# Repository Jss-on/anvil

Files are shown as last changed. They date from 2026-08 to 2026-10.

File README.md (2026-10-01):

# Anvil

**Hardware product development with explicit release gates and revision-bound evidence.**
Version **0.6.0** · Claude Code and Codex plugins · Proprietary license

Anvil carries a product from requirements and architecture through PCB fabrication, firmware,
mechanics, integration, EVT/DVT/PVT, market release, support and retirement. Its commands perform
authorized engineering work and keep missing external tests or approvals visible as blockers.

```mermaid
flowchart LR
  G0["G0 Opportunity"] --> G1["G1 Requirements"] --> G2["G2 Architecture"]
  G2 --> G3["G3 Prototype release"] --> G4["G4 EVT"] --> G5["G5 DVT"]
  G5 --> G6["G6 PVT"] --> G7["G7 Market release"] --> S["Support and retirement"]
  S -->|Controlled changes| G2
```

Electronics, firmware/services, mechanics, supply/manufacturing, quality/compliance and commercial
work proceed concurrently. The [lifecycle protocol](.claude/skills/anvil/references/lifecycle-protocol.md)
defines gates, owners, artifacts and checklists. The [research report](research/hardware-product-lifecycle.md)
and [original assessment](ASSESSMENT.md) explain the upgrade's basis.

## Use with Claude Code

Install the repository's marketplace in Claude Code, then its `anvil` plugin:

```text
/plugin marketplace add Jss-on/anvil
/plugin install anvil@anvil
```

For local development, load the actual packaged directory with `claude --plugin-dir ./claude-plugin`.
The repository's canonical command and skill files also support project-local development.
Do not assume editing this checkout changes an already cached installation; reload the local
plugin or update the installed package after publishing an authorized release.

| Command | Purpose |
|---|---|
| `/anvil` | Bounded custom metric loop or task routing |
| `/anvil:requirements` | Requirements, methods, owners, verification gates and applicability |
| `/anvil:build` | Concurrent product development, default target G3 |
| `/anvil:lifecycle` | Bring-up, EVT/DVT/PVT, market release and sustaining |
| `/anvil:improve` | Cost/area/mass/margin optimization with non-regression checks |
| `/anvil:evals` | Run analysis and evidence/gate review |

Examples:

```text
/anvil:build Goal: battery-powered environmental monitor Release: product Target: G3
/anvil:lifecycle Scope: ./sensor Target: G5 Action: execute
/anvil:improve Metric: bom_cost Scope: ./sensor Iterations: 10
```

## Use with Codex

Install and sign in using the [official Codex CLI setup](https://learn.chatgpt.com/docs/codex/cli).
Install Anvil's engineering tools under [Run the checks directly](#run-the-checks-directly).
From this checkout, register its local marketplace and install the native Codex plugin:

```sh
codex plugin marketplace add .
codex plugin add anvil@anvil
codex -C . --sandbox workspace-write
```

The [Codex marketplace](.agents/plugins/marketplace.json) selects the self-contained package
in [`plugins/anvil/`](plugins/anvil/.codex-plugin/plugin.json). Codex loads its `$anvil` skill;
Claude Code uses the separate marketplace and package above. This follows Codex's
[native plugin and marketplace format](https://learn.chatgpt.com/docs/enterprise/plugin-management).

Start a **new thread** after installation. In Codex CLI or the IDE extension, type `$` to select
Anvil, or paste a prompt such as:

```text
$anvil build Goal: battery-powered environmental monitor Scope: ./build-output/sensor Release: product Target: G3
$anvil lifecycle Scope: ./build-output/sensor Target: G5 Action: review
$anvil improve Metric: bom_cost Scope: ./build-output/sensor Iterations: 10
```

Send one prompt at a time. The skill also routes `requirements`, `evals`, and custom metric
loops. All six workflows use the same engineering protocols, Python checks, receipts and gates
as the Claude Code plugin. In the Codex app, select Anvil and describe the task in a new thread.

To work in an existing hardware repository, launch `codex -C <project-directory>` and use
`Scope: .`; installed Anvil tools resolve from the plugin cache. When working in this checkout,
`build-output/sensor` is ignored by Git; maintain the product's own source history and release
archive. Keep project outputs outside the plugin cache.

For a noninteractive review of an existing project, use single quotes so PowerShell and Bash
preserve the `$anvil` skill mention. See the [Codex CLI reference](https://learn.chatgpt.com/docs/developer-commands?surface=cli).

```sh
codex exec -C . --sandbox workspace-write 'Use $anvil lifecycle Scope: ./build-output/sensor Target: G3 Action: review. Report the actual gate result and blockers.'
```

For development without installation, open this checkout and ask Codex to read
`.claude/skills/anvil/SKILL.md` and the desired `.claude/commands/anvil/<workflow>.md` directly.
Use the checkout's `scripts/` and `templates/`. Installed plugins are cached copies; editing
this repository does not update an existing session.

Scope tailoring supports embedded/connected, robotics/industrial, medical and automotive
products; US, EU, Great Britain, Northern Ireland and Taiwan markets; Taiwan manufacture/export;
firmware, mechanics, radio, battery and cloud features. Classification and dates are reviewed
per product. Selecting a profile does not certify a design.

## Run the checks directly

Python 3.10+ standard library is the core dependency. Git tracks controlled source; KiCad CLI
is needed for ERC/DRC/exports and standalone ngspice for simulation. Use only the CAD, firmware,
HIL and authoring tools the project actually needs. On Windows, `scripts\doctor.cmd` locates
Git Bash; direct `uv run --no-project --offline python scripts/anvil.py ...` also works.

```sh
python scripts/anvil.py doctor --require-build
python scripts/anvil.py init ../sensor --scope product --sectors embedded,connected --markets US,EU --features electronics,firmware,mechanics,radio,battery
# Populate real requirements, artifacts and checks in the generated project.
python scripts/anvil.py plan ../sensor
python scripts/anvil.py manifest ../sensor
python scripts/anvil.py record ../sensor AUTO-ERC
python scripts/anvil.py record ../sensor AUTO-DRC
python scripts/anvil.py gate ../sensor G3
python scripts/anvil.py handoff ../sensor --write build --gate G3
```

Initialization creates incomplete templates and cannot produce a ready verdict by itself. For an
existing hardware project, copy/add the required files individually and preserve its existing work.
See the [CLI contract](.claude/skills/anvil/references/metrics.md) and
[evidence schema](.claude/skills/anvil/references/evidence-protocol.md) for command arrays,
receipts, strict table formats and exit statuses.

## Accuracy and outputs (0.6)

- **Rulebook.** About 12,000 cited rules (0.7; 6,900 in 0.6) extracted from the reference library, in the skill's
  `references/rulebook/`. Sources include IPC-2221C/6012F/A-610J, Brooks & Adam, Bogatin, Coombs & Holden,
  Hall/McCall, Hall & Heck, Archambeault, Williams, Paul, Pressman, Erickson, Pozar, Balanis, Bowick,
  Johnson & Graham (1993, 2003), Horowitz & Hill, Scherz & Monk, Ritchey, Mitzner, Wilson, Stringham, White
  and Cohen, each mined in full. Every rule carries its page, section, table or figure, and
  `bibliography.json` maps rule ids to IEEE references; each file's section 8 lists OCR losses and printed
  errata found while re-checking worked examples.
- **Cited calculations.** `design/rules.tsv` rows run textbook formulas as a gate check (`rules`). They cover
  trace temperature and current, IPC-2221 spacing, fusing, impedance, PDN target and decoupling, converter
  ripple and RHP zero, loop and common-mode radiation, slot shielding, I²C pull-ups, return loss, Friis
  link, patch antenna, thermal and mass.
- **Wired schematics.** `schematic sch/circuit.json pcb/board.kicad_sch` places KiCad symbols, draws real
  orthogonal wires and power symbols, then proves the drawing. KiCad must reload it, the fresh netlist
  must equal the spec, and ERC must be clean. `schematic-spec` converts an existing label-only drawing.
- **Evidence outputs.** `plots` renders ngspice corner waveforms and margin charts. `renders` produces
  schematic and PCB SVG/PDF/3D files. `fabpack` produces Gerber X2, drill, placement, IPC-2581,
  IPC-D-356 and STEP files, with every command logged and hashed.
- **Audit and paper.** `log` keeps iteration, decision and research ledgers for the modify→verify→keep
  loop. `report` writes `audit/AUDIT.md`, `audit.json` and an IEEEtran `paper.tex` with `refs.bib`. Both
  are built from the ledgers, receipts, BOMs and plots.

## Board truth (0.7)

Every board claim is now measured on the copper KiCad itself reports, read through KiCad's own Python with
zones refilled in memory. Nothing is taken from typed numbers.

- **Board, placement, routing.** `board` puts footprints and nets from the schematic onto a template board
  that carries the fabricator's stackup, outline and rules. `place` applies `design/placement.tsv`, and
  `route` runs Freerouting on a copy and checks the result with DRC.
- **Layout.** `layout` checks the routed copper against `design/nets.tsv` and `rf.tsv`:
  - IPC-2152 trace heating (Brooks & Adam fits) and via groups;
  - IPC-2221 spacing to every neighbour net;
  - field-solved Z0 and Zdiff with the real mask and coplanar gaps;
  - return-plane continuity and length matching;
  - RF via-fence pitch, pour stitching, matching-part distance and antenna keep-outs.
- **Signal integrity.** `si` turns each routed net into field-solved transmission lines, including via stubs,
  and simulates it in ngspice. It reports overshoot, ringback, delay and settling at every receiver.
- **Power integrity.** `pdn` computes impedance at the load. Each capacitor's mounted inductance is built from
  the copper: its fanout path, via pair and cavity spreading. Plane capacitance and the VRM are included, and
  the result is checked against Z_target.
- **Thermal.** `thermal` is a layered conduction model of the real copper and via barrels. It gives Tj for
  each part and a heat map.
- **EM.** `em` writes an openEMS FDTD model of the RF path: its nets and ground copper, ports where the
  connector pin or device lead enters each pad (driving the coplanar gaps over a launch cut-out), and the
  matching parts (capacitors as series ESR-ESL-C, inductors with the ESR of their Q). It
  saves Touchstone and plots; a `settled` row fails if the end of the run still moves a checked S-parameter.
  `sparams` applies the same limits to VNA measurements of the built board.
- **EMC estimate.** `emc` multiplies each net's loop area by the clock's trapezoid harmonics and compares the
  result with the FCC and CISPR limit lines.

**Validation.** Every solver is tested against an analytic anchor:

| Solver | Reference | Agreement |
|---|---|---|
| Z0, 2-D field solver | Cohn stripline, Hammerstad–Jensen microstrip | < 1 % |
| Thermal | K0 point source on a plate | < 0.1 % |
| SI | Lattice-diagram overshoot | exact |
| EMC harmonics | Paul's worked example | 0.05 dB |
| EM | 2-D solver on a 50 Ω microstrip | Zin within 1.1 %; ε_eff within 1.6 % (two-length, mean 1.1 %); line loss within 1.5 % of the analytic dielectric loss; \|S12 − S21\| < 3e-5 |
| EM, coplanar launch port | 2-D solver on a CPW over a 1.53 mm ground (an SMA pad over a cut-out) | Z0 from the S-matrix within 0.22 % over 1–3 GHz; S11 < −27 dB to 4 GHz; \|S12 − S21\| < 2e-3 |
| EM, antenna mode | Balanis patch design; cos² feed law | resonance within 3.2 % (mesh-converged to 0.15 %); feed law within 1 % |

**Still physical.** VNA measurement of RF paths, antenna pattern and efficiency, chamber EMC, and thermal
validation at EVT.

## Readiness means evidence

- All **75 research checklist items** are bundled, with **19 early applicability checkpoints**.
  Planning adds applicable automatic checks and every project requirement; deleting a required
  ledger row cannot improve readiness.
- `pass-rate` and `coverage` are diagnostics. `gate` requires exact due checks, matching methods,
  scoped artifacts, current file hashes and substantive review/external records.
- G3 distinguishes `PCB_FAB_READY`, `ASSEMBLY_READY` and `PRODUCT_BUILD_READY`. G5 is
  `DESIGN_QUALIFIED`, G6 `PRODUCTION_READY`, and G7 `MARKET_READY`. Earlier gates remain required.
- KiCad reports must come from successful fresh runs with valid schemas and active adjacent
  rule/project files. Simulation runs every declared corner and never falls back to old logs.
- BOM/cost/mass/budget and wiring inputs have strict numeric and source-join checks. Firmware
  and factory records identify builds, unit revisions, fixtures/calibration, attempts and rework.
- Changed design inputs invalidate G3+ evidence. Handoffs recompute the actual verdict and
  include blockers; stale or unsupported readiness is rejected before chaining.

Physical measurements, factory qualification and legal/customer approvals must come from actual
execution and responsible reviewers. Anvil verifies record structure and file integrity; it does
not authenticate approval identities, certify products, or replace a regulated quality system.
The filesystem receipt model assumes trusted editors; externally signed records/access controls
are needed where adversarial tampering or authenticated approvals are in scope.

No remote publication, supplier contact, purchase, hardware energization, firmware deployment,
filing or shipment happens without the session's authorization for that action. Local work and
reviewable packages proceed without repeated permission requests.

Optional failure triage is available with `Jev: shadow` in build/evals. The
[Jev triage guide](.claude/skills/anvil/references/jev-triage.md) describes the finding packet,
`TYPESAFE_API_KEY` or hidden `--prompt-key` input, and the standalone
`python -B scripts/jev_triage.py finding.json` command. It emits advisory JSON and never writes
designs or release evidence. The network client is separate from the hashed gate engine.
For a small live diagnostic replay, use
`python -B evals/jev/pilot.py cases.json new-run-directory --prompt-key`.

## Migrate from 0.4

1. Archive the old ledger as history. Add `anvil-project.json`, structured
   `hrs/requirements.tsv`, complete artifact roles and explicit check command arrays.
2. Run `plan`; migrate a prior observation only after its actual input/configuration, execution
   and review provenance is established. Old `evidence:path` strings are not receipts.
3. Put `<board>.kicad_dru` beside its matching PCB/project/schematic. A nested `pcb/rules/`
   deck is inactive. Only the reviewed JLCPCB two-layer starter is bundled.
4. Add `circuit` to simulation rows. Declare each swept parameter on its own `.param` line.
   `SKIP_NGSPICE` and implicit cached logs are rejected.
5. Replace subsystem-only ICD endpoints with physical pins, qualified ratings, voltage/protocol
   and mate pin lists. Product BOM `source` becomes `relative.csv#item_id`; budget sources use
   `relative.json#key` with explicit value and units. Record firmware/build and factory evidence.
6. Generate the release manifest, record/review checks, and run `gate`. Legacy `verdict <tsv>`
   stays `FAB_BLOCKED`. Renew affected receipts after configuration changes.

## Develop and verify

Canonical sources: `.claude/commands/`, `.claude/skills/anvil/`, `scripts/` and `templates/`.
`claude-plugin/` and `plugins/anvil/` are their byte-for-byte installable mirrors for Claude Code
and Codex. Edit canonical files, then sync. Each package has its own native manifest.

```sh
python -B tests/test_anvil.py
bash scripts/sync-plugin.sh
bash scripts/sync-plugin.sh --check
bash scripts/score-e2e-capability.sh
```

For local Codex updates, use `$plugin-creator` to refresh Anvil from this checkout's `anvil`
marketplace. Its update flow adds a version cachebuster and reinstalls the plugin; start a new
thread afterward. The base version stays aligned with `VERSION`.

Tests cover valid observations and the assessment's negative cases, cumulative lifecycle gates,
stale receipts/handoffs, sector/market tailoring, firmware/cost/factory records and both isolated
installed payloads, including workflow links. CI runs the Python contracts on Linux and Windows
and verifies both packages.
Optional native checks run with `ANVIL_NATIVE_TESTS=1` when KiCad/ngspice are installed.
`score-e2e-capability.sh` runs executable software checks; it no longer reports grep matches
as end-to-end physical product capability.

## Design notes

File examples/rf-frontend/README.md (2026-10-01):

# rffe — Anvil showcase: 2.4 GHz gain block + 25 MHz reference clock

A complete Anvil project, taken from requirements to recorded G3 evidence. Every number below was produced by
Anvil's own commands on the KiCad files in this folder. Each one is quoted from a hashed receipt in `evidence/`;
none are typed in.

**Board:** 4 layers, 50 × 36 mm.
- **RF chain:** J1 → C1 → U2 (Mini-Circuits GALI-84+) → C2 → J2, on 50 Ω grounded-coplanar lines over the In1
  ground plane. The edge-launch SMA pads reference B.Cu through cut-outs in In1 and In2.
- **Bias tee:** 22 nH choke, 3 × 220 Ω 2512 from 12 V, 10 pF + 100 nF bypass.
- **Clock:** a 25 MHz oscillator drives a 33 Ω series-terminated SMA output.
- **Supply:** an AMS1117 makes +3V3 on an In2 plane.

> Showcase design. The GALI-84 and AMS1117 bias, θjb and output-impedance values are datasheet typicals
> marked "to confirm". This is not a product release.

## Reproduce

```sh
python tools/pipeline.py                         # schematic -> template -> board -> place + RF pre-routes -> Freerouting + DRC
python ../../scripts/anvil.py rules design       # cited sizing calculations
python ../../scripts/anvil.py layout  pcb/rffe.kicad_pcb design
python ../../scripts/anvil.py pdn     pcb/rffe.kicad_pcb design
python ../../scripts/anvil.py si      pcb/rffe.kicad_pcb design
python ../../scripts/anvil.py thermal pcb/rffe.kicad_pcb design
python ../../scripts/anvil.py emc     pcb/rffe.kicad_pcb design
python ../../scripts/anvil.py em      pcb/rffe.kicad_pcb design   # openEMS, ~50 min (4 port runs)
python ../../scripts/anvil.py fabpack pcb/rffe.kicad_pcb fab && python ../../scripts/anvil.py renders .
python tools/write_ledgers.py && python tools/declare_release.py
python ../../scripts/anvil.py plan . && python ../../scripts/anvil.py manifest . && python ../../scripts/anvil.py record . AUTO-...
python ../../scripts/anvil.py gate . G3 && python ../../scripts/anvil.py report .
```

`tools/` holds the project-specific steps an engineer or agent would script:
- `size_rf_line.py`: field-solver width/gap table.
- `make_template.py`: stackup, outline, planes and the SMA launch cut-outs.
- `make_routes.py`: RF lines, clock line, fence, launch/thermal/stitching vias and plane fanouts, all computed from
  the placed pads.
- `place_schematic.py`: functional sheet layout.
- `declare_release.py`, `write_ledgers.py`.

## What the loop found and fixed (`audit/iterations.tsv`)

| # | Found by | Problem | Fix |
|---|---|---|---|
| 1 | `schematic` | Netlist mismatch on the first run only | Generator nondeterminism (set order); fixed in Anvil, regression test added |
| 2 | `drc` | 137 → 20 violations: edge-launch pads, zone islands, silkscreen | SMA pull-back, scoped edge rule, island removal, placement |
| 3 | `drc` | Floating +3V3 plane, fragmented ground pour | Plane fanouts and stitching pre-routed |
| 4 | `layout` | RF fence gaps and pour tips beyond λ/10 and λ/20 at 5 GHz | Greedy fence, launch vias, gap-fill stitching: 58/58 |
| 5 | `rules` | Bias resistors at 51.6 % of rating at 13.2 V (2× derating, WILSON-394) | 2 × 150 Ω → 3 × 220 Ω: 35 % |
| 6 | `thermal` | GALI-84 at 130.3 °C against a 130 °C limit after the extra resistor | R1 moved, 2 × 3 thermal vias: 129.0 °C |
| 7 | `si` | ngspice stalled on sub-ps line fragments | Fixed in Anvil: fragments below the time step are merged |
| 8 | `em` | openEMS field energy never decayed (a −11 dB plateau), so no S-parameters | Fixed in Anvil (below) |
| 9 | `em` | SMA centre pad (1.5 mm) over In1 at 0.2 mm is an 18 Ω section: `rf_in` S11 −6.8 dB, S21 −1.26 dB | In1/In2 cut-out under the J1/J2 centre pads (JOHNSON03-1307): the pad references B.Cu, 47.8 Ω; S11 −15.9 dB |
| 10 | `rules` + `em` | 100 pF DC blocks are 8.8 Ω *inductive* at 2.5 GHz: far above their self-resonance | 10 pF C0G, series-resonant near the band: 3.1 Ω (BOGATIN-2128, ARCH-067) |
| 11 | `em` | S11 then read −14.95 dB with Zin 42 + j14 Ω: the inductive 100 pF had been masking the launch *port's* own inductance, a 1.5 mm tall sheet down to B.Cu | Fixed in Anvil: over a cut-out the port drives the coplanar gaps (validated against the 2-D solver); S11 −17.1 dB |

Iteration 8 was diagnosed with 16 point field probes and truncated-record comparisons, not the energy log. The
port signals had decayed 50 dB while the "energy" stayed flat. Removing the ideal 100 pF lumped capacitor let the
model converge: spread over the mesh, an ideal C rings losslessly. The EM engine now:
- models capacitors as series ESR-ESL-C;
- models only the analysed and ground nets;
- places each port where the pin or lead enters its pad;
- runs to −50 dB;
- reports a `settled` row, so an unconverged result cannot pass.

The first converged run then exposed iteration 9, a real layout flaw that every earlier check had passed.
Iteration 11 is the loop checking its own instrument: a model artifact, found because the numbers moved the
wrong way after a change that should have helped, then fixed and validated before the result was trusted.

## Results

Receipts bind release `da83c6a3…` (`release-manifest.json`, 33 controlled files) and the checker code.

| Check | Result | Tightest margin |
|---|---|---|
| AUTO-ERC / AUTO-DRC | 0 / 0 violations | KiCad 10.0.5 on the release files |
| AUTO-CONNECTIVITY | 5/5 | netlist equals `sch/circuit.json` |
| AUTO-SIM | 2/2 | bias-node ripple −15.1 dB at 100 kHz (worst corner) against −3 dB |
| AUTO-RULES | 11/11 | DC block 3.06 Ω against 5 Ω; bias current 103.6 mA in 100 ± 10 mA |
| AUTO-LAYOUT | 58/58 | RF Z0 50.0 Ω; fence ≤ λ/10 and stitching ≤ λ/20 at 5 GHz |
| AUTO-PDN | 1/1 | +3V3 Zmax 0.80 Ω against 1.65 Ω |
| AUTO-SI | 4/4 | CLK_OUT ringback 9.8 % against 20 %; settled in 0.55 ns against 5 ns |
| AUTO-THERMAL | 5/5 | U2 junction 129.0 °C against 130 °C (thin: confirm at EVT) |
| AUTO-EMC | 2/2 | CLK_OUT 32 dB under CISPR 32 Class B, 26 dB after the 6 dB design margin |
| AUTO-EM | not yet recorded | `rf_in` probe passes: S11 −17.1 dB (limit −15), S21 −0.21 dB (limit −0.6). `rf_out` diverges in openEMS 0.37 (below) |

**Open issue: `rf_out`.** With the bias tee in the model, every run diverges after the pulse: the energy decays to
about −20 dB, then grows without bound from roughly 30k timesteps. Bisection so far:
- Any single series-type lumped part triggers it, the choke alone or the capacitors alone, even though each is
  stable in a small test model.
- Collapsing the parts to single-edge lines does not help, and neither does cutting the bias feed at the region
  edge.

The all-resistor control run had not finished when this snapshot was taken. Anvil rejects a diverged run
(NaN energy or non-finite port signals) instead of reporting it, so AUTO-EM stays open until `rf_out` converges.

Figures: `analysis/em/*.png` (S-parameters against the limits), `analysis/layout/copper-*.png`,
`analysis/thermal/thermal.png`, `analysis/pdn/pdn-_3V3.png`, `analysis/si/si-CLK_OUT.png`,
`analysis/emc/emc-cispr32_b.png`, `audit/plots/P-1.png` (bias ripple at the tolerance corners).

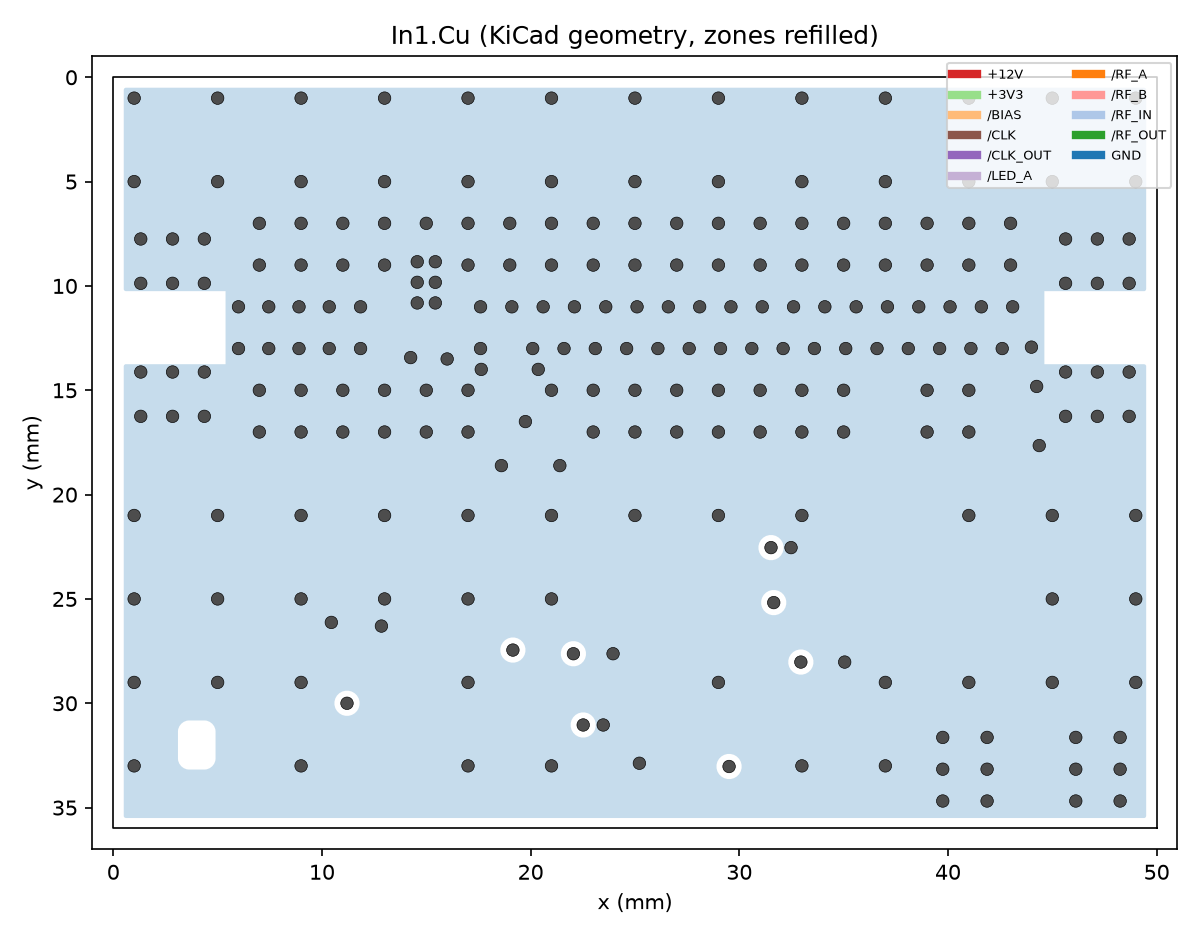
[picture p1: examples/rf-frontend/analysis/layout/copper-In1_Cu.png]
In1 with the SMA launch cut-outs


## Gate

`anvil.py gate . G3` returns `G3_BLOCKED`: AUTO-EM (above) and the 41 human sign-offs:
- 2 G0 opportunity reviews;
- 15 G1 requirement and compliance-plan reviews;
- 6 G2 architecture reviews;
- 8 G3 release reviews;
- 10 requirement closures (REQ-HR-001 … 010).

Anvil will not record an approval it would have to invent. A reviewer closes each one in three steps:
1. `anvil.py prepare . <check> <evidence files>`
2. Fill in reviewer, role, decision and record.
3. `anvil.py record . <check> --evidence evidence/<check>.draft.json`

## Audit documentation

- `audit/AUDIT.md` and `audit/audit.json`: requirements, 11 research sources, 9 decisions, 12 iterations, every
  receipt with its transcript and margins, the BOM, figures, the release manifest and IEEE references.
- `audit/paper/paper.tex` + `refs.bib`: IEEE conference skeleton with the requirement, decision, execution, margin
  and iteration tables and every verification figure. The prose sections are for the author.
- `fab/`: gerbers, drill, placement, IPC-2581, IPC-D-356 test netlist, STEP; `audit/renders/`: schematic PDF/SVG,
  board SVG/PNG.

## What stays physical

- VNA S-parameters of the built board (HR-011 at G4). The EM model has no SMA body, solder mask or conductor loss,
  and its lumped launch port stands 1.5 mm tall.
- The gain block's own S-parameters, from the vendor file, not from copper.
- Chamber EMC: the emission figure is an estimate (±10 dB).
- A thermocouple or IR check of U2: the thermal margin is under 1 °C in the model.

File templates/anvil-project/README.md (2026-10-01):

# Anvil project

These templates start unverified. Fill the actual product profile, `hardware_revision`,
requirements, artifact paths and check arrays before running `plan`. Never treat empty rows
or placeholder values as completed evidence. Resolve the Anvil executable from the installed
plugin; this project does not contain its scripts.

| Path | Purpose |
|---|---|
| `anvil-project.json` | Scope, sectors, destinations, features, requirements, controlled artifacts and check commands |
| `hrs/requirements.tsv` | Stable requirements, objective criteria, conditions, methods, due gates and owners |
| `lifecycle-checks.csv` | Reference copy of the 75 research items plus early planning checkpoints; the installed catalog controls gates |
| `pcb/rules/` | Starter deck; copy to `<board>.kicad_dru` beside the actual PCB/project/schematic to activate |
| `sim/assertions.tsv` | Exact harness, measure, comparison, units, corners and requirement traces |
| `sim/plots.tsv` | Corner waveform plots for the audit package (`plots`) |
| `sch/circuit.json`, `sch/connectivity.tsv` | Golden netlist for the wired `schematic` generator; wiring assertions incl. `golden` |
| `design/rules.tsv` | Cited sizing calculations (`rules`): every value traces to a rulebook id |
| `audit/` | Iteration, decision and research ledgers (`log`) and the generated report/paper (`report`) |
| `system/`, `harness/` | Physical interface endpoints, sourced budgets, wires and explicit mating pin definitions |
| `bom/`, `catalog/` | Exact source joins for product cost/mass, including mechanical and COTS parts |
| `mech/` | CAD-derived measurements and fit/mass/process assertions |
| `firmware/` | Controlled source/build/dependencies/binary and compatibility/security records |
| `manufacturing/` | Control plan, pilot acceptance and per-unit test/provisioning/rework records |
| `compliance/` | SKU/destination applicability, dates, route, evidence and responsible owners |
| `commercial/` | Complete cost model and sourced assumptions for commercial review |
| `sustaining/` | Configuration changes, field/production incidents, support and retirement evidence |
| `evidence/` | Actual tool receipts and imported reviewed/external records |

Add the actual schematics/PCBs, libraries/models, firmware/CAD sources, controlled drawings,
fabrication/assembly exports, reports and procedures under these or other explicit paths.
Every release dependency enters `artifacts`; manifest files use portable relative paths.
Prepare G0 opportunity, G1 requirements and G2 architecture reviews before G3 prototype release.
Continue through G4 EVT, G5 DVT, G6 PVT, G7 market release and sustaining as the target requires.

```sh
python /installed/anvil/scripts/anvil.py plan .
python /installed/anvil/scripts/anvil.py manifest .
python /installed/anvil/scripts/anvil.py record . AUTO-ERC
python /installed/anvil/scripts/anvil.py gate . G3
python /installed/anvil/scripts/anvil.py handoff . --write build --gate G3
```

Use the installed lifecycle/evidence protocols to populate review receipts. Physical tests and
approvals must be real; templates contain no fabricated measurements or approvals. Changing a
release file invalidates G3+ evidence. A blocked gate identifies unfinished work, not permission
to drop its requirements.

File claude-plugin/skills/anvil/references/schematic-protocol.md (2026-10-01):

# Schematic and electrical verification

Keep the source diffable and reproducible: native `.kicad_sch`, SKiDL, or another selected
authoring flow with pinned tools/libraries. Native KiCad does not require SKiDL or kiutils.
Use hierarchy by function, unambiguous net names, deliberate power and ground topology, visible
decoupling/protection, and source-linked part choices. Follow the actual component datasheet
for unused pins, power flags, grounding, bias, reset/boot states and recommended circuitry.

Before creating connectivity, derive golden assertions from requirements and the ICD: exact
net/pin membership, power/return paths, enable/reset straps, interface direction/voltage, required
protection, sensing and test points. Parse exported netlists where possible; retain substantive
review evidence for properties requiring inspection. A grep hit for a net name is insufficient.

Check footprints against manufacturer drawings, tolerances, pad/pin numbering, exposed-pad
paste/thermal strategy and assembly process. Pin project-local symbol/footprint/model libraries.
For each part stress, record worst-case applied value, actual rating under conditions, ratio,
selected derating criterion and source. Include DC-bias capacitance, temperature/power, ripple,
transients and duty cycle where relevant. No universal 80-percent derating satisfies all parts.

## Wired drawings from a golden netlist

`sch/circuit.json` is the design intent: `{"schema_version": 1, "project", "title", "rev", "parts": [{"ref",
"symbol": "Lib:Name", "value", "footprint", "fields", "unit", "at": [x_mm, y_mm] (optional), "rot", "dnp"}],
"nets": {"NAME": ["R1.1", "U1.4"]}, "power_nets": [...], "pwr_flag": [...], "libraries": {"Nick": "path.kicad_sym"},
"notes": [{"text", "at"}]}`. Omitted coordinates are auto-placed next to the pin each part connects to.
`anvil.py schematic sch/circuit.json pcb/<board>.kicad_sch` vendors the symbols into a project library,
routes every signal net with orthogonal wires (never through pins, nodes or collinear with another net;
crossings only straight through), draws rails with power symbols, names each net with one label, marks
unused pins NC, reloads through KiCad, and fails unless the fresh netlist equals the spec and ERC has no
errors. A link the router cannot draw falls back to a same-name label and is listed in `<board>.wiring.json`
(`wired_fraction`, `unrouted`, `crossings`): improve placement and regenerate until it is 1.0. Render and
view the sheet; readability is part of review. Add a `golden` row to `sch/connectivity.tsv` so hand edits
are re-proven at every gate.

Execute `erc <schematic>` and capture a receipt through `record AUTO-ERC`. KiCad's real JSON
schema, successful execution and all reported findings are checked. Review project rule severity
and exclusions; resolve issues without globally suppressing the class. SKiDL ERC is useful
when SKiDL is used but does not replace checking the actual released KiCad schematic.

Review power budgets/sequencing, pull-ups and bus capacitance, oscillators, decoupling/return
paths, protection, safe defaults, programming/debug, calibration and production-test access.
Export and view every schematic page; retain the render and actual review. ERC does not prove
component values, circuit function, assembly orientation or safety compliance.

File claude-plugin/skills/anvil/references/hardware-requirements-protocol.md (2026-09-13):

# Hardware and product requirements

Requirements are the common contract for hardware, firmware, mechanics, manufacturing,
compliance and support. Start with intended use, users, operating environment, market variants,
production location, expected volume/life and commercial stop criteria. Record goals, constraints,
hazards, assumptions, ownership, rationale and exclusions in `hrs/requirements.md`.

## Authoritative table

`hrs/requirements.tsv` columns: `id`, `statement`, `units`, `conditions`, `method`, `gate`, `owner`.

```text
id	statement	units	conditions	method	gate	owner
HR-1	3V3 output stays within 3.3 V +/- 3 percent	V	Vin 4.5..5.5 V; load 0..1 A; Ta -10..60 C	simulation	G3	Power lead
HR-2	Recovers to safe outputs after brownout within 100 ms	ms	Production-intent board; min/max input ramp; worst load	test	G5	Firmware/test lead
HR-3	Every supported SKU has approved destination labeling	boolean	All release markets and languages	inspection	G7	Regulatory owner
```

Each quantitative statement names limit direction, value/tolerance, units and conditions.
Qualitative requirements use observable pass/fail criteria, with `boolean` or another meaningful
unit instead of invented numbers. `owner` is accountable for closure; `gate` is the verification
due date in the lifecycle. Methods are test, simulation, analysis and inspection. Select the
method that answers the claim, not a universal hierarchy or the easiest available tool.
Split mixed claims into separate requirements when they need different methods or gates.

Stable `HR-n` IDs never change meaning or get silently reused. Retired requirements and their
reasons remain in the controlled history; removing an active row requires an impact review.
`plan` creates `REQ-HR-n` checks. `coverage` checks exact trace links and rejects orphan IDs;
it does not validate prose measurability or prove that planned tests were executed.

## Elicitation checklist

1. Function/performance and intended-user tasks, including startup, degraded behavior and misuse.
2. Supply range, transients, sequencing, inrush, reverse input, brownout, quiescent and load power.
3. Interfaces at both endpoints: physical pin, direction, voltage/current, timing/protocol,
   protection, connector/mate, shielding, mechanical datums and firmware ownership.
4. Mechanics: envelope, tolerances, mounting, material/process, thermal path, sealing, service
   access, strain relief, wear parts, assembly and packaging. Specify actual ingress/test profiles.
5. Environment/reliability: temperature, humidity, vibration/shock/drop and lifetime/duty cycle
   with a justified test method and acceptance limits. Avoid generic claims such as "rugged".
6. Firmware/services: boot, partitions, timing/memory/power, watchdog/fault states, identities,
   credentials, updates/recovery, offline/cloud behavior, diagnostics, privacy and support duration.
7. Safety/security: hazard analysis, risk controls, access/maintenance states, threat model,
   required residual-risk acceptance, verification and reporting responsibilities.
8. Manufacturing/supply: fabricator/process capability, quality/acceptance class and edition,
   yield, test coverage, calibration, traceability, repair/rework, alternates and lifecycle risks.
9. Compliance/market: intended-use classification, SKU destinations, dates, conformity route,
   evidence, labels/languages/operators, transport, environmental/producer and post-market duties.
10. Commercial/service: cost at volume, NRE, price/margin, capacity, working capital, logistics,
    warranty/returns, spares, support funding, customer communication and retirement.

A part number mandated by the customer is a constraint with provenance; other parts are design
choices. A quality class, derating factor, clearance or test sample count must be selected for
the actual product/process/risk. Neither "medical" nor "above 30 V" determines these by itself.

G1 review covers the requirements baseline, classification and verification plan. Later physical
requirements stay not_run until their due gate; this is expected, and is different from pretending
their tests passed. Unknowns get an owner, consequence and next experiment. Work continues on
independent tasks while a consequential product decision is pending.

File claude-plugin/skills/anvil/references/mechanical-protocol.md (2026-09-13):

# Mechanical design and verification

Use the project's selected CAD tool and pinned source/parameters. build123d, CadQuery,
OpenSCAD or native controlled CAD can be used; do not require an unrelated kernel for a
native/imported workflow. Keep source, datums, coordinate transforms, materials and process
specification, tolerance drawings and export settings alongside STEP/STL/manufacturing outputs.

Design enclosure/frame and assembly interfaces with electronics and harnesses: connector
access/retention, mounting, component heights, board tolerances, thermal paths, strain relief,
sealing, EMC/shield bonds, sensor alignment, moving-part clearance, tools and service access.
Risk and actual application determine shock/vibration/ingress and wear requirements. Neither
isolation mounts nor a particular wall thickness is universally appropriate.

Generate `mech/measures.json` with finite numeric measurements, optionally nested objects
referenced by dotted keys. `mech/assertions.tsv` columns are `id,class,measure,op,limit,units,
traces` separated by tabs; class is fit, mass or dfm. Every selected class must have assertions.
Examples: maximum interference volume, minimum clearance under tolerance stack, mass ceiling,
minimum process feature and tooling access. A null measurement is an error, not zero clearance.

`fit`, `mass` and `mech-dfm` compare those measurements. Include CAD source, generator/tool
version, command/transcript, material/density, units and actual model/measure outputs in the
review and manifest. A JSON number is not proof that a CAD kernel ran or that the physical part
fits. HW-013/HW-015/HW-017 reviews bind the measures to the model and selected process.

`mesh` checks STL structure, finite vertices, degenerate triangles, edge manifoldness and
orientation. Its passing result does not establish absence of self-intersections, minimum wall
thickness, collision-free assembly, tolerance feasibility or process suitability. Use the CAD
kernel/process tooling for those checks and retain actual results. Slicer/CAM runs must be
executed explicitly with pinned profiles; Anvil does not silently run a slicer on imported STL.

G4/G5 validate physical fit, fastener torque/retention, material behavior, thermal path,
ingress/dynamics and service operation on identified samples. G6 validates tooling, fixtures,
critical dimensions, inspection/measurement capability and assembly process. Preserve rework,
nonconformances and sample/configuration differences from production intent.

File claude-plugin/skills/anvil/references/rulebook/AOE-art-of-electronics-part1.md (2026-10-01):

# The Art of Electronics (3rd ed.), part 1 of 4 — Anvil rulebook

## 0. Citation

P. Horowitz and W. Hill, *The Art of Electronics*, 3rd ed. Cambridge, U.K. / New York, NY, USA: Cambridge University Press, 2015 (first ed. 1980, second ed. 1989). ISBN 978-0-521-80926-9 (hardback). www.cambridge.org/9780521809269.

BOOKTAG: AOE. This file is **part 1 of 4** (source text lines 1–19000 of `refs-text/Paul_Horowitz_Winfield_Hill_The_Art_of_Electronics_2015_Camb.txt`, 75,879 lines; finished through the end of §5.10.1 at line 19365 because Table 5.5 straddles the boundary). Rule ids AOE-1001 … AOE-1345 (345 rules). Parts 2–4 use AOE-2001…, AOE-3001…, AOE-4001….

**Chapters covered by this extraction (read in order):**
- Front matter: contents, list of tables, prefaces to the 1st/2nd/3rd editions, legal notices (lines 1–3167; orientation only, no rules).
- Ch.1 Foundations (pp.1–70): voltage/current/resistance, dividers, Thevenin, zeners, signals and decibels, capacitors and RC circuits, inductors and transformers, diodes/rectifiers/clamps/inductive kick, impedance and reactance, RC and LC filters, an AM radio, switches, relays, connectors, indicators, variable components, markings and SMT.
- Ch.2 Bipolar Transistors (pp.71–130): switches, followers, current sources, CE amplifiers, Ebers–Moll rules of thumb, mirrors, differential amplifiers, push-pull, Darlington/Sziklai, bootstrapping, paralleling/ballasting, Miller effect, negative feedback, example circuits, review.
- Ch.3 Field-Effect Transistors (pp.131–222): FET characteristics and spreads, JFET sources/amplifiers/followers/variable resistors, gate current, analog switches and their limitations, CMOS logic, power MOSFETs (gate charge, ratings, body diode, ESD, paralleling, thermal runaway), IGBTs/thyristors, depletion-mode circuits, Tables 3.1–3.8, review.
- Ch.4 Operational Amplifiers (pp.223–291): golden rules, basic circuits, cautions, smorgasbord (boosters, regulator, comparators, Schmitt, rectifiers, oscillator), op-amp limitations and their effects, peak detector/S-H/clamp/integrator/differentiator, single-supply operation, capacitive loads, rail splitters, typical circuits, frequency compensation, Tables 4.1–4.2b, review.
- Ch.5 Precision Circuits, §5.1–§5.10.1 (pp.292–322): error budgets, the precision millivoltmeter, unspecified parameters, autonulling amplifier error budget, component errors (resistors, hold capacitor leakage and dielectric absorption, nulling switch), amplifier input errors (Z_in, I_B, V_os, CMRR, PSRR), output errors (slew, settling, crossover, output impedance, gain error, gain nonlinearity, phase error and active compensation), RRIO pitfalls, choosing a precision op-amp (Tables 5.1–5.5).

**Not read in this part (with reason):** Ch.5 from §5.10.2 onward, Chapters 6–15, Appendices A–P and the index — outside the assigned line range (lines 19000–75879 are assigned to parts 2–4). Within the range nothing was skipped except the end-of-chapter "Additional Exercises" (problem sets; skimmed for embedded data only) and the pure-math complex-number derivation in §1.7.3–1.7.4 (results kept).

**Notation / OCR conventions.** The OCR renders micro as "m", "j", "/i", "|j" and ohm as "Q", "£2", "O", "fi"; values were converted to SI from context (uA, uV, uF = micro-units; ohm, kohm, Mohm). "C" after a number = degrees Celsius. "rtHz" = square root of hertz. Cells marked "(as read)" or "OCR-reconstructed" came from scrambled table columns and should be verified against the printed book before being used as hard limits. Page numbers are the printed page numbers (p.NNN).

## 1. Design rules

| id | domain | rule statement | formula / limit (units) | inputs | applicability & conditions | verify by | source | conf |
|---|---|---|---|---|---|---|---|---|
| AOE-1001 | components | Chip-component size codes: the 4-digit inch code gives each dimension in units of 0.010 in (0.25 mm); the metric code uses units of 0.1 mm, sometimes without saying so. 0805 (inch) = 2.0 x 1.25 mm = 80 x 50 mil = "2012" metric; 0402 inch = 1005 metric; 0201 inch = 0603 metric; 01005 inch = 0402 metric = 0.4 x 0.2 mm (0.016 x 0.008 in). Height is specified separately. State inch vs metric explicitly on every footprint/BOM line | inch code AABB: L = 0.254*AA mm, W = 0.254*BB mm; metric code: L = 0.1*AA mm, W = 0.1*BB mm | package code, code system | SMT passives; footprint/BOM consistency | inspect | p.4 fn7; p.65 Fig 1.132 | high |
| AOE-1002 | derating | The generic RN55D 1% metal-film axial resistor is rated 1/8 W in its MIL-spec RN55 grade but 1/4 W in its CMF-55 industrial grade; derate against the conservative (MIL) rating when the grade is unknown | P_rated(RN55) = 0.125 W; P_rated(CMF-55) = 0.25 W | resistor grade | axial metal-film resistors | review | p.4 fn8 | high |
| AOE-1003 | components | Resistor catalog ranges: 0.0002 ohm to 1e12 ohm; standard power ratings 1/8 W to 250 W; tolerances 0.005 % to 20 %. Common film types come 1 ohm to 10 Mohm in 5 %, 2 %, 1 %; the 1 % series has 96 values/decade, the 2 % and 5 % series 24 values/decade | E96 = 96 values/decade (1 %); E24 = 24 values/decade (2 %, 5 %) | tolerance class, value | resistor value selection | inspect | p.4-5 box "Resistors"; App. C | high |
| AOE-1004 | components | Trim a resistor by combination: to trim DOWN, choose the next standard value above target and parallel a much larger resistor (100x in parallel lowers the value by 1 % with only 0.01 % error); to trim UP, choose a value below target and add a much smaller series resistor | R_eff = R*Rp/(R+Rp) ~ R*(1 - R/Rp); R_eff = R + Rs | target, available values | fixed-value trimming | calc | p.6 Shortcut #1, fn10 | high |
| AOE-1005 | components | Do not design to many significant figures: resistors are typically +/-5 % or +/-1 %, capacitors +/-10 % or +/-5 %, transistor parameters often known only to a factor of 2. A good design is insensitive to the precise values of its components (run tolerance corners) | tol_R = 1-5 %; tol_C = 5-10 %; transistor params within x2 | component tolerances | all analog design | sim | p.6 | high |
| AOE-1006 | derating | Resistor dissipation P = I*V = I^2*R = V^2/R must not exceed the (derated) rating. Example: no resistor > 1k can exceed 1/4 W across a 15 V supply (225 mW max) | P = V^2/R <= P_rated_derated | V across R, I, R | every resistor | calc | p.6 §1.2.2C, Ex.1.5 | high |
| AOE-1007 | components | Millman's theorem for passive summing networks: Vout = sum(Vi*Gi)/sum(Gi), Gi = 1/Ri | Vout = (sum Vi/Ri)/(sum 1/Ri) | Vi, Ri | resistive summing/averaging nodes | calc | p.6 fn11 | high |
| AOE-1008 | components | Unloaded divider Vout = Vin*R2/(R1+R2). Thevenin equivalent: VTh = Vin*R2/(R1+R2), RTh = R1*R2/(R1+R2). A divider is a poor ("soft") voltage source; loaded output = VTh*RL/(RL+RTh). Example: 10k-10k from 30 V = 15 V behind 5k | eq 1.6, 1.8, 1.9 | R1, R2, RL, Vin | resistive dividers used as bias/reference | calc | p.7-11 §1.2.3, 1.2.5 | high |
| AOE-1009 | power | Battery source models: 9 V alkaline ~ ideal 9 V in series with 3 ohm, ~3 A short-circuit (kills the battery in minutes). D cell: 1.5 V, ~0.25 ohm series resistance, ~10,000 W*s energy; at end of life ~1.0 V with several ohms | Rs(9 V alkaline) = 3 ohm; Rs(D) = 0.25 ohm fresh, several ohm at EOL; E(D) ~ 1e4 J | battery type, load current | battery-powered designs (droop at peak load, EOL) | calc | p.8-9 §1.2.4 | high |
| AOE-1010 | test | Meter loading: DMMs present 10 Mohm to 1000 Mohm on voltage ranges (some 1e9 ohm on 0.2 V and 2 V ranges but only 1e7 ohm on higher ranges - read the spec); a VOM is 20,000 ohm/V (50 uA movement). Compute the reading error with the divider equation. Current ranges impose a 0.1-0.25 V burden at full scale | Vread = VTh*Rin/(Rin + RTh); burden = 0.1-0.25 V at full scale | meter Rin per range, node RTh | bench measurements, test procedures | calc | p.10 box "Multimeters" | high |
| AOE-1011 | test | Never put an ammeter (or ohmmeter) directly across a voltage source such as a wall plug to "measure its current" - leading cause of blown meters | n/a | test procedure | bring-up/test instructions | review | p.10 box | high |
| AOE-1012 | components | Avoid circuit loading: make the load resistance large compared with the source (Thevenin) resistance of what drives it. Exceptions: a current source (high internal R) should drive a relatively low-R load; transmission lines/RF must be matched (R_load = R_internal = Z0) to prevent reflection and loss | V_out/V_oc = RL/(RL + Rs); target RL >> Rs | RL, Rs | every interstage connection | calc | p.11 §1.2.5A, fn15; p.69 Review G | high |
| AOE-1013 | matching | Maximum power transfer to a load occurs at R_load = R_source; ordinary signal circuits are instead designed with R_load >> R_source | P_load max at RL = Rs | RL, Rs | power/RF matching | calc | p.11-12 §1.2.5B | high |
| AOE-1014 | power | Zener shunt regulator small-signal behavior is a divider with the zener's dynamic resistance: dVout = dVin*Rdyn/(R + Rdyn) = Rdyn*dIz. Worked example: 1N4733 (5.1 V, 1 W), Vin 15-20 V, R = 300 ohm -> Iz(max) = (20-5.1)/300 = 50 mA; Rdyn(max) = 7.0 ohm at 50 mA; Iz falls to 33 mA at 15 V; dIz = 17 mA gives dVout = 0.12 V | dVout = Rdyn*dIz; Iz = (Vin - Vz)/R - I_load | Vin range, R, Vz, Rdyn, I_load | zener regulators/references | calc | p.12-13 §1.2.6A, Fig 1.16 | high |
| AOE-1015 | components | Zener dynamic resistance varies roughly inversely with current. Example: Rdyn = 10 ohm at 10 mA for a 5 V zener, so a 10 % current change gives 10 mV (0.2 %) | Rdyn ~ k/Iz | Iz | zener bias-point choice | calc | p.12-13 §1.2.6A | high |
| AOE-1016 | components | Avoid low-voltage zeners (e.g., 3.3 V; low end of 1N5221-67): poor voltage constancy vs current. Zeners near 6 V (5.6 V 1N5232B, 6.2 V 1N5234B) have admirably steep curves. For low voltages use a two-terminal IC reference (e.g., LM385-1.2/-2.5): Rdyn < 1 ohm even at 0.1 mA, tempco better than 0.01 %/C | if Vz < ~5 V prefer IC reference; ref Rdyn < 1 ohm at 0.1 mA; TC < 0.01 %/C | Vz | voltage references | review | p.13, Fig 1.17 | high |
| AOE-1017 | components | A zener regulates better when fed from a current source (incremental R = infinity) than from a resistor | dVout -> 0 as R_feed -> infinity | bias method | zener references | review | p.13 | high |
| AOE-1018 | components | LED series resistor sizing: R = (Vsupply - V_LED)/I_LED. Example: red LED behaves like a 1.6 V zener; from a 5 V comparator pull-down path, 5 mA -> R = 3.4 V/5 mA = 680 ohm | R = (Vs - Vf - V_driver)/I_LED | Vs, Vf, I_LED | LED indicators | calc | p.13 §1.2.7 | high |
| AOE-1019 | components | LED forward drops: 1.5-2 V for red, orange and some green; 3.6 V for blue and high-brightness green (white = blue + phosphor). 2-10 mA gives adequate indicator brightness | Vf(red/orange) = 1.5-2 V; Vf(blue) = 3.6 V; I = 2-10 mA | LED color, supply | indicator headroom at minimum supply | calc | p.62 §1.9.4B | high |
| AOE-1020 | components | NTC thermistor sensitivity about -4 %/C (example 10 kohm at 25 C) | dR/R ~ -0.04 per C | thermistor | temperature sensing/limit circuits | calc | p.13 Fig 1.18 | high |
| AOE-1021 | components | Compare ratios (sensor divider vs reference divider from the same supply) so a threshold is insensitive to supply voltage; add hysteresis so the comparator is decisive | threshold set by ratio only | topology | comparator/threshold circuits | review | p.13 §1.2.7 | high |
| AOE-1022 | requirements | Sinewave amplitude conventions: Vrms = A/sqrt(2) = 0.707*A; Vpp = 2*A; unstated sinewave amplitude usually means rms. US mains 115 V rms, 60 Hz = 163 V amplitude = 325 Vpp. P = Vrms^2/R for any waveform. Average-responding meters are calibrated for sinewaves (Vrms = 1.11*Vavg); use a true-rms meter for other waveforms | Vrms = 0.707 A; Vpk(115 Vrms) = 163 V | waveform | amplitude specs; mains peak voltage | calc | p.14 §1.3.2, fn18; p.68 Review B | high |
| AOE-1023 | requirements | Decibels: dB = 10*log10(P2/P1) = 20*log10(A2/A1); 2x amplitude = +6 dB, 10x = +20 dB, 3 dB = 2x power. References: 0 dBV = 1 V rms; 0 dBm = 1 mW into the assumed Z (50 ohm RF -> 0.22 V rms; 600 ohm audio -> 0.78 V rms); 0 dB SPL = 20 uPa rms; -30 dBm = 1 uW; +3 dBV = 1.4 V rms. Always state the 0 dB reference | eq 1.11, 1.12 | levels, reference Z | specifications | calc | p.15 §1.3.2A; p.68 | high |
| AOE-1024 | timing | Rise time is defined as the 10 %-90 % transition time; typical circuit edges range from a few ns to a few us | tr = t(90 %) - t(10 %) | waveform | timing specs, scope measurements | measure | p.16 §1.3.3D, Fig 1.24 | high |
| AOE-1025 | hw-fw | 74LVC logic at +3.3 V: output levels typically 0 V and 3.3 V, input decision threshold 1.5 V; actual outputs can be as much as 0.4 V from ground or +3.3 V without malfunction | VOL <= 0.4 V; VOH >= 2.9 V; Vth = 1.5 V | logic family, supply | digital interfacing margins | inspect | p.17 §1.3.4 | high |
| AOE-1026 | rf | Sinewave frequencies up to ~2 GHz and above require special transmission-line techniques; beyond that (microwaves) lumped wired circuits are impractical and waveguides/striplines are used | f >~ 2 GHz -> transmission-line design | frequency | RF layout method | review | p.14 §1.3.1 | high |
| AOE-1027 | components | Parallel-plate capacitance C = 8.85e-14*er*A/d farads with A in cm^2 and d in cm (d << plate size); 1 cm^2 plates 1 mm apart give < 1 pF. Dielectric constants: air 1, polypropylene 2.1, polyester 3.1, C0G ceramic 45, X7R ceramic 3000 | C[F] = 8.85e-14*er*A[cm^2]/d[cm] | er, A, d | parasitic/plate capacitance estimates | calc | p.18 eq 1.14, fn21 | high |
| AOE-1028 | components | Capacitor current I = C*dV/dt (1 A into 1 F = 1 V/s; 1 mA into 1 uF = 1000 V/s; a 10 ms, 1 mA pulse raises 1 uF by 10 V). Stored energy U = 0.5*C*V^2 joules | I = C dV/dt; U = 0.5 C V^2 | C, V, I, t | inrush, ramp, hold-up energy | calc | p.19 eq 1.15, 1.16 | high |
| AOE-1029 | decoupling | Bypass capacitors are usually omitted from schematics (including this book's) but must never be omitted from the actual circuit: bypass every dc supply rail to ground with one or more capacitors; 0.1 uF to 10 uF are common, non-critical values | C_bypass = 0.1-10 uF on every rail/IC supply pin | IC supply pins | every IC/rail | inspect | p.19 fn22; p.25 item (c) | high |
| AOE-1030 | components | Capacitor dielectric selection: ceramic and polyester for most non-critical uses; polycarbonate, polystyrene, polypropylene, Teflon or glass for demanding applications; tantalum where greater capacitance is needed; aluminum electrolytics for power-supply filtering | mapping application -> dielectric | application class | capacitor selection | review | p.20-21 §1.4.1 | high |
| AOE-1031 | components | Capacitors in parallel add (C = C1 + C2 + ...); in series 1/C = 1/C1 + 1/C2 + ...; for two: C = C1*C2/(C1 + C2) | eq 1.17, 1.18 | Ci | capacitor networks | calc | p.21 §1.4.1A | high |
| AOE-1032 | timing | RC step response: discharge V = V0*exp(-t/RC); charge Vout = Vf*(1 - exp(-t/RC)); time to reach V: t = RC*ln(Vf/(Vf - V)); 50 % at 0.7 RC; 10-90 % rise time = 2.2 RC; within 1 % (>99 %) after 5 RC ("5RC rule"). A 1 uF across 1.0k has tau = 1 ms | eq 1.20-1.22 | R, C | timers, delays, settling | calc | p.21-23 §1.4.2 | high |
| AOE-1033 | timing | RC delay into logic: drive the RC from a buffer (low source resistance) so the input is not loaded, and account for the receiving gate threshold deviating from Vdd/2 - it changes the delay and output pulse width. Avoid relying on such RC tricks where possible | t_d = RC*ln(Vdd/(Vdd - Vth)); = 0.7 RC at Vth = Vdd/2 | R, C, Vth min/max | RC delay/edge circuits | calc | p.23 §1.4.2D, Fig 1.37 | medium |
| AOE-1034 | timing | RC timer with comparator reference at 1/e (37 %) of the supply: the comparator switches after exactly one time constant (1 minute timer with ~6 Mohm nearest standard value) | t = RC when Vref = Vs/e | R, C, Vref | RC timers | calc | p.23-24 Fig 1.38 | high |
| AOE-1035 | protection | Connecting a discharged capacitor directly across a supply draws a large transient (I = C dV/dt with dt -> 0); add a series resistor: in the timer example it limits peak to a modest 50 mA while still charging > 99 % in 5 RC (0.05 s) | I_pk = Vs/R_series; t_charge ~ 5*R_series*C | Vs, R, C | capacitor charge paths, pushbuttons, hot-plug | calc | p.24-25 note (a) | high |
| AOE-1036 | components | The comparator used in Ch.1 examples drives loads up to ~20 mA; its output bounces as a slow exponential crosses the reference unless hysteresis (positive feedback) is added | I_out <= ~20 mA; hysteresis required for slow inputs | comparator, input slew | comparator outputs | review | p.23-25 note (b) | high |
| AOE-1037 | timing | Passive RC differentiator Vout ~ RC*dVin/dt holds only if omega*RC << 1 for the highest frequency present (RC < 1/omega), and R must not load the source (at an edge the source sees R). Passive RC integrator holds only if the lowest signal frequency is well above f3dB (RC large, Vout << Vin) | omega_max*RC << 1 (diff); omega_min*RC >> 1 (int) | R, C, signal band | passive differentiators/integrators | calc | p.25-27; p.51 §1.7.10 | high |
| AOE-1038 | emc | Differentiated spikes on a signal line indicate capacitive coupling from a nearby square wave: first suspect a missing resistor termination; otherwise reduce the victim's source resistance or reduce the coupling capacitance. A square wave that looks differentiated on a scope usually means a broken connection (often at the probe) forming a tiny C with the scope input R | n/a | observed waveform | debug/bring-up | review | p.26 §1.4.3A, Fig 1.45 | high |
| AOE-1039 | components | Constant-current ramp: V(t) = (I/C)*t until the current source reaches its compliance limit (then it stops ramping). 1 mA into 1 uF reaches 10 V in 10 ms | V = I*t/C; V_max = compliance | I, C, compliance | ramp/sawtooth generators, timers | calc | p.27 §1.4.4A, Ex.1.18 | high |
| AOE-1040 | components | Real capacitors have series resistance (frequency dependent), series inductance, frequency-dependent parallel resistance, and dielectric absorption (after charging to V0, holding, then shorting, the voltage drifts back toward V0) | n/a | application | S/H, integrators, timers, precision | review | p.28 §1.4.5 | high |
| AOE-1041 | magnetics | Inductor: V = L*dI/dt (1 V across 1 H ramps 1 A/s); stored energy U = 0.5*L*I^2; inductance of a coil of fixed geometry is proportional to turns^2 | eq 1.23, 1.24 | L, I, V | switchers, chokes | calc | p.28 | high |
| AOE-1042 | magnetics | Wheeler's formula for a single-layer air-core coil: L ~ K*d^2*n^2/(18*d + 40*l) microhenry, d = diameter, l = length, n = turns, K = 1.0 for inches or 2.54 for cm; accurate to 1 % for l > 0.4*d | L[uH] = K d^2 n^2/(18d + 40l) | d, l, n | air-core coil design | calc | p.28-29 | high |
| AOE-1043 | magnetics | Volt-second balance: in steady state the average voltage across an inductor is zero (else its current rises without limit). Hence a synchronous buck switched at 50 % duty gives Vout = Vin/2 and the reversed (boost) connection gives Vout = 2*Vin | <V_L> = 0; Vout = D*Vin (buck) | duty, Vin | switching converters | calc | p.29-30 §1.5.1A, Fig 1.52 | high |
| AOE-1044 | magnetics | Transformers: voltage scales with turns ratio n, current with 1/n, impedance with n^2; little primary current if secondary unloaded (magnetizing inductance - so no dc transformer); leakage inductance gives load-dependent drop and degrades fast edges. Instrument power transformers: secondaries 10-50 V at 0.1-5 A; power-conversion transformers run 50 kHz-1 MHz; LF and HF transformers are not interchangeable | Z_sec/Z_pri = n^2 | n, frequency | transformer selection | review | p.30-31 §1.5.2 | high |
| AOE-1045 | components | Silicon signal diode (1N4148): ~0.6 V forward at 10 mA; forward drop 0.5-0.8 V in general; reverse leakage in the nA range; reverse breakdown (PIV) 75 V. Never drive a non-zener diode into reverse breakdown | V_F ~ 0.6 V @ 10 mA; V_R(max) < PIV | diode type, currents | all diode applications | calc | p.31 §1.6.1, Fig 1.55 | high |
| AOE-1046 | components | Schottky diodes have lower forward voltage and zero reverse-recovery time but more capacitance than junction diodes (and higher leakage - Table 1.1) | see Table 1.1 | diode type | rectifier/clamp/detector selection | review | p.32 Table 1.1 note b | high |
| AOE-1047 | power | Capacitor-input rectifier ripple (constant-current load approximation, conservative): dVpp = I_load/(f*C) half-wave; dVpp = I_load/(2*f*C) full-wave, f = line frequency (full-wave ripple at 2f, 120 Hz on 60 Hz mains). Choose R_load*C >> 1/f | dV = I/(f C) (HW); I/(2 f C) (FW) | I_load, C, f_line | unregulated dc supplies | calc | p.32-33 §1.6.3A eq 1.25 | high |
| AOE-1048 | power | Design the reservoir capacitor for worst case: supply capacitors have typical tolerances of 20 % or more; the most common load (a voltage regulator) is a constant-current, not resistive, load | C_min = 0.8*C_nom (or worse) | C tolerance | unregulated supplies | calc | p.33 §1.6.3A | high |
| AOE-1049 | power | A full-wave bridge puts two diode drops in series with the input (significant for low-voltage supplies). Packaged bridges: smallest 1 A average with 100-600 V (or 1000 V) breakdown; large ones 25 A or more | V_dc,pk = V_sec,pk - 2*V_F | V_sec, V_F | rectifier design | calc | p.32-33 §1.6.2, 1.6.4A | high |
| AOE-1050 | magnetics | Center-tapped full-wave rectifier uses each half-secondary only half the time, so for equal dc output power the transformer needs sqrt(2) = 1.4 x the current rating of a bridge rectifier (2 x winding I^2R heating) | I_rating(CT) = 1.41 x I_rating(bridge) | topology | rectifier transformer sizing | calc | p.33-34 §1.6.4B | high |
| AOE-1051 | power | Brute-force capacitor filtering is poor: bulky/expensive capacitors, very short conduction angle raises I^2R heating, and output still tracks line and load. Better: enough C to reduce ripple to ~10 % of the dc voltage, then an active (linear or switching) feedback regulator | ripple_pp ~ 0.1*Vdc before regulator | ripple, Vdc | linear supplies | calc | p.34-35 §1.6.5 | high |
| AOE-1052 | components | A diode signal rectifier gives no output for signals below ~0.6 Vpp; use a Schottky (hot-carrier) diode (~0.25 V drop) or pre-bias the rectifier to its threshold with a matched diode, which also tracks the drop's temperature change | V_sig,pp > V_F | V_sig | small-signal rectifiers/detectors | calc | p.35-36 §1.6.6A, Fig 1.70 | high |
| AOE-1053 | power | Diode-OR battery backup: example RTC ICs (NXP PCF8563, Seiko S-35390A) run 1.8-5.5 V at ~0.25 uA -> ~1e6 h (a hundred years) from a CR2032 coin cell | life[h] = capacity[Ah]/I_standby[A] | I_standby, cell capacity | backup power domains | calc | p.36 Fig 1.71 | high |
| AOE-1054 | protection | Diode clamp design: the series resistor limits clamp current but adds its value to the signal's Thevenin source resistance (compromise); the opposite excursion must not exceed the diode's reverse breakdown (-75 V for 1N4148). Diode clamps are standard on all CMOS logic inputs to survive static discharge in handling | I_clamp = (Vin - V_clamp - V_F)/R_s <= diode/pin rating | Vin extremes, R_s | input clamps | calc | p.36 §1.6.6C, Fig 1.72 | high |
| AOE-1055 | protection | A clamp referenced to a divider needs a stiff reference: the divider's Thevenin resistance must be small compared with the series resistor. Use a transistor/op-amp buffer (few ohms) or bypass the lower leg: 15 uF makes a 1k-leg divider look < 10 ohm above 1 kHz (no help at dc) | R_Th,ref << R_series | R_Th, R_s, frequency | clamps to derived rails | calc | p.36-37 Figs 1.73-1.76 | high |
| AOE-1056 | protection | Back-to-back diode limiter (+/-0.6 V) is a common high-gain amplifier input protection: an amplifier with gain 1000 on +/-15 V saturates unless its input stays within +/-15 mV | Vin_max = V_sat/G | G, supplies | amplifier input protection | calc | p.37 §1.6.6D | high |
| AOE-1057 | components | Silicon diode forward drop decreases ~2 mV/C; cancel it with a matched diode at the same temperature (whose bias current exceeds the maximum signal current) | dV_F/dT ~ -2 mV/C | temperature range | log converters, rectifiers, bias | calc | p.38 §1.6.6E | high |
| AOE-1058 | protection | Inductive kick: interrupting inductor current with no path forces the switch terminal up until something breaks down (~1000 V across contacts; destroys transistors; radiates interference). Put a diode across every dc-driven inductive load (relay coil etc.); the diode must carry an initial current equal to the steady inductor current (1N4004 is fine for nearly all cases) | I_D,pk = I_L; V_switch = Vsupply + V_F | I_L, Vsupply | dc relays, solenoids, motors | inspect | p.38-39 §1.6.7, Figs 1.83-1.84 | high |
| AOE-1059 | protection | Where the inductor current must decay quickly (fast relays, actuators, shutters, magnet coils) use a resistor across the inductor with Vsupply + I*R below the switch's maximum voltage, or a zener/voltage clamp, which gives a linear ramp-down (fastest for a given maximum voltage) | Vsupply + I_L*R < V_sw,max; t_decay(zener) = L*I_L/V_Z | I_L, L, V_max | fast-release inductive loads | calc | p.39 | high |
| AOE-1060 | protection | Ac-driven inductive loads (transformers, ac relays) cannot use a diode (it conducts on alternate half-cycles); use an RC snubber (typical values Fig 1.85) or a bidirectional TVS/MOV. Every instrument running from the ac line should include a snubber (power transformer is inductive); its capacitor must be rated for across-the-line service | snubber present; C class = across-the-line | load type | ac-line equipment | inspect | p.39 Fig 1.85, fn33 | high |
| AOE-1061 | protection | Include a transient suppressor across the ac power-line terminals, with appropriate fusing: bidirectional TVS zener or MOV (available 10 V to 1000 V, transient currents up to thousands of A) | TVS/MOV + fuse at mains entry | mains input | line-powered equipment | inspect | p.39 §1.6.7 | high |
| AOE-1062 | power | Charging a capacitor from a voltage source through a resistor loses half the energy in the resistor (50 % efficiency); resonant LC charging is lossless (ideal parts) and charges to 2*Vin in a half-cycle of f = 1/(2*pi*sqrt(LC)); a series diode ends the cycle | eta_RC = 50 %; V_final = 2 Vin; t_f = pi*sqrt(LC) | L, C, Vin | flashlamp/strobe/HV charging | calc | p.39-40 §1.6.8, Fig 1.86 | high |
| AOE-1063 | components | Reactance: Xc = 1/(2*pi*f*C), XL = 2*pi*f*L; impedances Zc = -j/(omega*C), ZL = j*omega*L, ZR = R. Examples: 1 uF = 2653 ohm at 60 Hz and 0.16 ohm at 1 MHz; 1 uF across 115 V rms, 60 Hz draws 43.4 mA rms (61 mA peak) with zero average power | eq 1.26, 1.29, 1.32 | f, C, L | all ac analysis | calc | p.41-45 | high |
| AOE-1064 | power | Average power in reactive circuits P = Re(V*conj(I)) with rms phasors; power factor = cos(phase angle), 0 (purely reactive) to 1 (resistive); a series capacitor C = 1/(omega^2*L) brings a series RL to unity power factor | eq 1.34; PF = cos(phi) | V, I | ac power, mains loads | calc | p.47-48 §1.7.6 | high |
| AOE-1065 | filter | Single-pole RC filter: f3dB = 1/(2*pi*R*C). Lowpass gain = 1/sqrt(1 + (omega*R*C)^2); highpass gain = omega*R*C/sqrt(1 + (omega*R*C)^2). At f3dB gain = 0.707 (-3 dB, not -6 dB) and phase 45 deg; asymptotic rolloff -6 dB/octave = -20 dB/decade; phase within ~6 deg of its asymptote at 0.1*f3dB and 10*f3dB | eq 1.35, 1.36 | R, C, f | RC filters | calc | p.49-51 §1.7.8-1.7.9, Fig 1.104 | high |
| AOE-1066 | filter | Worst-case impedances of a simple RC lowpass or highpass are both R (minimum input impedance = R, maximum output impedance = R). Design rule: drive the filter from a source impedance small vs R and load it with >= 10 x R. Example: amplifier with 100 ohm output -> R = 1k, load >= 10k | R >> Z_source; Z_load >= 10*R | Z_source, R, Z_load | passive RC filter design | calc | p.44 §1.7.1D, Ex.1.23 | high |
| AOE-1067 | filter | DC-blocking (coupling) capacitor: place the highpass corner below all frequencies of interest. Audio 20 Hz-20 kHz: choose f_min ~ 5 Hz -> RC = 1/(2*pi*5) ~ 30 ms; R = 10 kohm, C = 3.3 uF; the next stage's input R must be >> 10 k and the driver must drive 10 k | RC >= 1/(2*pi*f_min) | signal band, R | ac coupling | calc | p.43 §1.7.1C, Fig 1.93 | high |
| AOE-1068 | filter | Coupling pulses through a blocking capacitor: require tau = RC >> T (pulse duration); droop ~ T/tau, followed by a comparable overshoot at the next transition | droop = T/(RC) | T, R, C | ac-coupled pulses/clocks/data | calc | p.43 | high |
| AOE-1069 | filter | Cascading identical passive RC sections does not multiply their responses - each stage loads the previous. Make each successive section much higher impedance than the preceding one, or buffer between stages (transistor/op-amp, active filter) | Z_(k+1) >> Z_k (use the 10x rule of AOE-1066) | section impedances | multi-pole passive filters | calc | p.52 §1.7.13 | medium |
| AOE-1070 | filter | Filter order: each RC pole adds 6 dB/octave (20 dB/decade): 2 sections 12 dB/octave, 3 sections 18 dB/octave ("n-pole filter") | slope = -6*n dB/octave | n | filter order selection | calc | p.52 §1.7.13 | high |
| AOE-1071 | filter | LC resonance f0 = 1/(2*pi*sqrt(L*C)). A parallel LC ("tank") has infinite ideal impedance at f0 (bandpass when driven through R; higher driving impedance = sharper peak); a series LC has zero ideal impedance at f0 (trap/notch). Q = f0/BW(-3 dB); parallel RLC: Q = omega0*R*C = R/Xc = R/XL; series RLC: Q = omega0*L/R = XL/R. A Q-spoiling resistor may be added deliberately | eq 1.37; Q formulas fn46, fn48 | L, C, R | tuned circuits, traps | calc | p.52-53 §1.7.14 | high |
| AOE-1072 | filter | Resonator ringdown after a step or pulse: voltage falls to 1/e (37 %) in Q/pi cycles (2Q radians); stored energy falls to 1/e (61 % in amplitude) in Q/(2*pi) cycles (Q radians) | t(V -> 1/e) = Q/(pi*f0) | Q, f0 | tuned-circuit transients, Q measurement | measure | p.54 §1.7.14 | high |
| AOE-1073 | filter | A real series LC trap has a nonzero minimum impedance at resonance, usually dominated by the inductor's losses (ESR) | Z_min = ESR_L + ESR_C | component ESR | notch/trap filters | review | p.53 Fig 1.108 | high |
| AOE-1074 | filter | A single RC lowpass with 1 MHz "cutoff" (1 kohm, 160 pF) hardly cuts anything off below 2 MHz; for anti-alias or steep filtering use an LC ladder (the example: 3 inductors + 4 capacitors cutting off at 1.0 MHz) or an active filter | compare swept responses | filter spec | anti-alias filters | sim | p.54 §1.7.15, Figs 1.111-1.112 | high |
| AOE-1075 | filter | Prefer capacitors over inductors for RC/RL-style filters (inductors are bulkier, costlier, less ideal). Exception: ferrite beads / RF chokes on interconnects raise impedance at very high frequencies and prevent parasitic oscillations without the series resistance an RC would add | n/a | filter/stability need | HF stability, supply filtering | review | p.51 §1.7.11 | high |
| AOE-1076 | decoupling | Bypass capacitor criterion: its impedance at the lowest signal frequency must be small compared with the impedance of the element it bypasses | 1/(2*pi*f_min*C) << R_bypassed | f_min, R | emitter/reference/rail bypassing | calc | p.54-55 §1.7.16A | high |
| AOE-1077 | rf | AM envelope detector: choose R1*C2 long compared with the carrier period (~1 us) but short compared with the period of the highest audio frequency (~200 us) | T_carrier << R1*C2 << T_audio,min | f_carrier, f_audio,max | envelope/peak detectors | calc | p.55 §1.8 | high |
| AOE-1078 | test | Probe/cable capacitance loads circuits: BNC coax ~30 pF/ft; ordinary scope probe ~10 pF - a bare coax on a tuned node detunes it; use a proper probe | C_coax ~ 30 pF/ft; C_probe ~ 10 pF | node impedance | measuring tuned or high-Z nodes | review | p.56 §1.8 | high |
| AOE-1079 | components | Switch ratings: a small toggle might be rated 150 V, 5 A. Inductive loads drastically reduce switch life (arcing at turn-off). For low-level signals use switches designed for "dry switching" (gold-plated contacts); ordinary contacts rely on load current to clean oxides and become noisy/intermittent | V, I <= rating; gold contacts for low-level signals | load type, level | switch selection | review | p.58 §1.9.1E, fn50 | high |
| AOE-1080 | components | Rotary switches: shorting (make-before-break) types prevent an open input between positions; non-shorting (break-before-make) types are required when the switched lines must never be connected to each other. Toggle and momentary switches are always break-before-make | n/a | circuit requirement | switch selection | review | p.58 §1.9.1A-C | high |
| AOE-1081 | components | Rotary encoders provide typically 16-200 pulse pairs per revolution; optical types cost more but last indefinitely (mechanical-contact types wear) | 16-200 pulse pairs/rev | UI requirement | user controls | review | p.58 §1.9.1C | high |
| AOE-1082 | components | Relays: coil voltages 3-115 V ac or dc; reed and mercury-wetted relays for ~1 ms operation. SSRs (LED-driven semiconductor switch) have no contact bounce and switch ac smartly (turn on at zero voltage, off at zero current). Use relays mainly for remote and high-voltage/high-current switching where complete isolation is needed | t_op(reed) ~ 1 ms | isolation need, load | relay/SSR selection | review | p.59 §1.9.2 | high |
| AOE-1083 | connectors | Connectors are usually the most unreliable part of any equipment. Avoid connectors that cannot tolerate being dropped (miniature hexagon) or lack a secure locking mechanism (Jones 300 series). Two-part PCB connectors (e.g., VME) are more reliable than card-edge connectors (15 to 100+ gold-plated contacts) | n/a | connector choice | interconnect selection | review | p.59-61 §1.9.3 | high |
| AOE-1084 | connectors | BOM blacklist ("Components Hall of Infamy"): low-value wirewound pots, UHF connectors, electrical tape, Cinch-type connectors, microphone connectors, hexagon connectors, slide switches, cheap (non-screw-machined) IC sockets, type-F connectors, open-element trimmer pots, phono (RCA) connectors (signal mates before shield; both contacts tend to make poor contact) | none of listed parts in BOM | BOM | parts selection | inspect | p.60-63 Fig 1.126 | high |
| AOE-1085 | components | Resist using many trimmers - use good design instead. Never use a pot as a precise resistor (less stable than 1 % resistors, poor resolution); if a settable precise value is needed, use a 1 % (or better) fixed resistor supplying most of the value in series with a small trimmer (e.g., 23.4k = 22.6k 1 % + 2k trimmer) or a series string of precision resistors | R_fixed ~ 0.9-0.97 of R_total | R target, adjust range | calibration adjustments | calc | p.63 §1.9.5A | high |
| AOE-1086 | components | Digital potentiometers (resistor chain + switches) offer up to 1024 steps, single or dual, some nonvolatile (retain setting without power). Variable capacitors are limited to small values (up to ~1000 pF); variable (slug) inductors typically tune 2:1 | steps <= 1024; C_var <= ~1000 pF; L tuning 2:1 | adjust need | digital trim, RF tuning | review | p.63-64 §1.9.5 | high |
| AOE-1087 | test | Variac (autotransformer): typically 0-135 V ac from a 115 V line, 1-20 A; use it to verify worst-case performance vs line voltage. WARNING: output is not isolated from the power line | Vout 0-135 V | line range to test | line-variation testing | review | p.64 §1.9.5D | high |
| AOE-1088 | assembly | Marking ambiguities: a capacitor "470" may be 470 pF (integer) or 47 x 10^0 = 47 pF (exponent notation); a "K" suffix means +/-10 % tolerance; 4-digit date codes (yyww) masquerade as part numbers; tiny SMT parts carry only vendor codes (LMV981: SOT23 "A78A", SC70 "A77", microSMD "A"). Verify by reel label/BOM, not by markings | n/a | incoming parts | incoming inspection, rework | inspect | p.64-65 Fig 1.130 | high |
| AOE-1089 | components | BJT current gain beta (hFE) is not a good parameter: typically ~100 (review: ~150), it varies 50-250 between specimens of one type (a 3:1 spread or more), with further 3:1 spreads vs collector current and vs temperature; datasheet typical-beta curves have production spreads of +100 %/-50 %. A circuit that depends on a particular value of beta is a bad circuit | design must work for beta_min..beta_max (e.g., 0.5x..2x typ) | beta range | every BJT circuit | sim | p.72 §2.1.1; p.74 Fig 2.4 caption; p.126 Review C | high |
| AOE-1090 | derating | BJT maximum ratings Ic, Ib, VCE (and reverse VBE, power dissipation Ic*VCE, temperature) must not be exceeded; forward VBE above ~0.6-0.8 V draws enormous current (never apply an arbitrary voltage across B-E) | Ic <= Ic_max; VCE <= VCEO; P = Ic*VCE <= P_derated | Ic, VCE, VBE | every BJT | calc | p.72 §2.1.1 rules 2-3 | high |
| AOE-1091 | components | Saturated switch: typical VCE(sat) 0.05-0.2 V (review: 25-200 mV). Overdrive the base: base current ~1/10 of maximum collector current is common (the lamp example used 9.4 mA where 1.0 mA barely sufficed). Extra drive is needed because beta drops at low VCE, for incandescent lamps (cold resistance 5-10x lower), and for high-speed switching | Ib >= Ic_max/10 (typical practice); Ib >> Ic/beta_min | Ic_max, beta_min | BJT saturated switches | calc | p.73-74 §2.2.1; p.126 Review D | high |
| AOE-1092 | components | Add a base pull-down resistor (e.g., 10k) so the base sits at ground when the drive is open; a few-pF "speed-up" capacitor across the base resistor improves high-speed switching | R_BE ~ 10k (0.06 mA); C_speedup = a few pF | drive circuit | BJT switches | inspect | p.74 §2.2.1, fn6 | high |
| AOE-1093 | protection | If a switched load can swing below ground (ac-driven or inductive), add a diode in series with the collector (or reverse diode to ground) to prevent collector-base conduction; for inductive loads always add a suppression diode across the load (or R, RC, zener clamp for faster turn-off) - otherwise the collector exceeds its C-E breakdown | clamp present; V_C,peak < BV_CEO | load type | BJT/MOSFET low-side switches | inspect | p.74-75 §2.2.1 cautions 2-3, Fig 2.6 | high |
| AOE-1094 | components | Mechanical switch contacts bounce, making and breaking the circuit a few dozen times in the first few ms after actuation; route only dc control levels through front-panel cables/switches ("remote cold switching") rather than signals (capacitive pickup, degradation) | bounce duration ~ few ms | switch inputs | UI inputs, firmware debounce | review | p.75 §2.2.1 | high |
| AOE-1095 | components | LED drive with saturated npn: choose I_LED for brightness (e.g., 5 mA), R_C = (Vsupply - V_F(LED) - V_CE(sat))/I_LED, then choose R_B for saturation assuming a conservatively low beta (beta >= 25 is safe for a 2N3904). Never switch a voltage directly across an LED (steep I-V: 5 V across an LED blows it out). LED V_F 1.5-3.5 V; high-efficiency indicators look fine at a few mA, dazzling at 10-20 mA | R_B = (V_drive - 0.6)/(I_LED/25) or less | V_drive, Vsupply, V_F, I_LED | LED drivers from logic | calc | p.76 §2.2.2A, Fig 2.9 | high |
| AOE-1096 | components | High-side pnp switch driven via npn level shifter: pnp base pull-up (R3) keeps it off; the npn sinks pnp base current. Example: 3.3 kohm from 15 V gives ~4 mA base drive, enough for ~200 mA loads (beta > 50). The pull-up must not be too small: with 100 ohm the npn's available collector current could not develop the pnp's VBE and it would never switch | I_B(pnp) = I_C(npn) - 0.6/R3 >= I_load/beta_min | R2, R3, loads | high-side switching | calc | p.77 Fig 2.10, fn12 | high |
| AOE-1097 | protection | Capacitively-coupled base drive can pull a base negative by ~the supply swing: BJT base-emitter reverse breakdown is often as little as 6 V; reverse breakdown permanently degrades beta (and noise). The pulse circuit of Fig 2.11 must not run from more than +7 V for this reason (a common oversight). Add a protective diode (Fig 2.19) or inter-emitter resistor | V_EB(reverse) < V_EBO (~6 V) | coupling path, swing | pulse circuits, followers, diff-amp inputs | calc | p.77 fn13; p.82 Fig 2.19; p.104 | high |
| AOE-1098 | timing | Transistor one-shot (Fig 2.11): output pulse width ~ 0.63*R*C (C charging from -4.4 V toward +5 V until VBE ~ 0.6 V); such discrete pulsers are neither accurate nor stable - prefer a dedicated timer/pulse IC | T_pulse = 0.63*R3*C1 (example 63 us with RC = 100 us) | R, C, supply | pulse generation | calc | p.77-78 Ex.2.2; p.128 Review L | high |
| AOE-1099 | timing | Slow input edges crossing a switching threshold must go through a Schmitt trigger (hysteresis). Example discrete Schmitt thresholds ~+700 mV and ~+800 mV (emitter resistor carries 5 mA vs 10 mA). Good practice favors dedicated comparator ICs | hysteresis = V_T+ - V_T- > noise_pp | input slew, noise | slow/noisy logic inputs | review | p.78-79 Fig 2.13; p.128 Review M | high |
| AOE-1100 | components | Emitter follower: V_E = V_B - 0.6 V (0.6-0.7 V less). Input impedance Z_in = (beta + 1)*Z_load; output impedance Z_out = Z_source/(beta + 1) + r_e. Keep Z_out(source) << Z_in(load): a factor of 10 is a comfortable rule of thumb | eq 2.2-2.4; Z_source <= Z_load/10 | beta, R_s, R_L | followers, buffers, interstage | calc | p.79-80 §2.2.3A-B; p.93 §2.3.3 | high |
| AOE-1101 | components | Emitter follower drives current in one direction only: an npn follower sources through the transistor but sinks only through its emitter resistor; its small-signal output impedance is low but its large-signal sinking impedance is as large as R_E - low small-signal Zout does not imply large output current. Fixes: smaller R_E (more dissipation), pnp (if signals are one-sided), or push-pull | I_sink,max = (V_out - V_EE)/R_E | R_E, V_EE, load | followers, regulators driving loads with their own supplies | calc | p.81 Figs 2.17-2.18 | high |
| AOE-1102 | power | A regulated supply whose output is an emitter follower cannot sink current forced into it by a load that contains other supplies/sources | reverse current -> output rises | load topology | multi-supply systems | review | p.81-82 | high |
| AOE-1103 | power | Zener shunt regulator worst-case design: (Vin(min) - Vz)/R > Iout(max) so some zener current always flows; zener dissipation P_Z = [(Vin - Vout)/R - Iout]*Vz, worst case at Vin(max) and Iout(min); include component tolerances and line limits. Shunt regulators need a high-power zener for widely varying loads; not adjustable; moderate ripple/regulation | R <= (Vin_min - Vz)/(Iout_max + Iz_min); P_Z,max = ((Vin_max - Vz)/R - Iout_min)*Vz | Vin range, Iout range, Vz | zener regulators | calc | p.82 §2.2.4, Fig 2.20 | high |
| AOE-1104 | power | Zener + emitter-follower regulator: zener current becomes nearly independent of load and zener dissipation drops by up to beta. Add collector resistor Rc for momentary short-circuit protection, sized so its drop at the highest normal load current is less than the drop across R (transistor must not saturate). Reduce ripple by RC-filtering the zener bias with RC >> 1/f_ripple | I_short = Vin/Rc; Rc*I_max < V_R; RC >> 1/f_ripple | loads, Vin | simple pass-transistor regulators | calc | p.82-83 Figs 2.21-2.22 | high |
| AOE-1105 | components | Emitter-follower biasing: place the quiescent point for maximum symmetrical swing (V_E = 0.5*Vcc single-supply); make the bias divider stiff: R1 parallel R2 <= (1/10)*beta*R_E (divider current large compared with base current). Always provide a dc path for base bias current (with capacitive input on split supplies add R_B to ground ~ beta*R_E/10) | R1*R2/(R1+R2) <= 0.1*beta_min*R_E | beta_min, R_E | all BJT bias networks | calc | p.83-84 §2.2.5, Fig 2.27 | high |
| AOE-1106 | components | Emitter-follower design example (audio 20 Hz-20 kHz, Vcc = +15 V, Iq = 1 mA): V_E = 7.5 V; R_E = 7.5k; V_B = 8.1 V (R1:R2 = 1:1.17); R1 parallel R2 <= 75k -> R1 = 130k, R2 = 150k; C1 >= 0.15 uF into ~63k; C2 >= 1.0 uF into load >= R_E; with two cascaded highpass sections raise them to avoid 6 dB loss at 20 Hz: C1 = 0.47 uF, C2 = 3.3 uF (E6 values). Output impedance with 10k source ~87 ohm, ~110 ohm including r_e | worked example | Vcc, Iq, band | ac-coupled followers | calc | p.84 §2.2.5A | high |
| AOE-1107 | components | Never bias a transistor with a base resistor from Vcc computed from an assumed beta ("Don't do this!", Fig 2.28). Use voltage biasing from a stiff divider plus emitter resistor: in the design example a beta change 100 -> 200 moves V_E by only 0.35 V (5 %) | dV_E/V_E small for beta 2x | bias topology | BJT bias review | review | p.85 §2.2.5C | high |
| AOE-1108 | components | Cascading a pnp follower and an npn follower (equal emitter resistors, split supplies) approximately cancels the VBE offsets; cancellation is imperfect because VBE depends on collector current and transistor size | V_out ~ V_in (mV-level residual) | | dc-offset-free followers | review | p.85 §2.2.5D, Fig 2.29 | high |
| AOE-1109 | components | Resistor-plus-voltage current source approximates constant current only while V_load << V (dissipation-hungry, not programmable). For a current constant to x % over load range V_L, the source voltage must be ~ V_L/(x/100) | I = V/R; error ~ V_load/V | V, V_load range | simple current sources | calc | p.85-86 §2.2.6A, Ex.2.9 | medium |
| AOE-1110 | components | BJT current source/sink: Ic ~ (V_B - 0.6 V)/R_E, independent of V_C while the transistor is not saturated (V_C > V_E + 0.2 V). Bias the base from a divider stiff vs beta*R_E, a zener, a two-terminal reference (LM385), forward-biased diodes, or a red LED (~1.6 V = three diodes) | eq 2.5 | V_B, R_E | current sources | calc | p.86 §2.2.6B-C, fn19 | high |
| AOE-1111 | components | Current-source compliance: from near saturation (V_C ~ V_E + 0.2 V; e.g., +1.1 V or +5.1 V in the examples) up to the supply; loads containing their own supplies may carry the collector beyond the rails - then check V_CE <= BV_CEO and P = Ic*V_CE (and SOA for power transistors) | V_E + 0.2 <= V_C <= Vcc; V_CE <= BV_CEO; Ic*V_CE <= P_max | V_E, Vcc, load | current sources | calc | p.86 §2.2.6D | high |
| AOE-1112 | components | Common-emitter amplifier with emitter degeneration: gain = -R_C/(R_E + r_e) ~ -R_C/R_E; Z_in = R1 parallel R2 parallel beta*(R_E + r_e); Z_out ~ R_C (collector impedance is megohms). Input coupling C > 1/(2*pi*f*(R1 parallel R2)). Example: R_C = 10k, R_E = 1.0k, Ic = 1 mA: gain -10, Z_in ~ 8k, 0.1 uF -> 200 Hz corner | eq 2.6 | R_C, R_E, Ic, beta | CE amplifiers | calc | p.87-88 §2.2.7, Fig 2.35 | high |
| AOE-1113 | components | Unity-gain phase splitter: set quiescent collector at 0.75*Vcc for maximum symmetrical swing at both outputs; load both outputs with equal (or very high) impedances to keep gain symmetry. RC phase shifter driven by it: phi = 2*arctan(omega*R*C), constant amplitude; its load impedance should be large vs R_C and R_E | V_C,q = 0.75 Vcc; phi = 2 atan(omega R C) | loads | phase splitters/shifters | calc | p.88-89 §2.2.8, Figs 2.36-2.38 | high |
| AOE-1114 | components | Ebers-Moll: Ic = Is(T)*(exp(VBE/VT) - 1); VT = kT/q = 25.3 mV at 20 C (~25 mV at 25 C); Is ~ 1e-15 A for a small-signal transistor (2N3904), ~1e11 x smaller than Ic; beta "constant" 20-1000 depending on type, Ic, VCE, T. Collector current is set by VBE (accurately, nanoamps to milliamps), not by base current | eq 2.8-2.11 | VBE, Is, T | BJT analysis, log circuits, mirrors | calc | p.91 §2.3.1 | high |
| AOE-1115 | components | VBE rules of thumb: +60 mV (58.2 mV at room T) per decade of Ic; Ic doubles per +18 mV; +4 % per mV; dVBE = VT*ln(Ic2/Ic1) (0.25 mV per % of current ratio) | Ic = Ic0*exp(dV[mV]/25) | Ic ratio | mirrors, ballasting, matching | calc | p.91-92 §2.3.2A; p.102 Fig 2.62 | high |
| AOE-1116 | components | Intrinsic emitter resistance r_e = VT/Ic = 25/Ic(mA) ohms (25 ohm at 1 mA, 2.5 ohm at 10 mA); transconductance gm = Ic/VT = 1/r_e = 40*Ic(mA) mS. r_e is in series with the emitter in all circuits: limits grounded-emitter gain, makes follower gain < 1, sets follower minimum output impedance | eq 2.12, 2.13 | Ic | small-signal BJT design | calc | p.92 §2.3.2B | high |
| AOE-1117 | thermal | VBE at constant Ic falls ~2.1 mV/C (roughly proportional to 1/T_abs); at constant VBE, Ic rises ~9 %/C (doubles per 8 C, x10 per 30 C, i.e., 8.4 %/C = 2.1 mV/25 mV). gm at fixed Ic falls ~0.34 %/C at 25 C | dVBE/dT = -2.1 mV/C; dIc/Ic = +8.4-9 %/C at fixed VBE | T range | bias stability, paralleling, thermal runaway | calc | p.92 §2.3.2C; p.112 fn58; p.127 Review I | high |
| AOE-1118 | components | Early effect: dVBE = -eta*dVCE with eta ~ 1e-4 to 1e-5 (2N5088: 1.3e-4 -> 1.3 mV per 10 V); equivalently Ic = Ic0*(1 + VCE/VA), Early voltage VA typically 50-500 V; collector output resistance r_o = VA/Ic; pnp and high-beta parts tend to low VA (2N5087: VA = 55 V, eta = 4e-4 -> 4 mV shift or +17 % Ic for a 10 V change at fixed VBE). Limits single-stage gain, current-source/mirror output resistance | eq 2.14, 2.15; eta = 1/(VA + VCE) | VA, dVCE | current sources, mirrors, high-gain stages | calc | p.92-93 §2.3.2D, fn30-31; p.127 Review J | high |
| AOE-1119 | components | Emitter-follower gain Gv = R_L/(r_e + R_L) (e.g., 1 mA, 1k load -> 0.976); output impedance = r_e + R_s/(beta + 1) (R_s = 1k, Ic = 1 mA, beta = 100 -> 35 ohm). Above f_T/beta the follower's output impedance rises with frequency (looks inductive) - a capacitive load can ring or oscillate | Gv = R_L*gm/(1 + R_L*gm) | r_e, R_L, R_s | followers driving cables/capacitive loads | calc | p.93 §2.3.3, fn33 | high |
| AOE-1120 | components | Avoid the grounded-emitter (R_E = 0) amplifier except inside overall negative feedback: gain -R_C/r_e = -Ic*R_C/VT (-400 at 1 mA with 10k) varies with instantaneous Ic (distortion), Z_in = beta*r_e = 25*beta/Ic(mA) ohm is low and nonlinear, and bias is thermally unstable | Gv = -V_drop/VT | Ic, R_C | amplifier topology review | review | p.93-96 §2.3.4A | high |
| AOE-1121 | components | Grounded-emitter distortion estimate: peak fractional gain change dG/G ~ dVout/V_drop (V_drop = quiescent drop across R_C); waveform distortion ~1/3 of that. With external emitter resistor it is reduced by VT/(VT + Ie*R_E). Measured (+10 V, V_drop = 5 V): 0.7 % at 0.1 V and 6.6 % at 1 V output amplitude; with R_E dropping 0.25 V (10x predicted reduction): 0.08 % and 0.74 % | dG/G = (dVout/V_drop)*VT/(VT + Ie*R_E) | V_drop, swing, Ie*R_E | CE stage linearity | calc | p.94-95 §2.3.4A.1 | high |
| AOE-1122 | thermal | A base-voltage-biased grounded-emitter stage biased with collector at half supply saturates for an 8 C temperature rise (Ic x10 per 30 C). A 60 mV VBE uncertainty between transistor batches gives a 10x Ic error. Never bias by applying a computed VBE | dT_sat ~ 8 C | bias method | bias review | calc | p.96 §2.3.4A.3, Ex.2.13; p.129 Review Q | high |
| AOE-1123 | components | Stable CE biasing: make the dc emitter voltage large compared with VBE drift - use (bypassed) emitter resistance ~0.1*R_C ("one-tenth of the collector resistance is a good guideline"); base divider impedance ~1/10 of dc impedance looking into base. Gain-of-50 counter-example: V_E = 0.175 V -> a 20 C rise raises Ic ~25 % | R_E,dc ~ 0.1*R_C; V_E >> 2.1 mV/C * dT | R_C, dT | CE amplifier biasing | calc | p.96-97 §2.3.5A, Figs 2.48-2.50 | high |
| AOE-1124 | decoupling | Emitter bypass capacitor: its impedance at the lowest signal frequency must be small compared with r_e (+ any unbypassed emitter resistance), not R_E (e.g., 25 ohm at 650 Hz in the example); signal and dc paths may be split (Fig 2.51) so gain can be changed without changing bias | 1/(2*pi*f_min*C_E) << r_e + R_E,unbypassed | f_min, r_e | CE amplifiers | calc | p.96-97 Figs 2.48-2.51 | high |
| AOE-1125 | components | Matched-transistor biasing (monolithic dual) or dc feedback stabilizes a high-gain CE stage. Collector-to-base 10:1 divider feedback puts V_C ~ 11*VBE ~ 7 V but drifts ~1 V with ambient and lowers input impedance by the stage gain (to ~200 ohm in the example). Cascaded RC sections in bias/bootstrap networks can cause peaking or instability unless RC products differ | V_C = VBE*(1 + R1/R2) | divider, gain | CE bias with feedback | calc | p.97-98 Figs 2.52-2.54, fn39 | high |
| AOE-1126 | components | Grounded-emitter stage biased at 0.5*Vcc has small-signal gain G = 20*Vcc (Vcc in volts) independent of quiescent current (-400 at 20 V). A differential amplifier's maximum differential gain (R_E = 0) is 20 x the voltage (V) across its collector resistor; its maximum CMRR (R_E = 0) is 20 x the voltage across the tail resistor | G = 20*Vcc; G_diff,max = 20*V_RC; CMRR_max = 20*V_Rtail | Vcc, V_RC, V_tail | gain budgeting | calc | p.98, p.103; p.128-129 Review Q | high |
| AOE-1127 | components | Active (current-source or current-mirror) collector loads give single-stage gains of 1000-5000+ (limited by Early effect) but only into a very high-impedance load (follower, FET, op-amp) and only inside an overall dc feedback loop or as a comparator | G up to ~VA/VT | load impedance | high-gain stages | review | p.98-99; p.105 §2.3.8C | high |
| AOE-1128 | rf | Tuned (LC) collector load: high gain at resonance, low impedance at dc, rejects out-of-band signals and distortion; output swing can reach 2*Vcc pp; transformer coupling possible (example: 100 kHz, 1.0 mH, 6.2k across LC for Q = 10) | Q = R_p/X at f0 | L, C, R_p | narrowband RF amplifiers | calc | p.99 Ex.2.16 | high |
| AOE-1129 | components | Current mirror (Widlar): compliance to within a few tenths of a volt of the rail; program with a resistor, e.g., (15 V - 0.6 V)/14.4k = 1 mA. Requires matched (monolithic) transistors - 1 mV VBE mismatch = 4 % current error (matched pairs like DMMT3904/3906 matched to 1 mV). Early effect makes output vary ~25 % over the compliance range; base currents give ~2 % error at beta = 100 | I_out = I_P*(1 +/- 4 %/mV mismatch) | V_out range, matching | current mirrors | calc | p.101-102 §2.3.7, fn42; p.128 Review P | high |
| AOE-1130 | components | Improve mirrors with emitter degeneration resistors dropping at least a few tenths of a volt (ineffective over a wide programming-current range), or a Wilson mirror (cascode fixes Q1 VCE; equal-beta Q3 cancels base-current error); with R_E, choose Ic*R_E ~ 100 mV or more to suppress VBE-mismatch error. Unequal R_E ratio gives a ratio mirror (correct for dVBE = VT*ln(ratio)) | Ic*R_E >= 100 mV | R_E, Ic | precision mirrors | calc | p.101-102 Figs 2.60-2.62 | high |
| AOE-1131 | components | Differential (long-tailed pair) amplifier: G_diff = R_C/(2*(r_e + R_E)) (single-ended output); G_CM = -R_C/(2*R_tail + R_E); CMRR ~ R_tail/(r_e + R_E). Differential gains of a few hundred are possible; R_E typically <= 100 ohm or omitted. Example (100 uA per side, R_E = 1.0k): G_diff = 10, input impedance ~250k (drops to ~50k with R_E removed, gain 50) | formulas | R_C, R_E, R_tail, Ic | diff amps | calc | p.103 §2.3.8, Fig 2.64 | high |
| AOE-1132 | components | Replace the diff-amp tail resistor with a current source: CMRR ~100,000:1 (100 dB) at dc with an LM394 matched pair; common-mode input range limited below by the current source's compliance and above by the collectors' quiescent voltage (-3.5 V to +3 V in the example). A tail reference equal to the bandgap (~1.23 V) makes the tail current PTAT and cancels the gain's temperature dependence | CMRR = 100 dB (example) | tail design | precision diff amps | calc | p.104 §2.3.8A, Fig 2.65 | high |
| AOE-1133 | protection | Differential pairs without inter-emitter resistors are destroyed by differential inputs above ~6 V (B-E reverse breakdown); an inter-emitter resistor limits the current but beta/noise may still degrade and input impedance collapses during reverse conduction; clamp the inputs | V_diff,max < ~6 V (unless clamped) | input range | diff-amp and op-amp inputs | calc | p.104 §2.3.8A | high |
| AOE-1134 | components | A differential pair makes a good single-ended dc amplifier (ground one input): VBE temperature drift cancels; accuracy is limited only by VBE and tempco mismatch - e.g., MAT12 monolithic pair drift 0.15 uV/C typical. The grounded-inverting-input connection also avoids Miller effect at the driven input | drift = mismatch only | pair matching | dc amplifiers | review | p.104-105 §2.3.8B, Fig 2.66 | high |
| AOE-1135 | thermal | Datasheet "Pdiss max" (with case at 25 C) = (150 C - 25 C)/R_thJC is specsmanship. Real allowable dissipation: P = (Tj[your-max] - T_amb)/(R_thJC + R_thCS + R_thSA), which is much lower, especially if you are careful with Tj max (e.g., 100 C) | P_real = (Tj_max_design - T_amb)/(theta_JC + theta_CS + theta_SA) | Tj_max (design), T_amb, thetas | every power semiconductor | calc | p.106 Table 2.2 notes (c),(h) | high |
| AOE-1136 | power | Class-A single-ended follower output needs quiescent current >= peak load current: a 10 W / 8 ohm amplifier on +/-15 V dissipates 55 W in the transistor and 110 W in the emitter resistor (165 W quiescent). Use push-pull (class-B/AB) instead; a class-B push-pull stage dissipates < 10 W per transistor at 10 W output | I_q >= I_L,peak | P_out, R_L, supplies | power output stages | calc | p.106-107 Figs 2.68-2.69 | high |
| AOE-1137 | power | Push-pull crossover distortion: bias the output pair into slight conduction with diodes (class-AB). Base bias resistors must supply peak base current: +/-20 V, 8 ohm, 10 W -> peak base 13.5 V, peak load 1.6 A, beta 50 (power transistors have lower beta) -> 32 mA -> ~220 ohm | R_bias = (Vcc - V_B,peak)/(I_L,peak/beta_min) | supplies, P_out, R_L, beta_min | push-pull stages | calc | p.107 §2.4.1A, Fig 2.71 | high |
| AOE-1138 | thermal | Class-AB thermal stability: add small emitter resistors (a few ohms or less) carrying a few tenths of a volt at quiescent current, and thermally couple the bias diodes (preferably diode-connected transistors or a VBE multiplier) to the output devices/heatsink. With ~1 diode drop across the emitter resistors a 30 C rise (-63 mV VBE) raises quiescent current ~50 %; with no emitter resistors it rises x10 (1000 %) - thermal runaway risk. Typical quiescent current ~100 mA for an audio power amplifier | dIq/Iq ~ 63 mV/V(R_E) per 30 C | V across R_E, coupling | class-AB output stages | calc | p.108 §2.4.1B, Fig 2.72 | high |
| AOE-1139 | power | Class-D (switching) amplifiers: switch at >= 10x the highest signal frequency and remove the carrier with an LC lowpass; very efficient and no thermal runaway, but beware HF noise emission, switching feedthrough and limited linearity (example TPA3123: 250 kHz, 20 W per channel) | f_sw >= 10*f_signal,max | f_signal | audio/power amplifiers | review | p.109 §2.4.1C, Fig 2.73 | high |
| AOE-1140 | components | Darlington: beta = beta1*beta2; VBE = 2 x normal; VCE(sat) >= one diode drop; slow turn-off. Put a resistor across the output transistor's B-E: leakage*R < a diode drop and R must not steal much base current; typically a few hundred ohms (power) or a few kohm (small-signal). Examples: MJH6284 beta 1000 typ at 10 A; TIP142 beta 4000 typ at 5 A; MPSA14 beta >= 10,000 at 10 mA, 20,000 at 100 mA, 30 V, no internal resistor | beta = b1*b2; I_leak*R_BE < 0.6 V | leakage, drive | Darlington use | calc | p.109-110 §2.4.2, Figs 2.74-2.76 | high |
| AOE-1141 | components | Sziklai (complementary Darlington) is generally preferred over Darlington for linear stages: single VBE drop, stabilized by output-transistor base resistor R_B. If R_B current (at VBE) = 25 % of the output base current at peak, the driver current ranges only 5:1, so its VBE varies only VT*ln5 = 40 mV over full output swing. Also cannot saturate below a diode drop | V_BE variation = VT*ln(I_max/I_min) | R_B sizing | push-pull output stages | calc | p.110-111 §2.4.2A, Figs 2.77-2.78 | high |
| AOE-1142 | components | Superbeta and matched pairs: 2N5962 minimum beta 450 from 10 uA to 10 mA; LM394/MAT-01 npn pairs with VBE matched to a fraction of a mV (50 uV best grades) and beta matched ~1 %; MAT-03 pnp pair; superbeta-input op-amps (LT1008, LT1012) reach ~50 pA bias current | as stated | matching need | low-level/matched amplifiers | review | p.111 §2.4.2B | high |
| AOE-1143 | components | Bootstrapping a follower's bias network (bias divider fed through series R3 whose lower end is driven by the emitter via C2): effective R3 at signal frequencies = R3/(1 - A) = R3*(1 + R_L/r_e), typically ~100x, so input impedance becomes dominated by the base impedance. Bootstrapping a collector load (driving a follower) makes an approximate current-source load: higher gain and full base drive at the top of the swing | R_eff = R3/(1 - A) | follower gain A | high-Zin biasing, driver stages | calc | p.111-112 §2.4.3, Fig 2.80 | high |
| AOE-1144 | thermal | Paralleled BJTs need emitter-ballast resistors: VBE of "identical" parts spreads (17 mV over 100 adjacent reel parts measured; assume ~100 mV worst case incl. replacements) and 60 mV = 10x current; hot devices hog current (+8.4 %/C). Choose ballast drop 300-500 mV (at least a few tenths V) at the high end of the operating current; or use active ballasting (sense transistors) or MOSFETs | V(R_E) at I_max = 0.3-0.5 V | I_max per device | paralleled power BJTs | calc | p.112-113 §2.4.4, Figs 2.81-2.82 | high |
| AOE-1145 | components | Junction capacitances matter: at 100 MHz a typical 5 pF junction is only 320 ohm. Output pole f = 1/(2*pi*R_L*C_L); input pole with source R_s and C_be; f_T is where beta falls to 1 (base current robbed by C_be). Speed up by lowering source impedances and load capacitances and raising drive currents | f = 1/(2*pi*R*C) | R_L, C_L, R_s, C_in | HF/switching design | calc | p.113-114 §2.4.5A | high |
| AOE-1146 | components | Miller effect: collector-base feedback capacitance appears at the input as C_cb*(Gv + 1); a typical 4 pF can look like several hundred pF to ground. Cures: drive from a low source impedance (emitter follower), differential pair with no collector resistor on the input side, cascode (fixed-bias upper transistor a few volts above the lower emitter), or grounded-base stage | C_in,eff = C_cb*(1 + Gv) | Gv, C_cb, R_s | wideband amplifiers | calc | p.114 §2.4.5B, Fig 2.84 | high |
| AOE-1147 | control-loop | Negative feedback: closed-loop gain G = A/(1 + A*B); A = open-loop gain, A*B = loop gain, 1 + A*B = desensitivity. Gain variations are reduced by 1 + A*B: dG/G = (1/(1 + AB))*dA/A. Example: A from 1000 to 10,000 with B = 0.1 -> G 9.90 to 9.99 (+/-10 dB open loop -> +/-0.04 dB). Nonlinearities are reduced the same way. Require AB >> 1 (open-loop gain >> closed-loop gain) | eq 2.16, 2.17 | A, B | any feedback amplifier | calc | p.117-118 §2.5.2-2.5.3A | high |
| AOE-1148 | control-loop | Feedback and impedances: series (voltage-subtracting) feedback multiplies input impedance by (1 + AB) (100k native, A = 1e4, 99:1 divider -> ~10 Mohm, gain 99); shunt (current) feedback gives Z_in = R_i parallel R_f/(1 + A). Sampling output voltage divides output impedance by (1 + AB); sampling output current multiplies it by (1 + AB); general case: Blackman Z_out = R_o*(1 + (AB)_sc)/(1 + (AB)_oc). Inverting amp gain = -A*(1 - B)/(1 + A*B) -> -R2/R1 | formulas | A, B, R_i, R_o | feedback amplifier design | calc | p.118-120 §2.5.3B-D | high |
| AOE-1149 | control-loop | Include feedback-network loading in the open-loop gain A (both output loading and input-network effect); the formulas assume a unidirectional beta network | A_eff = A with network attached | network impedances | feedback analysis | calc | p.120 §2.5.4A | high |
| AOE-1150 | control-loop | Stability criterion: oscillation occurs if the loop phase shift reaches 180 deg at the frequency where loop gain AB = 1; feedback-network lag makes it worse. A 90 deg open-loop lag is benign: A = -100j, B = 0.1 gives abs(G) = 9.95 with ~6 deg lag (0.5 % gain error vs 9 % for a real A = 100). Op-amps have ~90 deg lag from ~10 Hz to ~1 MHz or more | phase(AB) > -180 deg where abs(AB) = 1 | loop gain/phase | all feedback loops | sim | p.120-121 §2.5.4B | high |
| AOE-1151 | control-loop | Small-signal closed-loop output impedance does not mean large-signal drive: in the Fig 2.91 feedback amplifier Z_out = 0.3 ohm (loop gain 70) yet the 5 ohm emitter resistors limit a 4 ohm load to ~10 Vpp | V_out,max set by large-signal limits | R_E, load | feedback power stages | calc | p.122 §2.5.5B | high |
| AOE-1152 | components | With BJT input stages (bias currents ~uA, e.g., 4 uA -> 0.4 V across 100k), make the dc resistances seen by both inputs equal; consider Darlington/superbeta inputs | R_dc(+in) = R_dc(-in) | I_B, R_bias | discrete/op-amp inputs | calc | p.122 §2.5.5A | high |
| AOE-1153 | power | Feedback regulator design checks: bias the reference zener from the regulated output (constant current) but verify the circuit starts up; a compensation capacitor is usually needed to prevent oscillation, particularly if the output is capacitively bypassed (as it should be) | start-up verified; loop stable with C_out | topology | discrete regulators | sim | p.123 §2.6.1, Fig 2.93 | high |
| AOE-1154 | protection | Add a current-sense resistor + protection transistor that steals base drive when output current exceeds the limit (example: ~6 A for a 50 W heater driver); add a little positive feedback so an on/off heater snaps cleanly (Schmitt action) | I_limit = 0.6 V/R_sense | I_limit | power drivers, heaters | calc | p.123 §2.6.2, Fig 2.94 | high |
| AOE-1155 | components | FET drain-current model: linear region ID = 2*k*[(VGS - Vth)*VDS - VDS^2/2]; saturation ID = k*(VGS - Vth)^2 with VDS(sat) ~ VGS - Vth. Linear-region resistance is inversely proportional to gate drive; saturation current is proportional to gate drive squared. Vth is found by extrapolating a sqrt(ID) vs VGS plot (not the datasheet VGS(th)) | eq 3.1, 3.2 | k, Vth, VGS, VDS | FET biasing/switch analysis | calc | p.137-138 §3.1.4, Fig 3.13-3.14 | high |
| AOE-1156 | components | Datasheet VGS(th) (MOSFET) is specified at a tiny drain current (typically 0.25 mA) and ranges 0.5-5 V; JFET VGS(off)/Vp typically -1 to -5 V (defined at ~10 nA). It takes considerably more gate voltage than VGS(th) to turn a MOSFET fully on - check RDS(on) at your actual VGS (IRF7470: VGS(th) = 2 V max at 0.25 mA, but RDS(on) = 30 mohm max only at VGS = 2.8 V). For low-voltage logic use parts with RDS(on) specified at logic levels (e.g., FDS6574A 9 mohm max at 1.8 V) | require RDS(on) spec at VGS <= V_drive,min | VGS drive, datasheet points | MOSFET switch selection | review | p.136-137 §3.1.3; p.193-194 §3.5.3 | high |
| AOE-1157 | components | FET manufacturing spread (typical): IDSS/ID(on) 1 mA-500 A, spread x5; RDS(on) 0.001 ohm-10k, x5; gm at 1 mA 500-3000 uS, x5; JFET Vp 0.5-10 V, spread 5 V; MOSFET VGS(th) 0.5-5 V, spread 2 V; BVDS(off) 6-1000 V; BVGS(off) 6-125 V. Compare BJT VBE spread 0.63-0.83 V (2N7000 VGS(th) spec 0.8-3 V at 1 mA) | see Table 2.9 | device type | FET bias design | review | p.139 §3.1.5 table | high |
| AOE-1158 | components | FET VGS matching is poor: off-the-shelf BJTs spread ~25 mV in VBE; MOSFET datasheet spreads 1-2 V (within one batch typically several hundred mV, best ~50 mV); JFET 2N5457-59 VGS at 1 mA spreads ~1 V within a type (BJT 10-20 mV). Measure actual parts if matching matters; use monolithic matched pairs. Best matched JFET pair 0.5 mV / 5 uV/C max vs BJT 25 uV / 0.3 uV/C | spread figures as stated | matching need | FET diff pairs, paralleling | measure | p.139-140 §3.1.5A, Fig 3.17, fn14-15 | high |
| AOE-1159 | components | Op-amp input current by technology (typical): JFET LF411/412 50 pA; CMOS TLC272 1 pA; LMC6042 2 fA; bipolar LM324 45 nA; superbeta/bias-cancelled BJT ~25 pA. FET input current is leakage that doubles every 10 C (rises exponentially); BJT bias current is flat or falls slightly with temperature - FET-input parts can exceed BJT parts at elevated temperature | I_leak(T) = I_leak(25C)*2^((T-25)/10) | T_max, source impedance | op-amp selection for high-Z sources | calc | p.140 fn16; p.163 §3.2.8A, Fig 3.48 | high |
| AOE-1160 | thermal | FET scale factor k ~ T^-3/2 and Vth tempco 2-5 mV/C: at high currents ID has a negative tempco (self-ballasting), at small currents a positive tempco, with a zero-tempco current in between (used in FET op-amps). Vertical power MOSFETs in linear service run in the positive-tempco region | sign(dID/dT) depends on ID vs I_ZTC | ID, device | paralleling, bias stability | review | p.138 §3.1.4, Fig 3.14 | high |
| AOE-1161 | esd | MOSFET gates are insulated by oxide < a wavelength thick: typical power MOSFET VGS max +/-20 V (+/-20 to +/-30 V), less for small IC MOSFETs; a single gate breakdown is irreversible; MOSFETs can be destroyed "literally by touching" (ESD) | V_GS <= VGS_max always (incl. transients) | gate drive, transients | every MOSFET gate | inspect | p.134 §3.1.2B; p.221 Review T | high |
| AOE-1162 | components | A MOSFET gate holds its last voltage on its capacitance (gate current << 1 pA): a floating gate can stay on, off, or half-on for hours. Never leave a gate undriven - add a gate-source pull-down (100k-1M) especially when the gate is driven from another board (also guarantees OFF when disconnected/unpowered) | R_GS = 100k-1M on off-board-driven gates | gate source | MOSFET switches | inspect | p.132 fn2; p.199-200 §3.5.4G | high |
| AOE-1163 | components | p-channel FETs have poorer performance than n-channel (lower hole mobility): higher threshold, higher Ron, lower saturation current; a "complementary" p part is built larger, so it has more capacitance and gate charge and costs more (FQP9P25 vs FQP9N25: Ron 0.62 vs 0.42 ohm, Crss 27 vs 15 pF, Ciss 910 vs 540 pF, Qg 29 vs 15.5 nC, $0.97 vs $0.74) but slightly better R_thJC (1.04 vs 1.39 C/W) | compare datasheets | polarity | switch topology choice | review | p.134 fn5-6; p.202 §3.5.5 | high |
| AOE-1164 | components | FET as analog switch: the effective source is whichever terminal is farther from the active drain supply; to guarantee OFF, drive an n-channel gate more negative than the most negative signal (by >= abs(VGS(off)) for JFETs); to guarantee low Ron, drive the gate several volts more positive than the most positive signal | V_G,off < V_sig,min - margin; V_G,on > V_sig,max + several V | signal range | FET signal switches | calc | p.133, 136 §3.1.3; p.220 Review N | high |
| AOE-1165 | components | JFET gate is a diode: an n-channel JFET gate conducts at about +0.5-0.6 V forward relative to the channel; operate it reverse biased (JFETs are always depletion mode) | V_GS < +0.5 V (n-ch) | V_GS | JFET circuits | calc | p.134-135 §3.1.2B | high |
| AOE-1166 | components | JFET families graded by IDSS still spread 5:1 or more; switching JFETs may specify only IDSS(min) (J110: >= 10 mA; a sample measured 122 mA). JFET gm varies ~10:1 between types at the same current; small-signal FETs typically ~10 mS at a few mA vs BJT 40 mS at 1 mA (200 mS at 5 mA). Within one family, gm at a given ID is predictable to ~+/-20 % even when VGS varies widely | design for worst-case IDSS, gm | IDSS, gm range | JFET amplifiers, sources | review | p.141-142 §3.2.1; p.147 fn27; p.169 §3.3.3A | high |
| AOE-1167 | components | FET transconductance: gm = 2*k*(VGS - Vth) = 2*sqrt(k*ID) in the quadratic region, so gm/gm0 = sqrt(ID/ID0); in the subthreshold region ID = I0*exp(VGS/(n*VT)) with n ~1.05-3 (JFETs ~BJT-like) so gm = ID/(n*VT). From datasheet limits you can bound gm at your ID by sqrt scaling from gm(at IDSS) | eq 3.5, 3.6, 3.12 | ID, IDSS, gm(IDSS) | FET gain estimation | calc | p.147 §3.2.3A; p.166-168 §3.3.1C, 3.3.3 | high |
| AOE-1168 | components | Common-source amplifier gain G = gm*R_D (RD in parallel with r_o = 1/gos: G = gm*RD/(1 + gos*RD)); with unbypassed source resistor G = -R_D/(R_S + 1/gm). Size R_D so the drain stays >= 1-2 V (2.5 V in the example) above the source at the maximum specified IDSS. Example BF862 (gm 45 mS at IDSS 10-25 mA): G ~ 13; at 2 mA (gm ~20 mS, R_S = 200 ohm) G ~ -8 | eq 3.3, 3.13 | gm, RD, RS, gos | JFET/MOSFET amplifiers | calc | p.148 §3.2.3B, Fig 3.29; p.167 §3.3.2A | high |
| AOE-1169 | components | JFET self-biased current source/sink: I = abs(VGS)/R for I < IDSS; predictability is poor (2:1 range typical even with a source resistor); a JFET source varies ~5 % over 5-20 V drain range at IDSS (~2 % with source R); even trimmed, ~5 % over temperature and load; op-amp/transistor current sources hold better than 0.5 %. Prefer BJT current sinks (Fig 3.26) or pre-sorted parts for predictable current | I = -VGS/RS | IDSS spread, RS | JFET current sources | calc | p.143-146 §3.2.2 | high |
| AOE-1170 | components | Current-regulator diodes (JFET with gate tied to source, e.g., 1N5283-1N5314): 0.22-4.7 mA, +/-10 % tolerance, tempco +/-0.4 %/C, minimum voltage 1-2.5 V, maximum 100 V, regulation 5 % typ, impedance ~1 Mohm (1 mA part); a 1N5294 (0.75 mA) held current to ~145 V breakdown and reached full current at < 1.5 V | as stated | I, V range | two-terminal current sources | review | p.142-143 §3.2.2, Fig 3.22 | high |
| AOE-1171 | thermal | Worked dissipation check (JFET pull-down for a +/-12 V follower, +/-10 V into 2k): a resistive pull-down would need R_E < 400 ohm (365 ohm) and ~33 mA quiescent (~400 mW each in transistor and resistor) plus poor linearity; a 2N5486 at IDSS = 20 mA would dissipate 440 mW (too much for TO-92/SOT-23 without heatsink); with R_S = 140 ohm the sink ranges 5.7-9.5 mA, worst-case 220 mW each - within a TO-92's 350 mW at 25 C ambient | P = I*V_max per device <= package rating (TO-92 350 mW @ 25 C) | I range, V swing | small-transistor dissipation | calc | p.144-145 §3.2.2B, Fig 3.24-3.25 | high |
| AOE-1172 | components | JFET cascode (upper JFET with larger IDSS, gate tied to lower source) clamps the current-source/amplifier VDS: raises output impedance (kills gos/"Early" effect), kills Miller effect, and keeps VDS low to avoid impact-ionization gate current; highly recommended even when bandwidth is not an issue | cascode present when VDS > ~5 V or high Zout needed | topology | JFET sources, amplifiers, followers | review | p.145-146 Fig 3.27; p.148 §3.2.3C; p.153 | high |
| AOE-1173 | components | LM334 programmable current source: I ~ 0.067 V/R_set, operates down to ~1 V drop, effective capacitance ~10 pF, ~$0.50 - a predictable source-pulldown for JFET stages independent of VGS | I = 0.067/R_set | R_set | bias current sources | calc | p.149 Fig 3.30B, fn35 | high |
| AOE-1174 | components | Hybrid JFET + op-amp amplifier: keep the feedback bottom resistor R_g < 1/gm (so open-loop gain is not reduced) and small enough that its Johnson noise is insignificant vs the JFET's e_n (< ~25 ohm for ~1 nV/rtHz): ~10 ohm chosen; loop gain ~50 (G_OL ~2500, G_CL = 50). A small compensation capacitor removes peaking (5 dB at 16 MHz uncompensated -> 0.1 dB); 10-20 pF input shunt tames peaking for ~1k sources | R_g < 1/gm; e_n,Rg << e_n,JFET | gm, e_n | low-noise wideband amplifiers | calc | p.151-152 §3.2.3E, Figs 3.34-3.35 | high |
| AOE-1175 | components | Monolithic JFET pairs "tightly matched" on JFET scale still mismatch up to +/-20 mV (LSK389: ~100x a good BJT pair); with gain 50 that is 1 V output offset - provide an offset trim with range for the worst case | V_os,out = G*dVGS,max | G, pair spec | dc-coupled JFET diff stages | calc | p.154 §3.2.4A | high |
| AOE-1176 | components | Put a ~50 ohm resistor in series with an op-amp output that drives cables/capacitive loads: ensures stability into capacitive loads and back-terminates 50 ohm coax | R_series = 50 ohm | load | op-amp outputs to cables | inspect | p.154 §3.2.4A | high |
| AOE-1177 | components | FET source follower: gain G = gm*R_L/(1 + gm*R_L) (with gos: G = 1/(1 + 1/(gm*RL) + 1/Gmax)); output impedance = 1/gm (few hundred ohm at a few mA; e.g., gm 1.9 mS -> 525 ohm, 345 ohm with 1k load vs BJT 16 ohm at 1.6 mA; gain only 0.66 into 1k). Need gm*RL and Gmax both > 100 for < 1 % gain error; else use current-sink load, cascode, or BJT gm-enhancer | eq 3.7, 3.8, 3.14 | gm, RL, Gmax | FET buffers | calc | p.157-158 §3.2.6C-E; p.167 §3.3.2B | high |
| AOE-1178 | components | FET source followers have unpredictable dc offset (VGS). For zero offset use a monolithic matched pair with the second JFET as current sink (equal source resistors), plus cascodes to hold VDS constant; a gos ~100 uS pair with 10 V VDS mismatch gives ~60 mV offset (dV = dVDS/Gmax). Measured distortion (LSK389 followers, 1-5 V rms): resistor pull-down 0.02-0.14 % (0.25 V offset); matched current-sink 20 dB lower (~10 mV offset); + cascode another 20 dB | offset ~ dVGS + dVDS/Gmax | pair matching, VDS | precision JFET buffers | calc | p.158-161 Figs 3.43-3.45, fn49 | high |
| AOE-1179 | protection | Protect JFET/MOSFET gates against reverse breakdown with a series resistor and low-leakage clamp diode (e.g., 1N3595, or a BJT B-C junction); large series R adds Johnson noise - a depletion-mode MOSFET current limiter avoids this. Depletion MOSFETs (to 1000 V) need gate protection against >+/-20 V both polarities | I_clamp = (V_fault - V_rail)/R_prot | fault V, noise budget | high-Z input buffers | calc | p.160 Fig 3.43F | high |
| AOE-1180 | components | Bootstrap/guard to fight input capacitance: follower bandwidth with high source impedance f3dB ~ 1/(2*pi*R_s*C_in), C_in = C_rss + C_stray + (1 - Gv)*C_iss; bootstrapping the drain cuts C_rss ~5x; drive a cable's inner shield ("guard") from the follower output to cancel cable capacitance | eq as stated | R_s, capacitances | high-impedance sensor inputs | calc | p.157 §3.2.6D; p.160 | high |
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

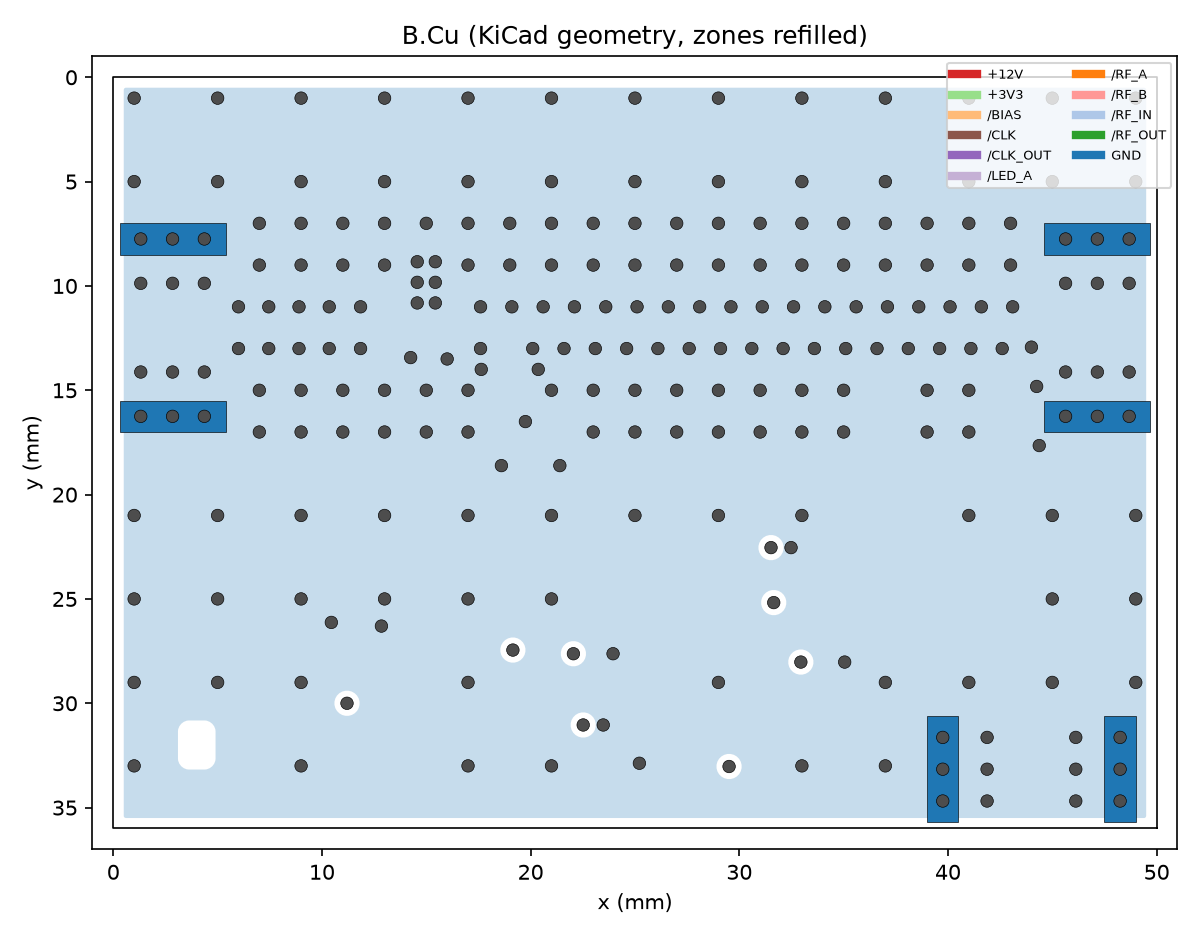
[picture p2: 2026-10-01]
examples/rf-frontend/audit/renders/routed/copper-B_Cu.png

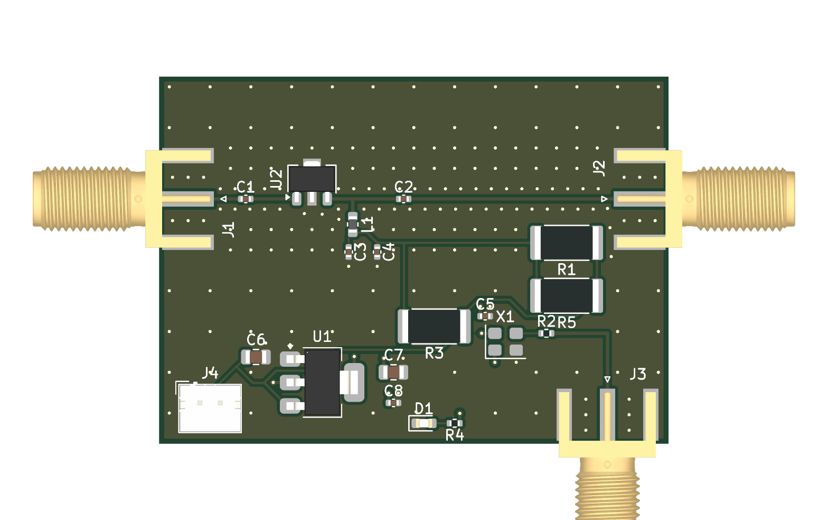
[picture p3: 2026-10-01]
examples/rf-frontend/audit/renders/rffe-top.png

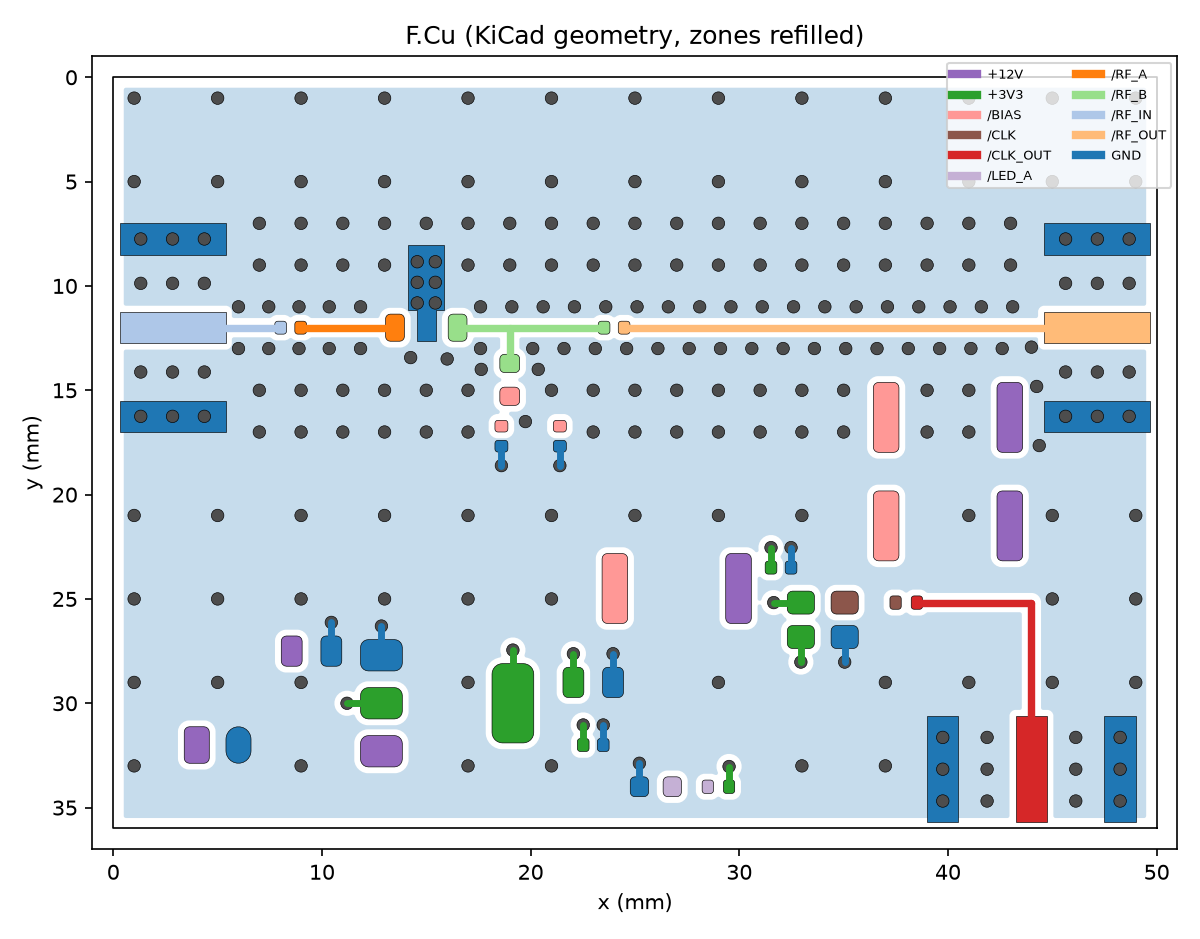
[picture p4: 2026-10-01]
examples/rf-frontend/audit/renders/placed/copper-F_Cu.png

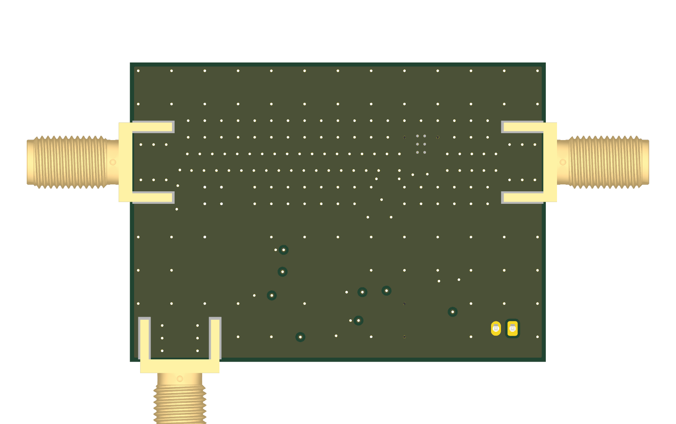
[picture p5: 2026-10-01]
examples/rf-frontend/audit/renders/rffe-bottom.png

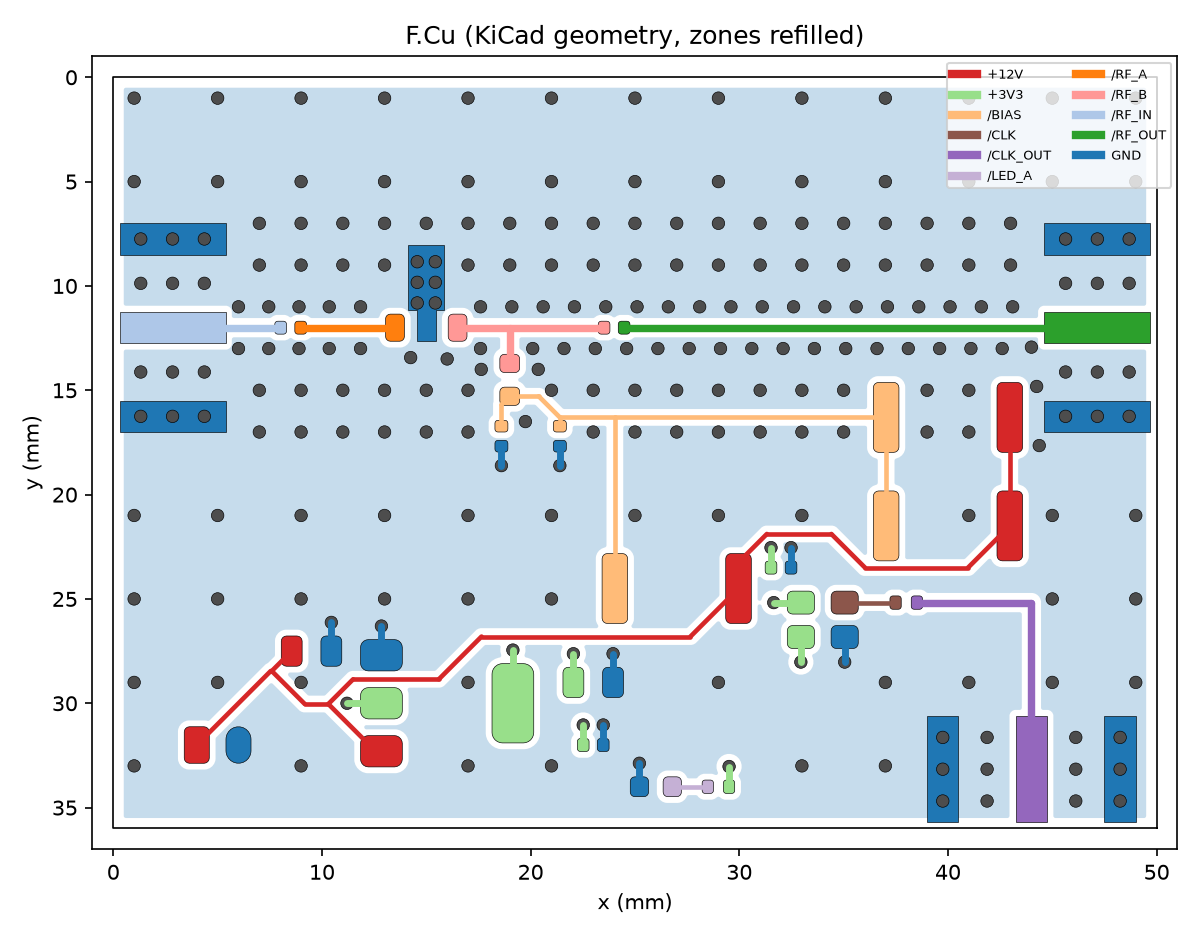
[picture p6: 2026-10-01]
examples/rf-frontend/audit/renders/routed/copper-F_Cu.png

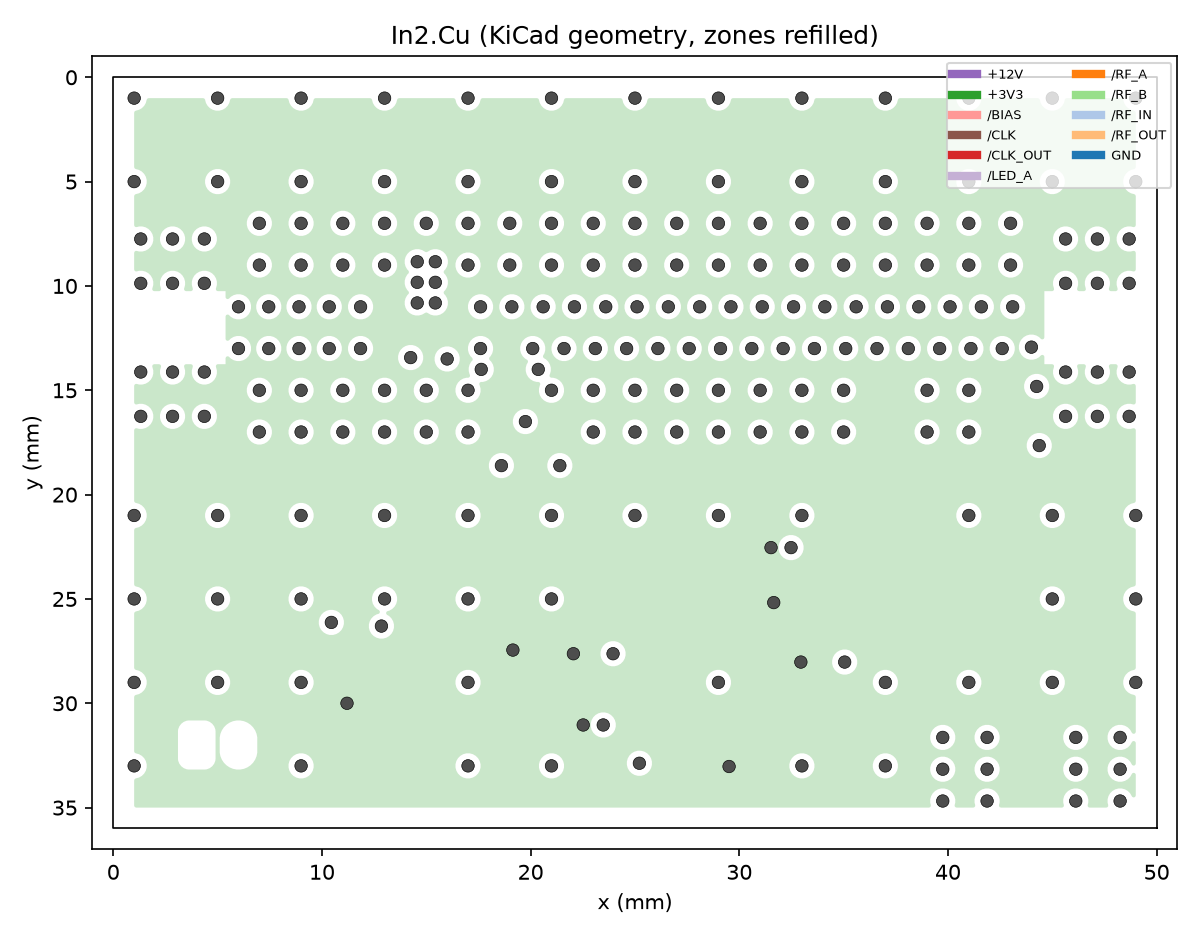
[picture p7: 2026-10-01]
examples/rf-frontend/audit/renders/placed/copper-In2_Cu.png

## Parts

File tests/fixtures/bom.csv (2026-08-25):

Reference | Value | Footprint | MPN | Qty
R1,R2 | 10k | R_0603 | RC0603-10K | 2
U1 | TPS562200 | SOT-23-6 | TPS562200 | 1
TP1 | TestPoint | TP_D1.5mm | DNP | 1

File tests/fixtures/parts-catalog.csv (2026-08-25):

mpn | description | qty | unit_price | currency | stock | lifecycle | distributor | accessed
RC0603-10K | resistor 10k 0603 1% | 10 | 0.01 | USD | 50000 | active | lcsc | 2026-08-26
TPS562200 | buck converter 2A SOT-23-6 | 10 | 0.85 | USD | 1200 | active | lcsc | 2026-08-26

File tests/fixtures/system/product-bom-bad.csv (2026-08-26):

item_id | category | description | qty | unit_price | currency | mass_g | mpn | source
PB-1 | pcb | FC board fab+assembly | 1 | 12.40 | USD |  | fc-pcba | JLCPCB
PB-2 | cots | Motor 2207 1750KV | 4 | 18.99 | USD | 32.1 | 2207-1750KV

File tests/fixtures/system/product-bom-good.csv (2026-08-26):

item_id | category | description | qty | unit_price | currency | mass_g | mpn | source
PB-1 | pcb | FC board fab+assembly | 1 | 12.40 | USD | 8.2 | fc-pcba | JLCPCB
PB-2 | cots | Motor 2207 1750KV | 4 | 18.99 | USD | 32.1 | 2207-1750KV | GetFPV
PB-3 | mech | Frame bottom plate FDM PETG | 1 | 3.10 | USD | 24.5 | frame-bot | print-farm
PB-4 | fastener | M3x8 socket A2 | 12 | 0.05 | USD | 0.9 | M3x8-A2 | McMaster
PB-5 | wire | XT60 pigtail 12AWG | 1 | 2.20 | USD | 9.0 | XT60-pig | GetFPV

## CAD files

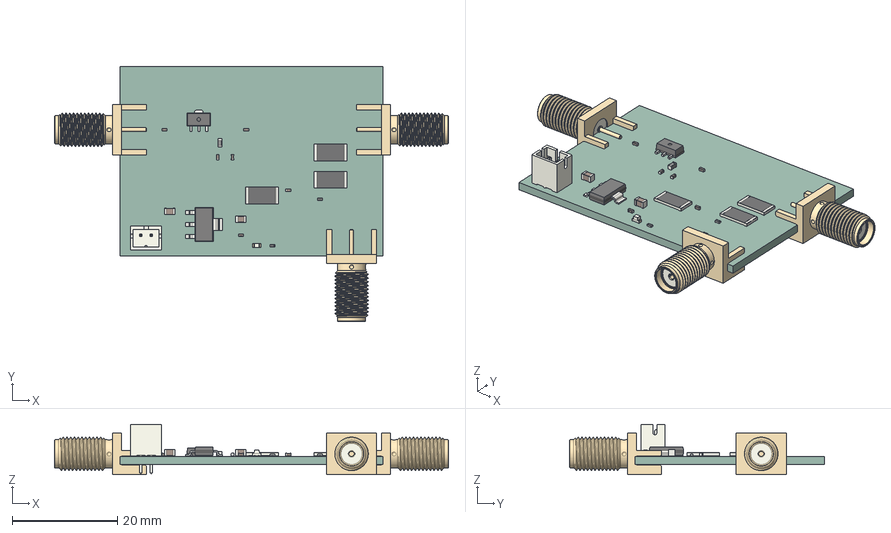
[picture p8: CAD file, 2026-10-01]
examples/rf-frontend/fab/rffe.step
74.8 x 48.4 x 9.58 mm
C_0402_1005Metric x 6
SMA_Amphenol_132289_EdgeMount x 3
SOT-223
C_0805_2012Metric x 2
R_2512_6332Metric x 3
JST_B2B_PH_K
L_0603_1608Metric
LED_0603_1608Metric
R_0402_1005Metric x 2
adbeea57-9c39-11ed-93f0-dde97e994e83_part
adbeea58-9c39-11ed-93f0-dde97e994e83_part
adbeea59-9c39-11ed-93f0-dde97e994e83_part
rffe_PCB

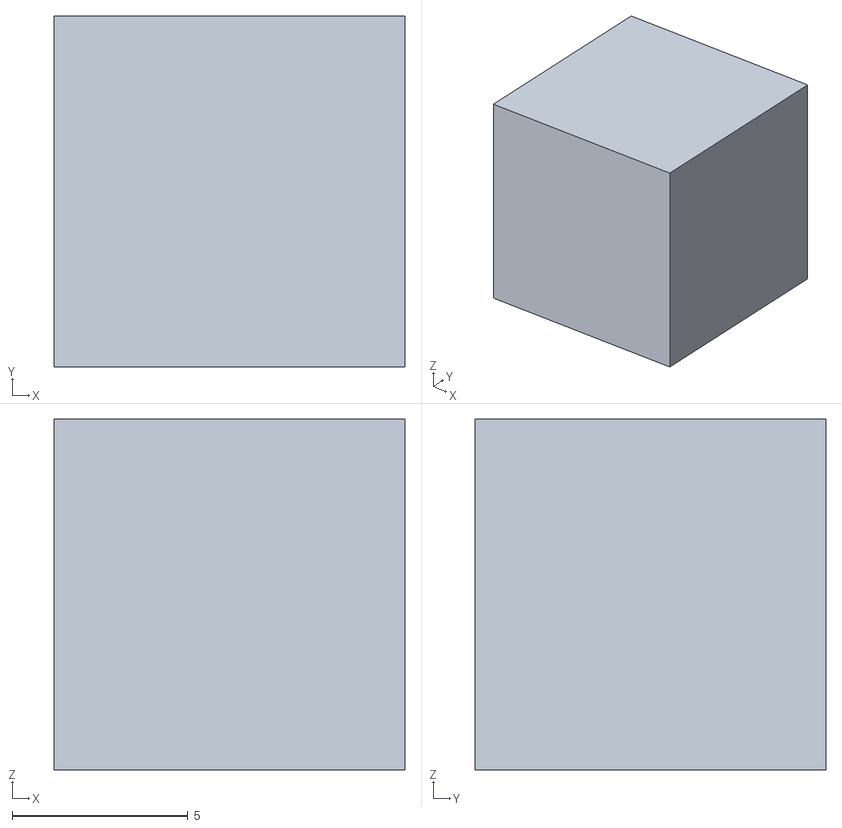
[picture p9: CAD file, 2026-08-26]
tests/fixtures/mech/cube-good.stl
10.0 x 10.0 x 10.0

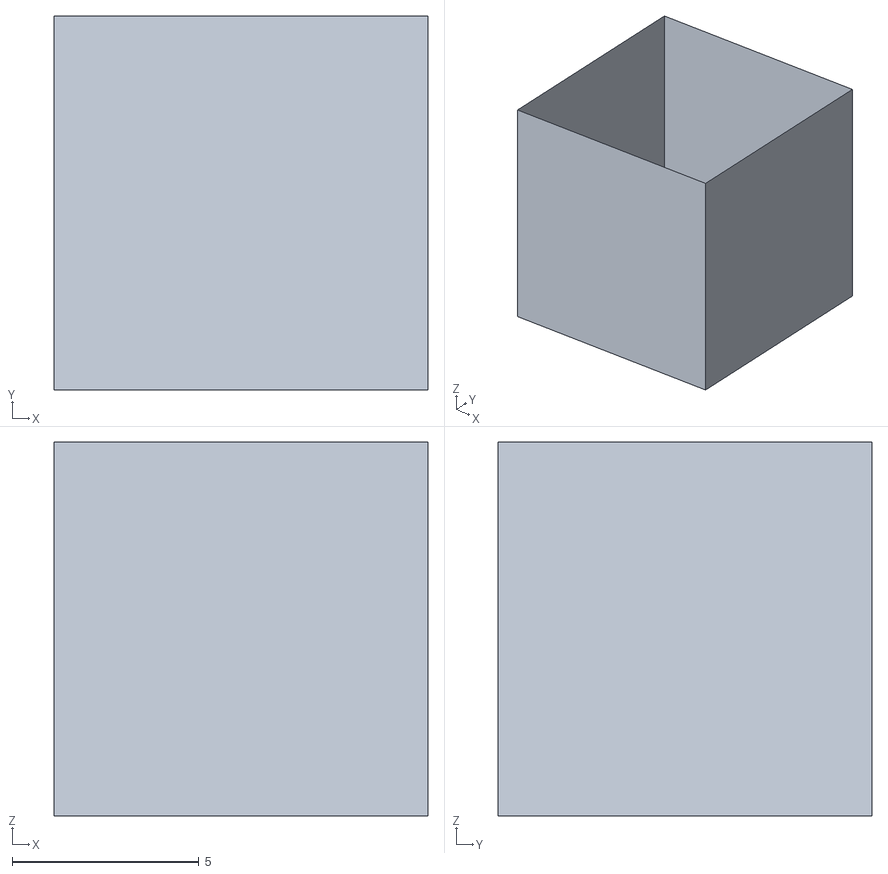
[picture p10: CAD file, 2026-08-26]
tests/fixtures/mech/cube-open.stl
10.0 x 10.0 x 10.0

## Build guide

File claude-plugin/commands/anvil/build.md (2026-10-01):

---
name: anvil:build
description: "Build a board or complete hardware product through concurrent engineering tracks and evidence-backed lifecycle gates"
argument-hint: "[Goal: ...|Spec: <file>] [Scope: <directory>] [Release: pcb|assembly|product] [Target: G0..G7] [Iterations: N]"
---

Execute the authorized build. Read the Anvil skill, lifecycle protocol, evidence protocol, and
the technical protocols relevant to the product. Default Target to G3 and infer release kind
from the intended deliverable; an enclosure, multi-board assembly, or integrated device is a
product. Do not confuse PCB fabrication, assembled-board readiness, and complete-product build.

1. Inspect existing files, repository instructions, and user changes. Resolve Anvil's actual
   installed paths. Run `doctor.sh`; use `--require-build` when KiCad/ngspice execution is
   needed, and `--require-product` only when CAD generation is needed. Missing tooling blocks
   dependent verification while requirements and other useful work continue.
2. For a new empty project, use `anvil.py init <scope> --scope <release-kind> --sectors ...
   --markets ... --features ...`. For an existing design, add the template files individually
   without overwriting its work. Preserve legacy ledgers as history; migrate them as unverified
   until their evidence meets the new contract.
3. G0/G1: establish intended use, users, environments, variants, commercial stop criteria,
   measurable requirements, owners, verification methods and due gates, risk register,
   supply assumptions, and destination classification. Populate `hrs/requirements.tsv` and
   `anvil-project.json`; use `plan <scope>` to create the required checks.
4. G2: baseline architecture and both ends of every electrical/mechanical/software interface.
   Resolve critical feasibility experiments, worst-case budgets and margins, component and
   technology choices, safety states, security/update architecture, test access, and supplier
   manufacturing feedback. Start firmware, fixture and compliance plans now.
5. G3: develop schematic/connectivity, circuit corner verification, layout, mechanical CAD,
   harnesses, sourcing, firmware build and compatibility records, assembly/test procedures,
   and manufacturer outputs concurrently. Read the protocol for each track. Render and inspect
   schematic/PCB/mechanical exports; never imply that a generated image was reviewed if unseen.
   Accuracy loop for every track: size parts from the rulebook and record each calculation in
   `design/rules.tsv` with its `TAG-nnn` source; write the golden netlist `sch/circuit.json`, run
   `anvil.py schematic sch/circuit.json pcb/<board>.kicad_sch` (wired, reloaded, netlist == spec, ERC) and
   add `W-1 golden ../sch/circuit.json` to `sch/connectivity.tsv`; declare `sim/plots.tsv` and run `plots`.
   View every render/plot you cite. Each modify→verify→keep/discard step is one `log <scope> iteration ...`
   row (metric, value, checks, result, rules); sources read go to `log research`, choices to `log decision`.
   Board loop: `board` the schematic onto the fabricator-stackup template, iterate `design/placement.tsv`
   (`place`) and routing (`route` copy or KiCad by hand) until `layout` (nets.tsv/rf.tsv), `si`, `pdn`,
   `thermal` and `emc` pass on the copper, then run `em` once on RF paths/antennas before release.
   Release each intent table as its artifact role so its `AUTO-*` check gates G3 (`sparams` gates G4 on
   VNA data). Report model limits verbatim; never state RF/EMC/thermal compliance from a simulation.
6. Install active custom rules as `<board>.kicad_dru` beside the matching `.kicad_pcb`,
   `.kicad_pro`, and `.kicad_sch`. The bundled JLCPCB example is a starting deck requiring
   current manufacturer review; no other manufacturer preset is supplied.
7. Fill `artifacts` with every controlled file and dependency, and `checks` with input command
   arrays. Run `manifest <scope>`, then `record <scope> AUTO-...` for applicable automated
   checks. Import actual signed/reviewed evidence with `record --evidence` for all other checks.
   The tool prints the applicable check IDs in `lifecycle-plan.json`; do not improvise IDs.
8. Evaluate `gate <scope> G3`. Resolve errors and design defects, regenerate the manifest after
   changes, and repeat affected runs/reviews. A metric helps prioritize work; it cannot waive
   a requirement. Never auto-fill physical tests or third-party approvals to finish the ledger.
9. For a later target, continue with `/anvil:lifecycle` through bring-up/EVT, DVT, PVT, and
   destination release. Complete all available work, identify specific external evidence still
   needed, and preserve blocked gates until it arrives. Do not label a prototype marketable.

If `Jev: shadow` is enabled, follow the skill's Jev triage reference for ambiguous findings
after step 8. Record its advice separately; it cannot update evidence or remove blockers.

At completion run `renders`, `fabpack` for each board and `report <scope>`; provide the scoped gate
result, the artifact package, `audit/AUDIT.md`, exact remaining blockers, and known verification limits. Write `handoff <scope> --write build --gate <target>`, then run
`validate-handoff.sh <scope>/handoff.json` before a requested chain. Validate source inputs and
gate again after any handoff change. Ordering, submission, deployment, and shipment require
the session's authorization for those actions; no repeated confirmation after authorization.

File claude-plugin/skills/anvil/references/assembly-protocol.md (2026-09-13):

# Manufacturing transfer, assembly and factory validation

## G3 assembly and bring-up preparation

Write sequential illustrated work instructions with part IDs/quantities, orientation, polarity,
tools, fastening/torque/adhesive requirements, inspection criteria and safe handling. Reconcile
every consumed part with the product BOM in both directions. Include harness routing/strain
relief, enclosure closure, firmware programming and calibration access. Supplier/process-specific
instructions control soldering, moisture, ESD, cleaning, seals and traceability.

The bring-up plan identifies configuration, serials, instrumentation, calibrated ranges,
current/voltage limits, staged power domains, safe outputs, expected observations, stop conditions
and rework capture. Hazardous energization, motion and battery testing need an actual approved
procedure, responsible operator and session action authorization. Do not reuse a drone, medical,
or mains procedure as a generic product default.

## EVT and DVT

Record first power, rails/clocks/reset, peripheral interfaces, programming/debug, core function,
fault states and integration with mechanics/harnesses. Tie raw results to unit serial, hardware,
firmware/bootloader, settings and rework. DVT uses representative production intent, justified
sample/corner/environment/reliability profiles and intended-user validation. Track deviations,
failures, corrective actions and regression results; a repaired prototype is not an untouched
production-intent sample.

## PVT and process transfer

Transfer released BOM/drawings, suppliers/alternates, firmware/programming, assembly and
inspection instructions, tooling, material handling and change controls. Qualify people and
equipment. `manufacturing/control-plan.csv` records operation, characteristic/limit, method,
fixture, frequency, owner, reaction plan and record. Select ICT/flying probe/boundary scan,
functional tests or other methods according to fault coverage and product constraints.

Demonstrate that tests detect representative defects and that measurements can distinguish
acceptable product: fault injection/known bad samples, repeatability/reproducibility, guardbands,
calibration/traceability and fixture maintenance. Validate provisioning, test privilege separation,
calibration schema, data upload, rework, retest and repair. Document cycle time, throughput,
capacity, first-pass yield, final yield, scrap, rework, escapes and acceptance targets.

## Executable factory record check

`factory <manufacturing-directory>` reads `acceptance.json`:

```json
{
  "hardware_revision": "A",
  "firmware_sha256": "<actual release binary SHA-256>",
  "minimum_units": 30,
  "first_pass_yield": 0.95,
  "fixtures": {"FCT-01": "3"}
}
```

The numbers above are examples; set justified pilot size/yield limits for the actual process.
Add this approved `acceptance.json` under the release artifact role `factory_policy` before PVT
recording. Changing a sample, yield, fixture or configuration criterion then invalidates the
release baseline and its reviews, instead of silently relaxing acceptance after a failed pilot.
`unit-records.csv` fields: serial, lot, hardware_revision, firmware_sha256, fixture_id,
fixture_revision, calibration_due, operator, timestamp, attempt, rework_reference, result,
measurement_record, provisioning_record. Timestamps include timezone. Calibration must cover
the actual test time. Each serial starts at attempt 1 with no omitted/duplicate attempts;
retest/rework needs a real disposition record. Evidence paths are relative to the factory folder.

The checker rejects mismatched configuration/fixture revisions, expired calibration, incomplete
records and hidden test attempts. It reports both first-pass and final yield; the agreed minimum
sample count, first-pass target and all units' final acceptance must pass. It does not measure
hardware or validate the factual truth of imported records. G6 also requires external review
of fault coverage, measurement qualification, provisioning and actual process capability.

Tie each shipped unit to its configuration, measurement/provisioning/calibration records and
release authority. Preserve failed attempts and nonconformances. Never copy a later configuration
over a historical unit record or log secret keys/passwords as provisioning evidence.

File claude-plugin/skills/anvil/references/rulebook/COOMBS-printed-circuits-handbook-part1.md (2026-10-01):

# Printed Circuits Handbook (7th ed.) — Anvil rulebook, Part 1 (Parts 1–3: technology drivers, supply chain/DFM/data exchange, base materials)

## 0. Citation

C. F. Coombs, Jr. and H. T. Holden (eds.), *Printed Circuits Handbook*, 7th ed. New York, NY, USA: McGraw-Hill Education, 2016. ISBN 978-0-07-183395-0 (print), 978-0-071-83396-7 (eBook).

Chapters covered by THIS extraction (text-file lines 1–4050):
- Part 1: Ch. 1 Electronic Packaging and HDI (Coombs/Holden); Ch. 2 Types of Printed Wiring Boards (Nakahara)
- Part 2: Ch. 3 Supply Chain Basics; Ch. 4 Design for Manufacturability; Ch. 5 Manufacturing Information, Documentation, Formatting, Exchange; Ch. 6 Supplier Selection and Qualification; Ch. 7 Process Control, Monitoring, Incoming Inspection; Ch. 8 Product Acceptance and Feedback (all Rodgers except Ch. 5 Holden)
- Part 3: Ch. 9 Introduction to Base Materials; Ch. 10 Base Material Components; Ch. 11 Properties of Base Materials; Ch. 12 Base Material Performance in PCBs; Ch. 13 Impact of Lead-Free Assembly on Base Materials; Ch. 14 Selecting Base Materials (Kelley/Trobough); Ch. 15 Laminate Qualification and Testing (Roesch/Ehrler) — see Coverage log for exactly where line 4050 falls.

Chapters NOT read: Ch. 16–71 and Appendix (lines 4051–16154) — assigned to three other agents (parts 2–4 of this rulebook).

Extraction limitation (important): the text extraction dropped nearly all tables and figures ("Images" placeholders) and all display equations. Only values stated in running prose could be captured. Where a rule depends on a missing table/graph/equation, it is marked `graph`/`table missing` and conf=medium or low.

Page numbers: the eBook extraction carries no printed page numbers; citations are by §chapter.section (and figure/table number where relevant).

## 1. Design rules

| id | domain | rule statement | formula / limit (units) | inputs | applicability & conditions | verify by | source | conf |
|---|---|---|---|---|---|---|---|---|
| COOMBS-1001 | requirements | Assembly complexity is measured as parts per unit area and leads per unit area; leads/in² = (avg leads per part) × (parts/in²) | leads_per_in2 = (I/O_total / N_parts) × (N_parts / A_board) | total I/Os incl. both sides + edge fingers; part count; board area (in²) | SMT assemblies; parts/in² ranges 1 to >100 | calc | §1.2.1–1.2.2, Fig. 1.2 | high |
| COOMBS-1002 | requirements | Component packaging complexity = average leads (I/Os) per part, counting all connections on both sides plus edge fingers/contacts, divided by total components | avg_IO = I/O_total / N_components (leads/part); range 2 (discretes) to very large (BGA/ASIC) | I/O_total, N_components | any assembly | calc | §1.2.2 | high |
| COOMBS-1003 | requirements | PWB wiring density metric = average trace length per unit board area including all signal layers, assuming three nodes per net | W_d in in/in² (or cm/cm²) | total trace length (in), board area (in²) | used as z-axis of the interconnect technology map; beyond the "HDI wall" region HDI becomes cost-effective/necessary | calc | §1.2.1–1.2.4, Fig. 1.2; detail in Ch. 16 | high |
| COOMBS-1004 | transmission-line | Systems operating above 25 MHz must have interconnections with transmission-line characteristics (stripline or microstrip), i.e. controlled conductor/dielectric geometry | f_sys > 25 MHz → treat nets as transmission lines | system clock/edge rate | digital systems; "many operate near 100 MHz" (historical) | review | §1.4.1 | high |
| COOMBS-1005 | transmission-line | Signal propagation speed is inversely proportional to sqrt(Dk); time of flight is proportional to conductor length — keep chip-to-chip conductors short | v ∝ 1/sqrt(Dk); t_flight ∝ L | substrate Dk, trace length | all high-speed nets | calc | §1.4.1 | high |
| COOMBS-1006 | pdn | Budget 20–30 % of chip terminals for power and ground; up to 50 % where high-speed signal isolation is needed; provide dedicated power/ground planes in MLBs for chips drawing tens of watts at 5 V, 3.3 V or lower | P/G pins = 0.20–0.30 × total pins (up to 0.50) | package pin count | high-speed / high-power chips (up to 30 W per chip cited) | review | §1.4.2 | high |
| COOMBS-1007 | cost | About 60 % of manufacturing cost is fixed in the first design stages when only 35 % of design effort has been spent; DFM/A during design can cut assembly cost up to 35 % and PWB cost up to 25 % | cost-lock-in: 60 % at 35 % of design effort; savings ≤35 % (assembly), ≤25 % (PWB) | — | product cost planning | review | §1.4.5.1 | high |
| COOMBS-1008 | dfm | Direct-chip-attach packaging efficiency (silicon area / substrate area) must be derated: flip-chip ≈90 %, wire-bond ≈70 %, TAB ≈50 %; on PWBs without unreinforced surface redistribution layers efficiency drops to 20–30 % | η_pkg ≤ 0.90 (FC), 0.70 (WB), 0.50 (TAB); 0.20–0.30 on plain PWB | attach method | bare-die on substrate; two-sided PWB assembly roughly restores parity | calc | §1.6.3, Fig. 1.5–1.6, Table 1.2 (table missing) | high |
| COOMBS-1009 | dfm | Reducing PTH pad diameter is more effective for wiring density than reducing conductor pitch: 55→25 mil pads (−55 %) doubled interconnection density, while 18→7 mil pitch (−61 %) gave only +50 % | example ratios as stated | pad dia (mil), conductor pitch Cp (mil) | PTH boards | calc | §1.7.1 | high |
| COOMBS-1010 | dfm | Base-material movement spec ≤300 ppm, but actual excursions ≈500 ppm → 10 mil layer movement over 20 in → annular ring ≥10 mil required; a 200 ppm laminate allows a 4 mil annular ring | Δ = ppm × L: 500e-6 × 20 in = 0.010 in; ring_min ≈ movement (10 mil @500 ppm, 4 mil @200 ppm) | laminate movement (ppm), panel dimension (in) | MLB registration budgeting | calc | §1.7.1 | high |
| COOMBS-1011 | stackup | Keep lamination temperature below the resin Tg of already-cured cores to avoid excessive material movement (resin remains in linear expansion phase); this is why high-Tg resins are used | T_lam < Tg_core | press temperature, core Tg | MLB lamination | review | §1.7.1 | high |
| COOMBS-1012 | dfm | Achievable wiring density per signal plane: 40–60 in/in² with 4–5 mil conductors and conventional PTH pads; 100–140 in/in² with "invisible" (padless, conductor-width) vias; 200–250 in/in² with 0.002 in conductors | W_d,plane = 40–60 / 100–140 / 200–250 in/in² | conductor width, via/pad style | per signal plane | calc | §1.7.1, Table 1.3 (table missing) | high |
| COOMBS-1013 | dfm | Signal-layer count needed = total wiring length / (W_d,plane × board area), rounded up to next whole layer | N_sig = ceil(L_total / (W_d,plane × A)); worked case: 50 in² MLB, 10,000 in wiring (Id = 200 in/in²) | L_total (in), A (in²), W_d,plane (in/in²) | layer-count estimation | calc | §1.7.1, Table 1.4 (table missing) | medium (formula derived from stated construction of Table 1.4) |
| COOMBS-1014 | dfm | Halving conductor width from 6 mil to 3 mil halves the number of signal layers for the same connectivity (yield, density and area held constant) | N_layers(3 mil) = 0.5 × N_layers(6 mil) | conductor width | 6 in × 8 in MLB, Id = 450 in/in², 65–68 % yields (Table 1.5, missing) | calc | §1.7.2, Table 1.5 | high |
| COOMBS-1015 | fab | Board yield falls rapidly when conductor width is reduced below 5 mil | w < 5 mil → steep yield loss (graph) | conductor width | conventional subtractive fab (Fig. 1.7, graph missing) | review | §1.7.3, Fig. 1.7 | medium (graph) |
| COOMBS-1016 | fab | Total yield splits into a conductor-density-dependent term and a process term; density term follows Poisson zero-defect probability over total conductor length | Y_total = Y_Id × Y_proc; Y_Id = P(n=0) = exp(−ν × TL); ν = avg defect frequency per unit length, TL = total conductor length | ν (defects/in), TL (in) | opens/shorts dominate density-dependent defects; ν rises as pitch Cp falls, → 0 for very large Cp | calc | §1.7.3, Fig. 1.8 | high (exp form implied by "Poisson, n=0"; display eq. missing) |
| COOMBS-1017 | fab | For padless ("invisible via") designs with Cp = 2w: Id = TL/A, Id × Cp = 1, TL = A/Cp; ν is an empirical power-law in Cp with facility-dependent exponent b | Id = TL/A; TL = A/Cp; ν = f(Cp, b) (display eq. missing) | A (in²), Cp (in), b (per process) | b must be determined empirically per facility/pattern process | calc | §1.7.3 | medium (ν form missing) |
| COOMBS-1018 | cost | MLB cost is almost linear in layer count (large quantity, yield and density constant); in transmission-line boards, each added signal layer effectively doubles layer additions because a ground/power plane must be interleaved | cost ∝ N_layers; N_total ≈ 2 × N_signal for controlled-impedance stacks | N_layers | 6 in × 8 in MLBs | calc | §1.7.4, Table 1.5 | high |
| COOMBS-1019 | fab | Finished MLB yield decreases with increasing layer count within every line-width category | Y = f(N_layers) decreasing (graph) | N_layers, line width | Fig. 1.9 (missing) | review | §1.7.4 | medium (graph) |
| COOMBS-1020 | dfm | Priority order to raise PWB density: (1) reduce hole and pad diameters, (2) reduce conductor width/space, (3) add signal planes, (4) add blind/buried vias — (4) is simplest but most costly; use only after (1)–(2) are exhausted | ordered list | — | density planning | review | §1.7 | high |
| COOMBS-1021 | cost | Hole formation can be up to 30 % of total PCB manufacturing cost; sequential build-up (SLC-type) can reduce an 8-layer conventional structure to 4 layers for the same packaging density | hole cost ≤ 0.30 × total; 8L → 4L | — | HDI trade study | review | §2.6.3.2.4 | high |
| COOMBS-1022 | fab | Pattern-plating process copper thicknesses: thin electroless Cu 0.00001 in followed by primary electroplate, or thick electroless 0.0001 in; solder (etch-resist) plate 0.0002 in (solder-etch case) or 0.0006 in (reflow case) | t_eless = 10 µin (thin) or 100 µin (thick); t_solder = 0.2 or 0.6 mil | — | subtractive PTH, pattern plating | inspect | §2.8.2 | high |
| COOMBS-1023 | fab | Panel-plating process: thin electroless Cu 0.0001 in, then electroplate 0.001–0.0012 in; minimum realizable conductor width for mass production by panel plating ≈0.004 in | t_eless = 0.1 mil; t_plate = 1.0–1.2 mil; w_min = 4 mil | — | panel plating (tent-and-etch or hole plug) | review | §2.8.3 | high |
| COOMBS-1024 | via | Pattern plating can form padless micro-via holes of 0.012–0.016 in diameter; panel plating is a difficult way to make padless vias | d_via = 12–16 mil padless | — | pattern-plated boards | review | §2.8.2–2.8.3 | high |
| COOMBS-1025 | cost | Silver-through-hole (STH) boards cost 1/2–2/3 of equivalent PTH boards but have relatively high hole resistance; use only for low-cost, high-volume products | cost_STH = 0.5–0.67 × cost_PTH | — | paper-phenolic / CEM boards | review | §2.6.2.2 | high |
| COOMBS-1026 | fab | Paper-based substrates: holes may be punched; glass-based substrates: holes must be drilled | — | substrate type | SSB fabrication | review | §2.6.1.2 | high |
| COOMBS-1027 | materials | Fine-line pattern plating benefits from ultra-thin copper foil (UTC), typically 1/8 or 1/4 oz, because only base copper must be etched | foil = 1/8 or 1/4 oz | — | fine-line subtractive boards | review | §2.8.2 | high |
| COOMBS-1028 | materials | Default rigid PCB construction assumed by suppliers: FR-4 laminate with 1/2 oz copper conductors; standard MLB copper is 1/2 oz outer / 1 oz inner | outer 0.5 oz, inner 1 oz | — | quoting baseline; deviations are price adders | review | §3.4.3, §4.4.3 | high |
| COOMBS-1029 | cost | Process cost allocation per unit = annual cost-center cost / annual units processed; rarely used processes carry higher per-unit rates | rate = C_annual / N_annual (example: $100,000 / 10,000 = $10/unit) | C_annual, N_annual | supplier cost modelling | calc | §4.2 | high |
| COOMBS-1030 | cost | Design-dependent cost = direct material (foil, prepreg, core, soldermask, deposited metal — gold is the only significant one) + allocated process cost, divided by first-pass yield | C_design = (C_material + Σ C_process) / FPY | material list, process list, FPY | PCB and PCA | calc | §4.2, Fig. 4.3 | medium (relationship stated in prose) |
| COOMBS-1031 | cost | Supplier pricing matrix baseline inputs: laminate type, outer surface finish, minimum conductor width, minimum hole size, board size, layer count; anything nonstandard is a price adder | — | those six parameters | quoting | review | §4.2 | high |
| COOMBS-1032 | cost | Cost drivers that add price vs. baseline (magnitudes in missing Figs. 4.5–4.27): laminate type, panel utilization, layer count, board thickness (nonstandard cores), gold finish/fingers, thickness tolerance, hole-size tolerance, impedance tolerance, inner/outer Cu thickness, inner/outer min line width, min trace length at min width, min drilled hole size, aspect ratio, annular ring, hole plugging, beveling, plated edges/slots, manual processes | qualitative list | design parameters | quoting/DFM | review | §4.2–4.4 | medium (graphs missing) |
| COOMBS-1033 | cost | Drilling cost is quoted per hole and depends on drill stack height, which is set by board thickness and minimum hole diameter; minimize total hole count | cost_drill ∝ N_holes / stack_height(t_board, d_min) | N_holes, t_board, d_min | all drilled boards | calc | §4.3, §4.4.2 | high |
| COOMBS-1034 | dfm | Probability of an open or short rises with the total length of minimum-width conductor: use narrow conductors only where required and widen traces in low-density areas | P(defect) ∝ L_at_min_width | trace widths, lengths | all boards | inspect | §4.4.2 | high |
| COOMBS-1035 | dfm | Narrow lines/spaces on thick copper are a yield risk: etching may not hold both cross-section and full copper removal | flag: thick Cu AND narrow L/S | Cu weight, min L/S | esp. power/ground layers used for signal routing | review | §4.4.2, §4.4.3 | high |
| COOMBS-1036 | via | Small vias increase wiring density but plating thickness is harder to achieve (mass-transfer limit), worse for thick boards (high aspect ratio); small drill bits are fragile | trade-off; see aspect-ratio rules elsewhere | hole dia, board thickness | all drilled vias | review | §4.4.2 | high |
| COOMBS-1037 | via | For a fixed pad size, a smaller drilled hole gives a larger annular ring (margin for breakout/misregistration); a larger hole eases plating and drill stack height — choose by supplier capability | ring = (D_pad − d_hole)/2 | D_pad, d_hole | — | calc | §4.4, Fig. 4.18 | high |
| COOMBS-1038 | cost | Adding signal layers usually costs more than enlarging the board when size is unconstrained; double-sided assembly is usually cheaper than a larger PCB; increase wiring density per layer rather than adding layers only while inside the supplier's yield "sweet spot" | decision rules | supplier capability | DFM trade studies | review | §4.4.3 | high |
| COOMBS-1039 | dfm | First-pass PCB yield is predicted by a single Complexity Index combining board area, layer count, min conductor width and min via diameter via a supplier-specific regression; higher index → lower yield | Y_FP = f_supplier(Complexity Index) (definition in Ch. 16) | area, layers, min width, min via | per-fabricator regression from actual yields or coupons | calc | §4.5, Fig. 4.28–4.29 | medium (definition outside range) |
| COOMBS-1040 | dfm | Design with generally available ("open source") materials and processes so the design can transfer between suppliers; avoid optimizing for one supplier's exotic capability | — | BOM/process list | assurance of supply | review | §4.5.1 | high |
| COOMBS-1041 | process | Minimum fabrication data package: layer graphics per layer (RS-274X/ODB++/IPC-2581), drill data (Excellon) with spans/tolerances/plating for TH, NPTH, blind, buried; board outline & rout; stack-up (layer order); plus netlist (IPC-D-356) strongly advised | checklist | — | every fab release | inspect | §5.2.1, §5.3.2.1 | high |
| COOMBS-1042 | process | Fabrication drawing must state: material, stack-up diagram with dielectric separations, controlled-impedance requirements (ohm value, tolerance, frequency and impedance model), solder mask type, legend color, fabricator ID/UL/ESD/country-of-origin marking, dimensional datum and tolerances, test/electrical expectations, bow/twist, board thickness ± tol, plating type/thickness, conductor width/spacing allowances, coupon locations, X-out policy | checklist | — | every fab release | inspect | §5.2.1, §5.3.2.1.2 | high |
| COOMBS-1043 | process | Drill drawing/tool file must give for each tool: size, plating status, tolerance, layer-from/layer-to (for blind/buried), total count | checklist | — | every fab release | inspect | §5.2.1 | high |
| COOMBS-1044 | process | Do not use Gerber 274-D with separate aperture tables (no units/scale, arbitrary D-codes, no aperture standard); use 274-X (FS command defines coordinates; apertures embedded) or, better, ODB++ / IPC-2581 with embedded netlist | — | output format | data exchange | inspect | §5.4.2.1, §5.7 | high |
| COOMBS-1045 | process | Excellon drill files must have units (in/mm) and decimal format explicitly declared; the translator otherwise guesses | — | drill file header | data exchange | inspect | §5.4.2.1 | high |
| COOMBS-1046 | process | Never output self-intersecting polygons (SIPs) for planes with cutouts in 274-X; draw islands with positive polarity and holes with negative polarity, or decompose into positive surfaces | polygon edges may intersect only at endpoints of consecutive edges | plane layer output | CAM import will fail with "Self Intersecting Polygon" error; resizing and copper-area calc are unreliable on SIPs | inspect | §5.4.2.1.2, Fig. 5.12–5.13 | high |
| COOMBS-1047 | process | Output plane layers as negative, not positive, layers (listed among the top causes of CAM problems) | — | plane layers | Gerber flows | inspect | §5.7 | high |
| COOMBS-1048 | test | IPC-D-356 netlist: one fixed-length record per line, max 80 characters; "317" = drilled-hole records, "327" = SMD pad records; N/C in net-name field = not connected; use IPC-D-356A if buried passives are present (after verifying supplier readability) | — | netlist file | bare-board e-test and CAD-to-CAM verification | inspect | §5.4.2.2.3, Fig. 5.16 | high |
| COOMBS-1049 | process | Component placement list minimum columns: reference designator, x, y, rotation (plus optional package, part number, SMT/TH) | — | CPL file | assembly data | inspect | §5.4.3.1 | high |
| COOMBS-1050 | process | Assembly data package: outer-layer graphics (copper, mask, legend), drill info, board outline/dimensions, placement with rotations, BOM + AVL (AVL not needed for consigned parts), mechanical hardware locations, schematics (HPGL/DXF) for test, plus test/material/packaging instructions | checklist | — | every assembly release | inspect | §5.3.3 | high |
| COOMBS-1051 | cost | Material cost is 30–40 % of total PCB cost and scales with panel area processed: pick the panel size that maximizes shippable-product utilization; nest/rotate odd profiles | utilization = A_shippable / A_panel → maximize | board profile, panel sizes (Table 5.1 missing) | panelization | calc | §5.5.5.1 | high |
| COOMBS-1052 | dfm | Panelization spacing: minimum product-to-product spacing for depanelization typically 0.100 in; minimum panel border (edge-to-product) for tooling/registration typically 1.0 in | s_part ≥ 0.100 in; border ≥ 1.0 in | — | fabrication panels | calc | §5.5.5.1 | high |
| COOMBS-1053 | fab | Innerlayer AOI may be skipped when the design's min lines/spaces are at or above the level where the fabricator's inner-layer yield is 100 % (example threshold 0.008 in L/S) | if L/S_design ≥ L/S_100%yield → inspection optional | design min L/S, capability | innerlayer routing decision | review | §5.5.3 | high |
| COOMBS-1054 | process | Top causes of CAM-stage fabrication problems (fix at design): poor documentation; badly formatted drill files; 274-D with aperture tables; missing solder-mask clearance; inadequate drill-to-copper clearance; misaligned layers; inadequate manufacturing clearances; no IPC-D-356 netlist; positive plane layers; poor designer–fabricator communication | checklist | — | design review | inspect | §5.7 | high |
| COOMBS-1055 | process | Solder mask selection interacts with design: tented/plugged vias favour hole-plug epoxy over LPI + secondary plug; high external copper weight/plating density may exceed thin-mask coverage; post-mask processes can alter mask appearance | — | via treatment, Cu weight | mask selection | review | §5.5.2 | high |
| COOMBS-1056 | cost | Gold cost requirement per board = f(gold thickness × gold area) | m_Au ∝ t_Au × A_Au | t_Au, A_Au | ENIG/hard-gold boards | calc | §5.5.2 | medium |
| COOMBS-1057 | process | Assess a fabricator's true capability with IPC-9151D (May 2012) PCQR2 benchmark panels (CAT 1 in × 1 in modules: conductor/space, via registration, via formation, soldermask registration, controlled impedance); ≥10 panels give statistically significant defect-density and yield estimates | N_panels ≥ 10 | — | supplier qualification; can also set in-house design rules | measure | §6.2.1.1, Fig. 6.1–6.10 | high |
| COOMBS-1058 | process | Only use suppliers with ISO 9001:2008 QMS certification from an accredited auditor (renewed ~every 3 years) and evidence of recent internal audits; 100 % electrical test on all shipped boards is expected | — | — | supplier selection | review | §6.2.3, §7.2 | high |
| COOMBS-1059 | reliability | Supplier/coupon reliability test menu: normal and accelerated thermal cycling, thermal shock, surface insulation resistance, resistance at high humidity, solderability, peel strength, Tg, hi-pot; coupons should use daisy-chained vias (highest-risk sites) | — | — | qualification & ongoing monitoring | measure | §6.2.3.1 | high |
| COOMBS-1060 | process | RFQ price quotes are typically valid ≤30 days; compare suppliers with simultaneous RFQs | validity ≤ 30 d | — | sourcing | review | §6.2.4 | high |
| COOMBS-1061 | process | Critical performance parameters (CPPs) for PCB acceptance: board width/length, pad height, plating thickness, through-hole diameter and location vs datum, fiducial location vs datum, trace impedance; call out tolerances on the drawing | — | — | acceptance planning | inspect | §7.2.1 | high |
| COOMBS-1062 | process | Process capability acceptance: Cpk ≥ 1.0 ⇒ 99.73 % in spec (0.27 % out); six-sigma Cpk ≥ 2.0 ⇒ ~2 nonconforming per billion; verify process is in control (no special causes) before centring/reducing variance | Cpk = min((USL−μ)/(3σ), (μ−LSL)/(3σ)); normal model: 99.74 % within ±3σ (text also states 67.26 % within ±1σ — sic) | μ, σ, USL, LSL | CPP capability studies | calc | §7.2 | high |
| COOMBS-1063 | test | Supplier outbound checks to require: CMM of critical dimensions vs datum, opens/shorts continuity, TDR controlled-impedance measurement, cross-sections for dielectric and plating thickness, IPC-A-600 visual, IPC-TM-650 methods for destructive/reliability tests | — | — | lot acceptance | measure | §7.5.1.3 | high |
| COOMBS-1064 | process | Sample-based outbound audit per AQL tables; on incoming failures raise to Inspection Level III, return boards for 8D/7-step root cause, and treat added supplier testing only as a temporary measure | — | lot size, AQL | incoming inspection (Table 7.22/8.2 missing) | inspect | §7.5–7.6, §8.3 | high |
| COOMBS-1065 | process | First-article inspection: sample size from the AQL table; FAI boards must be built with standard (not special) processing; segregate rejects and disposition via MRB (rework / scrap / use-as-is) | — | — | design qualification | inspect | §8.2–8.3 | high |
| COOMBS-1066 | process | Supplier scorecard metrics: % on-time (e.g., window 3 days early to 0 days late), lots rejected, audit score, CAR count/status, price vs reduction goals; formal business review at least once per year | on-time window: −3 d … 0 d | — | supplier management | review | §8.5 | high |
| COOMBS-1067 | materials | Specify rigid/multilayer base materials to IPC-4101 specification sheets (Tg, peel strength, volume/surface resistivity, moisture absorption, dielectric breakdown, permittivity, loss tangent, flexural strength, arc resistance); high-speed/high-frequency materials to IPC-4103 (typically Df < 0.005); HDI/microvia materials to IPC/JPCA-4104; foils to IPC-4562 | — | material callouts | fab drawing material notes | review | §9.2.2–9.2.4 | high |
| COOMBS-1068 | materials | Low-profile copper (chosen for signal integrity) reduces peel strength; when it falls below the IPC-4101 sheet value, document an agreed exception (AABUS) with the supplier | — | foil profile | low-loss designs | review | §9.2.2 | high |
| COOMBS-1069 | materials | FR-4 Tg classes: sheet 21 min Tg 110 °C; mainstream 130–140 °C (simple applications) and 170–180 °C (high layer count, very thick, improved thermal); halogen-free FR-4 sheets 92/94 (phosphorus FR), 93/95 (aluminum hydroxide); filled FR-4 sheets 99, 101, 126 (inorganic fillers to lower z-CTE) | Tg ≥ 110 / 130–140 / 170–180 °C | application | IPC-4101 sheet selection | review | §9.4.1–9.4.2 | high |
| COOMBS-1070 | materials | Degree-of-cure check for dicy-cured FR-4: run TMA/DSC twice with a post-cure cycle between; accept if Tg2 − Tg1 within ±5 °C; NOT valid for phenolic-cured or most new resin systems (they keep advancing) | |Tg2 − Tg1| ≤ 5 °C | Tg1, Tg2 | dicy FR-4 only | measure | §9.3.1.3 | high |
| COOMBS-1071 | materials | Time-to-delamination is tested by TMA at 260 °C (T260) and 288 °C (T288); shorter times correlate with lower Td and higher Tg | T260, T288 (min) | — | lead-free material screening | measure | §9.3.1.4 | high |
| COOMBS-1072 | materials | Td is defined at 5 % mass loss (TGA), but reliability depends on decomposition in the assembly window: traditional 140 °C-Tg FR-4 (Td 320 °C) loses 1.5–3 % mass in the lead-free peak range; dicy high-Tg FR-4 Td = 290–310 °C; enhanced FR-4 Td = 350 °C | Td(5 %) values as stated; lead-free window mass loss 1.5–3 % for traditional FR-4 | TGA curve | lead-free assembly, multiple reflow/rework | measure | §9.3.2, Fig. 9.6 | high |
| COOMBS-1073 | materials | Do not over-specify Td: beyond the level where the assembly peak temperature no longer approaches the decomposition range, higher Td adds no benefit and excludes cost-effective materials | — | T_peak, Td curve | material selection | review | §9.3.2 | high |
| COOMBS-1074 | materials | Higher Tg is not automatically better: total z-expansion depends on CTE above and below Tg (a lower-Tg, lower-CTE or filled material can expand less); select on expansion, Td, modulus, moisture, T260/T288 — not Tg alone | Δz_total = α_below × (Tg − T0) + α_above × (T_peak − Tg) (conceptual, Fig. 9.5) | Tg, α_below, α_above, T_peak | PTH reliability | calc | §9.3.1.4, Fig. 9.5 | medium |
| COOMBS-1075 | fab | High-Tg resins are harder/more brittle: expect slower drilling, shorter drill-bit life, reduced drill stack heights, lower peel strength, shorter T260/T288 | — | Tg | drilling process planning | review | §9.3.1.4 | high |
| COOMBS-1076 | materials | Undercured laminate shows more total z-axis expansion and stresses PTHs; require well/fully cured material (definitions: undercured, poorly cured, well cured, fully cured) | — | cure state | incoming/lamination QA | measure | §9.3.1.3 | high |
| COOMBS-1077 | compliance | UL FR-4.0 = brominated epoxy; FR-4.1 = non-halogen flame retardant with Br ≤ 900 ppm, Cl ≤ 900 ppm, Br + Cl ≤ 1500 ppm; both classes ≥ 50 % epoxy resin, ≤ 45 % inorganic filler, woven-glass reinforcement | Br ≤ 900 ppm; Cl ≤ 900 ppm; Br+Cl ≤ 1500 ppm; epoxy ≥ 50 %; filler ≤ 45 % | material composition | UL reclassification of FR-4 | review | §9.4.3 | high |
| COOMBS-1078 | materials | IPC-4101 laminate callout: L / sheet no. / 4-digit nominal thickness (metric: mm, tenths, hundredths, thousandths — "1500" = 1.5 mm; imperial: tenths of mils — "0591" = 0.0591 in) / 5-character cladding code (type-thickness/type-thickness) / thickness tolerance class (A, B, C micrometer without cladding; D microsection; K, L, M micrometer with cladding) / surface quality class (A, B, C, D or X) | — | — | drawing material callouts | inspect | §9.5, Tables 9.5–9.9 (missing) | high |
| COOMBS-1079 | materials | IPC-4101 prepreg callout: P / sheet no. / reinforcement type+style (e.g., E7628 = E-glass style 7628) / resin-content method (RC = % resin content, TW = treated weight, 00 = none) / flow method (MF resin flow %, SC scaled flow thickness, NF no-flow, RE rheological flow, DH delta-H, PC % cure, 00) / optional (VC volatile content, DY dicy inspection, GT gel time, 00) | — | — | prepreg specification | inspect | §9.6 | high |
| COOMBS-1080 | materials | Surface-quality grading: examine worst 50 mm × 50 mm at 10×; measure longest dimension of each foil indentation with ≥4× magnifier (referee 10×); assign points per Table 9.8 and grade on total points within 300 mm × 300 mm (Table 9.9) | areas as stated | — | laminate incoming inspection | inspect | §9.5 | high (tables missing) |
| COOMBS-1081 | materials | Prepreg must be stored temperature- and humidity-controlled: heat advances cure; moisture degrades curing agents/accelerators and trapped moisture causes blisters/delamination in lamination | — | storage conditions | prepreg handling | inspect | §9.7.2 | high |
| COOMBS-1082 | materials | Treater process controls: resin component concentrations, viscosity, cloth tension (no weave distortion), resin content (resin-to-glass ratio), degree of B-stage cure, cleanliness | — | — | prepreg manufacturing / supplier audit | review | §9.7.2 | high |
| COOMBS-1083 | fab | Laminate press controls: temperature-rise rate sets resin flow; cool-down rate drives warp/twist; time above cure-initiation temperature (and how far above) sets degree of cure; separator-plate cleanliness sets surface quality | — | press profile | laminate manufacturing / supplier audit | review | §9.7.3 | high |
| COOMBS-1084 | materials | Epoxy Tg classes: difunctional epoxies typically < 120 °C (simple double-sided boards or blend component); commercial epoxy laminates fall in Tg bands 125–145 °C, 150–165 °C, > 170 °C; epoxy blends reach > 190 °C; higher Tg/Td → higher material cost, longer press cycles, lower drilling productivity | Tg bands as stated | — | resin selection | review | §10.1.3–10.1.4 | high |
| COOMBS-1085 | materials | BT/epoxy: Tg 180–220 °C; good electrical/thermal/chemical resistance; standard for BGA substrates and CSPs; more brittle and higher moisture absorption than epoxy; cost rises with BT fraction | Tg = 180–220 °C | — | package substrates, high-density MLBs | review | §10.2.2 | high |
| COOMBS-1086 | materials | Cyanate ester: Tg ≈ 250 °C, good electricals and thermal stability, but expensive, special processing, very moisture-sensitive → niche only | Tg ≈ 250 °C | — | — | review | §10.2.3 | high |
| COOMBS-1087 | materials | Polyimide: Tg 260 °C (pure) to 220 °C (modified/toughened), very high Td; burn-in boards, aerospace/avionics, down-hole, military. Ritchey (Ch. 17) advises AGAINST polyimide for new designs: harder lamination, higher cost, and moisture absorption high enough to fail leakage tests unless baked dry and waterproof-coated | Tg = 220–260 °C | — | extreme-heat applications only | review | §10.2.4, §17.5.2 | high |
| COOMBS-1088 | materials | PTFE-based laminates for RF/microwave (best electricals, special processing, expensive) — use hybrid stacks (PTFE only on the layers that need it); PPE offers electricals superior to epoxy blends with good thermal performance for RF/wireless/high-speed computing | — | — | RF and high-speed stackups | review | §10.2.5–10.2.6 | high |
| COOMBS-1089 | compliance | RoHS restricts Pb, Cd, Hg, Cr(VI), PBB, PBDE. TBBPA (bromine reacted into the epoxy backbone) is NOT restricted and remains the majority flame retardant; WEEE may still require separation/special handling of any brominated-FR laminate at end of life; the base-material issue is process temperature compatibility, not substance compliance | — | material declaration | compliance review | review | §10.3, §13.2 | high |
| COOMBS-1090 | materials | Halogen-free flame-retardant trade-offs: ATH (cheap, easy to drill; lowers Td; needs high loading for UL94 V-0); melamine polyphosphate (cheap; higher moisture absorption; non-reactive); nitrogen resins benzoxazine / melamine-phenolic novolac (reactive, high Tg; less effective, hard to fully cure, brittle, less thermally stable); DOPO phosphorus epoxies (reactive; limit achievable Tg; costlier) and DOPO hardeners (allow higher Tg and Td). Evaluate moisture absorption, peel strength, Tg reduction, resin flow, mechanical/electrical properties and CAF resistance for any HF system; HF chemistry can lower Df | — | FR chemistry | halogen-free selection | review | §10.2.7, §10.3.2 | high |
| COOMBS-1091 | materials | Prefer reactive (backbone-bonded) flame retardants over additives/fillers: no leaching/solvent extraction and better retention of laminate properties | — | — | material selection | review | §10.3.2 | high |
| COOMBS-1092 | fab | Resin must absorb/fluoresce UV: laser-based AOI needs resin fluorescence to see the pattern, and very thin cores need UV blockers so exposure of one side does not print through to the resist on the other side (e.g., solder-mask imaging) | — | core thickness, AOI type | thin-core imaging | review | §10.4.2 | high |
| COOMBS-1093 | materials | Fillers: talc/silica fillers reduce z-axis CTE (most common use, offsets lead-free PTH stress); hollow glass microspheres reduce Dk; Pd-coated kaolin acts as electroless catalyst; some fillers accelerate drill-bit wear; performance depends on filler type, size, shape and loading | — | filler system | filled FR-4 selection | review | §10.4.3 | high |
| COOMBS-1094 | materials | Glass reinforcement: E-glass default; NE-glass and L-glass give lower Dk and Df at higher cost; S-glass is stronger but harder to drill; low-CTE glasses exist for chip-package substrates (Tables 10.3–10.4 composition/Dk/Df missing) | — | glass type | low-loss / low-skew designs | review | §10.5.1 | high |
| COOMBS-1095 | materials | Fabric geometry: filament codes D, DE, E, G most common; virtually all PCB cloth is plain weave; fabric count warp × fill: 1067 = 70 × 70 and 1086 = 60 × 60 ("square weave"), 1080 = 60 × 47; balanced counts reduce micro-Dk variation | counts as stated (yarns/in) | glass style | signal-integrity / skew planning | review | §10.5.3 | high |
| COOMBS-1096 | materials | Yarn nomenclature: US "ECD 450-1/0" = E-glass, Continuous filament (S = staple), D filament diameter, 450 × 100 = 45,000 yd/lb, 1/0 = singles yarn; twist suffix e.g. 3.0S = 3 turns/in, S direction (Z = opposite). SI "EC5 11 1X2" = E-glass, continuous, 5 µm filament, 11 tex (g per 1000 m), 1 strand × 2 plied | — | — | reading IPC-4412 fabric specs | inspect | §10.5.2 | high |
| COOMBS-1097 | materials | Thin/spread glass usage: smartphones/tablets use 1037 (1027 and 1017 growing); servers/telecom use 1080 and 106 with 1086/1067 growing; spread ("expanded") fabrics give uniform resin/glass distribution → uniform laser microvia ablation (glass-rich areas under-ablate, resin-rich over-ablate at one laser setting), better resin wet-out for CAF, thickness control, dimensional stability and lower skew; cost premium. Finished E-glass fabric is specified by IPC-4412 | — | glass style | HDI and high-speed stack-ups | review | §10.5.3, §12.11 | high |
| COOMBS-1098 | materials | Other reinforcements: glass matte (chopped strands 1–2 in) = CEM-3 core; aramid (negative axial CTE → lower composite x-y CTE; laser/plasma ablatable) for microvia/MCM-L; paper (FR-2, FR-3, CEM-1 core) permits punched holes | — | — | — | review | §10.5.4 | high |
| COOMBS-1099 | materials | Copper foil grades (IPC-4562): grade 1 standard ED; grade 3 HTE must meet elongation at 180 °C (typical 4–10 %) — use HTE for essentially all multilayer inner layers to resist foil cracking from z-axis expansion (most important for thick, high-resin-content boards); grade 7 wrought annealed (flex, highest ductility, random grain). RTF foils also meet HTE (Tables 10.7–10.11 missing) | HTE elongation 4–10 % @ 180 °C | foil grade | MLB inner layers | review | §10.6.1, §10.6.3, §12.3.1 | high |
| COOMBS-1100 | materials | Foil purity/resistivity (IPC-4562): untreated ED foil ≥ 99.8 % Cu (Ag counted as Cu); wrought ≥ 99.9 %; wrought max resistivity 0.155–0.160 Ω·g/m² depending on weight (ED values in Table 10.12, missing) | purity ≥ 99.8 % (ED), ≥ 99.9 % (wrought); ρ_wrought ≤ 0.155–0.160 Ω·g/m² | — | incoming foil spec | review | §10.6.4 | high |
| COOMBS-1101 | materials | Foil treatments: nodularization (Cu/Cu-oxide nodules for adhesion), thermal barrier Zn/Ni/brass several hundred Å thick (brown/gray/mustard; arsenic-free versions growing), passivation/anti-tarnish < 100 Å on both sides (chromate or organic; removed by normal pre-clean), silane coupling agents | barrier ≈ several 100 Å; passivation < 100 Å | — | foil incoming / process compatibility | review | §10.6.1.1–10.6.1.4 | high |
| COOMBS-1102 | materials | Reverse-treated (drum-side-treated) foil: treatment on the smooth side bonded to the laminate → finer etched lines, consistent dielectric thickness in thin cores (no tooth protrusion/electrical failure), lower HF loss; matte side out improves resist adhesion and lets fab drop mechanical scrubbing (better registration). Penalty: slightly lower peel strength | — | foil type | fine-line / thin-core / high-speed inner layers | review | §10.6.2, §12.3.2, §12.6.2.2 | high |
| COOMBS-1103 | materials | Foil profile: IPC-4562 defines standard, low-profile and very-low-profile classes (Tables 10.10 / 12.1 missing); newer ultra-smooth foils are unspecified and marketed as "VLP-n" where n = average roughness in µm (VLP-2 = 2 µm Ra); use ultra-smooth foils above ~10 GHz, verify supplier loss data | Ra given in µm | roughness | high-frequency designs | review | §10.6.1, §12.3.2, §12.3.5 | high |
| COOMBS-1104 | materials | Double-treated foil removes the inner-layer oxide step but tolerates no abrasion and makes contamination removal difficult — restrict handling | — | — | inner-layer process | review | §10.6.5.1 | high |
| COOMBS-1105 | fab | Rough foil profile lengthens etch time → more lateral etch → trapezoidal traces → lower fine-line yield and poorer impedance control; a rough profile also lengthens the skin-current path → more HF attenuation. Balance profile against adhesion | — | foil profile, line width | fine-line etching, impedance control | review | §10.6.1, §12.2 | high |
| COOMBS-1106 | materials | Worked TMA data for a filled, lead-free-compatible high-Tg FR-4: Tg = 154.45 °C; z-CTE α1 (below Tg) just over 45 ppm/°C; α2 (above Tg) just over 219 ppm/°C; total z-expansion 50→250 °C = 2.58 % | values as stated | — | reference point for filled FR-4 | measure | §11.2.1, Fig. 11.1 | high |
| COOMBS-1107 | stackup | Hybrid stack-ups (different base materials, or adjacent dielectrics with very different resin contents or dissimilar resin CTE/modulus) build x/y and z CTE-mismatch stress at lead-free temperatures and can delaminate — analyze mismatch of every adjacent-layer pair; avoid very high-RC prepreg next to very low-RC layers | — | per-layer CTE_xy, CTE_z, RC | hybrid / mixed-material stacks | calc | §11.2.1, §13.3.2, §14.2.1.2 | high |
| COOMBS-1108 | reliability | z-axis expansion controls PTH strain and pad deformation; other things equal, lower total z-expansion → better PTH thermal-cycling life; copper content in the PCB lowers effective z-expansion (Cu CTE ≈ 17 ppm/K) | — | material CTE, Cu content, thickness | PTH reliability | calc | §11.2.2, §15.5.2.2 | high |
| COOMBS-1109 | materials | Tg depends on method: Tg(DMA) > Tg(DSC) > Tg(TMA); use DSC for resin blends where TMA shows no clean slope change; polyimides (very broad transition, up to ~100 °C span) are harder by DSC than TMA; always record the method with a Tg value | ordering as stated | — | comparing datasheets | measure | §11.2.3, §15.5.2.1 | high |
| COOMBS-1110 | materials | Report Td at 1 %, 2 %, 5 % and onset, not only 5 %. Examples: low-Dk/Df material Td5% = 405 °C but Td1% = 336 °C, Td2% = 367 °C (gradual decomposition; still excellent lead-free performer); phenolic high-Tg FR-4 Td5% = 330 °C, Td1% = 326 °C, Td2% = 328 °C (excellent); dicy high-Tg FR-4 Td5% = 305 °C, Td1% = 297 °C, Td2% = 301 °C (only simplest lead-free use). A common spec of Td5% ≥ 340 °C is neither sufficient nor necessary | Td1/Td2/Td5 (°C) | TGA curve | lead-free material selection | measure | §11.2.4, §13.5.2, §14.3.2 | high |
| COOMBS-1111 | materials | T260/T288 interpretation: a 175 °C-Tg dicy epoxy shows shorter T260 than a 140 °C dicy epoxy yet better thermal-cycling life (lower expansion); enhanced (phenolic) FR-4 is better in both; T260 on PCBs << clad laminate < unclad laminate; in MLBs the resin/inner-copper interface fails first (oxide quality, lamination, prepreg condition) — long T260/T288 alone does not prove lead-free reliability | — | T260, T288 (min) | material screening | measure | §11.2.5, §13.5.4 | high |
| COOMBS-1112 | test | Peel-strength test conditions: strips ≥ 0.79 mm (0.032 in) wide for after-process-chemistry tests, 3.18 mm (0.125 in) for others; 1 oz cladding (plate thinner foil up to 1 oz); peel (lb/in) = Lm / Ws (Lm = minimum load, Ws = strip width); thermal stress = solder float 288 °C for 10 s; process-chemistry sequence: organic stripper 23 °C 75 s → 10 g/L NaOH 90 °C 5 min → 10 g/L H2SO4 + 30 g/L boric acid 60 °C 30 min → oil 220 °C 40 s → degreaser 23 °C 75 s; elevated-temperature test at 125 °C for FR-4; values in N/mm (Table 11.3 missing) | peel = Lm/Ws | — | laminate qualification | measure | §11.2.7 | high |
| COOMBS-1113 | materials | Peel-strength acceptance guideline (validate against product needs): as-received ≥ 1.0 N/mm; after thermal stress ≥ 0.8 N/mm; after process solutions ≥ 0.55 N/mm; at 125 °C ≥ 0.7 N/mm. Method IPC-TM-650 2.4.8 (pattern 5.8.3, e.g. 100 mm × 100 mm coupon with 4 mm strips); specimen 50.8 × 50.8 mm, ≥ 2 samples each in warp and fill; peel rate 2 in/min at 90°; condition B = 288 °C solder float 5–20 s under silicone grease; condition C = process chemicals. Value scales with foil thickness — always state it. Lower peel with VLP/RTF foil or polyimide (low elasticity) is not by itself a reliability defect | ≥ 1.0 / 0.8 / 0.55 / 0.7 N/mm | peel data | incoming and qualification | measure | §15.4.2, §11.2.7 | high |
| COOMBS-1114 | test | Water absorption (IPC-TM-650 2.6.2.1): 2 in × 2 in unclad, edges sanded, dry 1 h at 105 °C (105–110 °C), cool in desiccator, weigh, immerse on edge in distilled water 23 °C for 24 h, wipe, weigh; % = (wet − dry)/dry × 100; keep thickness similar across compared materials. Supplementary: weight gain after 60 min at 15 psi steam | % = (W_wet − W_dry)/W_dry × 100 | — | laminate qualification | measure | §11.2.8, §15.5.4.2 | high |
| COOMBS-1115 | compliance | UL 94 vertical burn classes: V-0 — each application self-extinguish ≤ 10 s, total ≤ 50 s over 10 applications, no flaming drips, no glowing > 30 s after 2nd flame; V-1 — ≤ 30 s each, total < 250 s, no flaming drips, glowing ≤ 60 s; V-2 — ≤ 30 s each, total < 250 s, flaming drips allowed, glowing ≤ 60 s | limits as stated | material UL card | flammability requirement on drawing | inspect | §11.2.9, §15.5.4.1 | high |
| COOMBS-1116 | materials | Insulation resistance: report volume resistivity (MΩ·cm) and surface resistivity (MΩ) after 96 h / 35 °C / 90 % RH ("96/35/90") and after 24 h / 125 °C ("24/125"); IPC-TM-650 2.5.17: 500 V DC, read after 60 s electrification, meter capable of 10^12 MΩ; specimen 101.6 mm square (> 0.51 mm thick) or 50.8 mm square (< 0.51 mm) with etched electrode pattern | conditions as stated | — | laminate qualification (Table 11.5 missing) | measure | §11.3.3–11.3.5, §15.5.3.2 | high |
| COOMBS-1117 | materials | Electric strength (perpendicular, V/mil; IPC-TM-650 2.5.6.2): 4 specimens 4 in × 4 in unclad; precondition 48 h in distilled water at 50 °C, then ambient distilled water ≥ 30 min (≤ 4 h); test at 23 °C under oil, 50–60 Hz, ramp 500 V/s; value falls with thickness. Dielectric breakdown (parallel to laminations, kV; 2.5.6): 3 in × 2 in specimens (2 machine, 2 transverse), two 0.188 in holes 1 in apart, same conditioning, typically > 50 kV. Both are instantaneous values — not long-term HV ratings | ramp 500 V/s; typical breakdown > 50 kV | — | HV clearance/creepage basis | measure | §11.3.6–11.3.7, §15.5.3.3 | high |
| COOMBS-1118 | materials | Dk/Df behaviour to model: Dk decreases with resin content; Df usually increases with resin content; Dk falls with frequency; Dk and Df rise with absorbed moisture; E-glass Dk is only mildly frequency-dependent so low-RC constructions vary less over frequency; Df rises with frequency and may show maxima; values depend on test method (same material measured 0.002–0.008 by four methods) — compare only same-method, same-RC data (Tables 11.4, 12.4–12.12 missing) | qualitative trends | RC, f, moisture | impedance/loss modelling | review | §11.3.1–11.3.2, §12.9.3, §14.4.3 | high |
| COOMBS-1119 | dfm | Density levers each impose a material requirement: finer lines/spaces → very-low-profile foil; more layers → thinner dielectrics, registration, dimensional stability; smaller via/pad/pitch → laminate stability plus thermally robust resin for small via-to-via distances (CAF, thermal) | — | — | density planning | review | §12.2 | high |
| COOMBS-1120 | materials | Thin foils for HDI outer layers: 5, 9 and 13 µm are most used; 3 µm processes exist; thin foil is plated up on outer layers; on inner layers thin foil is limited by current capacity and resistance | t_foil = 3/5/9/13 µm | — | HDI build-up layers | review | §12.3.3 | high |
| COOMBS-1121 | transmission-line | Skin depth approaches the average roughness of 0.5 oz foil above ~1 GHz; below ~1 GHz foil type barely changes loss, above it attenuation tracks roughness; ultra-smooth foils pay off above ~10 GHz | f > 1 GHz: roughness loss significant; f > 10 GHz: ultra-smooth foil | frequency, Ra | high-speed nets | review | §12.3.5, Fig. 12.2 (graph) | high |
| COOMBS-1122 | fab | Inner-layer oxide vs oxide-alternative roughness changes effective loss: same foil/resin measured Df 0.021 (smoother process A) vs 0.026 (rougher process B) at 1 GHz — specify/qualify the bond-treatment process on loss-critical boards | ΔDf = 0.005 at 1 GHz | process | high-speed boards | measure | §12.3.5, §14.4.2 | high |
| COOMBS-1123 | stackup | Laminate ply count by dielectric thickness: single-ply is standard up to 0.0050 in; 0.0050–0.0080 in single or multi by application; > 0.0080 in always multi-ply. Two-ply is demanded for mil/aero, for dielectrics between plane layers at different voltages (esp. thin < 100 µm cores) and between high-power planes; single-ply is cheaper with better thickness control | t ≤ 5 mil: 1 ply; 5–8 mil: either; > 8 mil: ≥ 2 plies | dielectric thickness, layer function | stack-up definition (Table 12.2 missing) | review | §12.4.1, §14.2.1.2 | high |
| COOMBS-1124 | stackup | 0.0080 in core options: 1 × 7628, 1 × 2313 + 1 × 2116 (asymmetric → curl-prone in conveyorized lines), 2 × 2116; prefer symmetric (balanced) constructions; for thin cores prefer higher glass content / thickest cloth for flexural stiffness, subject to electrical/CAF needs | — | construction | core selection | review | §12.4.3 | high |
| COOMBS-1125 | stackup | Resin content: lower RC → less z-expansion, better dimensional stability, warp resistance, thickness control; higher RC → lower Dk; a minimum RC per glass style is needed for wet-out/void-free laminate and CAF resistance. RC is by weight, so denser resins need a higher RC % for the same resin volume. Resin available for fill = prepreg thickness − glass thickness | V_fill ≈ t_prepreg − t_glass | RC, resin density | prepreg/core selection | calc | §12.4.2, §14.2.1.2 | high |
| COOMBS-1126 | stackup | Prepreg fill rule: use higher-RC prepreg against heavy-copper and signal layers, lower-RC against light-copper/plane layers; never allow "glass stop" (cloth pressed against inner-layer copper) — keep a resin buffer between copper and glass; for large copper-free areas on plane layers add copper fill or choose higher-resin-volume prepreg; single prepreg ply preferred except between planes at different voltages | — | Cu weight, copper density per layer, prepreg RC/thickness | every MLB stack-up | inspect | §14.2.1.2, Fig. 14.2 | high |
| COOMBS-1127 | fab | Dimensional-stability tests: four-corner targets measured before/after (a) etch, (b) bake 150 °C 2 h, (c) etch + bake. Most laminate movement in fab occurs in MLB lamination, which commonly reaches ≥ 185 °C (above Tg) — thin cores in high-layer-count boards are least stable | bake 150 °C / 2 h | — | registration budgeting | measure | §12.6.1 | high |
| COOMBS-1128 | fab | Levers to improve dimensional stability/registration: laminate press-cycle pressure reduction (less stored stress), controlled resin contents in the per-style optimum window, higher-Tg cores, RTF foil (drop scrubbing), nonwoven reinforcement, "kiss"/"soak" MLB press cycles designed from prepreg rheology, prepreg curable below the core Tg | — | — | high-layer-count boards | review | §12.6.2 | high |
| COOMBS-1129 | via | Resin-coated copper (RCC) for blind vias between layers 1–2 and n–(n−1): single B-stage layer, or C-stage + B-stage where the cured C layer guarantees a minimum dielectric separation to the next inner layer; organic-reinforced and photoimageable dielectrics are alternatives; laser formation is by far most common | — | — | HDI outer build-up | review | §12.7 | high |
| COOMBS-1130 | reliability | CAF risk model: needs bias + path + moisture; paths are hole-to-hole, hole-to-track, track-to-hole, track-to-track and hole-to-plane; two-step (path formation along resin/glass interface or hollow filament, then electrochemical copper-salt filament growth); risk rises as feature spacing falls; high-risk environments: automotive, military, aircraft, outdoor; low: office, low voltage | — | spacing, bias, T/RH | dense boards, high-voltage nets | review | §12.8 | high |
| COOMBS-1131 | reliability | CAF material factors: moisture absorption (threshold below which CAF unlikely), temperature, bias level, resin-to-glass wet-out, silane coupling agent matched to the resin, glass cleanliness, curing-agent chemistry, residual hydrolyzable chlorides (use high-purity resin), resin thermal stability and resin/glass CTE mismatch under lead-free reflow, hollow glass filaments | — | — | CAF-critical material selection | review | §12.8, §14.5.1 | high |
| COOMBS-1132 | fab | CAF fabrication factors: clean/rinsed inner layers (low ionic residue), controlled prepreg storage/shelf life, lamination vacuum/temperature/pressure for full wet-out, drilled-hole quality (avoid resin-glass fracture → plating wicking), controlled desmear and electroless (no attack of resin/glass interface) with good rinsing | — | — | fabricator audit | inspect | §12.8 | high |
| COOMBS-1133 | test | CAF test vehicle #1: 10-layer PCB, single-ply 2116 cores/prepregs; 65 °C/85 % RH or 85 °C/85 % RH; 10 V or 100 V bias; hole-to-hole (wall) spacings ≈ 10, 15, 20, 25 mil; holes in line with the weave are the relevant (worst) case; 25 coupons; 500–1000 h; fail = IR below a minimum or a one-decade drop; a 1 MΩ series resistor floors the reading at 10^6 Ω (reading 10^6 Ω = failed) | spacings 10/15/20/25 mil; 10/100 V; 65/85 or 85/85 | — | CAF qualification | measure | §12.8.1.1 | high |
| COOMBS-1134 | test | CAF example #2 (100 V, 85 °C/85 % RH): of four "CAF-resistant" FR-4s, three dropped to the 10^6 Ω floor by 500 h at 15-mil spacing; only the one with < 1 decade drop at both 15 and 25 mil passed — "CAF-resistant" marketing is not a qualification | — | — | — | measure | §12.8.1.2 | high |
| COOMBS-1135 | test | CAF example #3: identical resin, different glass cloth/treater controls → group 1: 40 % of coupons failed by 600 h (first at 400 h); group 2: 20 %; groups 3–5: none. Qualify the specific glass supplier + silane finish + treating process, not just the resin family (a laminate with alternate glass/silane failed almost immediately at 16-mil wall-to-wall) | — | — | CAF qualification scope | measure | §12.8.1.3, §14.5.2 | high |
| COOMBS-1136 | test | CAF coupon protocol (Alcatel-Lucent/HDPUG): 10-mil drilled holes at 16-mil and 20-mil wall-to-wall in both weave directions; precondition 3× lead-free reflow; 96 h at test T/RH before bias; 65 °C / 85 % RH / 100 V; minimum 500 h, preferred 1000 h; fail = one-decade drop from t0 or absolute IR < 10^8 Ω; failure-analyse every IR failure (non-CAF causes seen: immersion-silver surface residues, embedded rayon fiber, hollow filament) | 65 °C/85 %RH/100 V; ≥ 500 h; IR ≥ 10^8 Ω and < 1 decade drop | — | CAF acceptance | measure | §14.5.2 | high |
| COOMBS-1137 | transmission-line | Signal bandwidth ≈ 0.35 / t_rise (faster edge → wider bandwidth) | BW (GHz) = 0.35 / t_r (ns) | t_rise | material loss requirement | calc | §12.9.2 | high |
| COOMBS-1138 | transmission-line | Dielectric attenuation is proportional to sqrt(Dk) and to Df and grows with frequency; velocity ∝ 1/sqrt(Dk); lower Dk → longer rise distance → longer allowable unterminated length; loss degrades rise time (high-frequency components attenuated most) | α_d ∝ sqrt(Dk) × Df × f | Dk, Df, f | high-speed nets | calc | §12.9.1 | high |
| COOMBS-1139 | transmission-line | Loss-vs-width trade: for a 15 dB/m loss ceiling material A needs ≈ 8 mil lines while lower-loss material B allows ≈ 5 mil (Fig. 12.26, graph); wider lines are less lossy (skin effect) at the cost of density; eye simulations at 5 Gbps over 1 m, 50 Ω, 5-mil track show standard FR-4 eye nearly closed vs open eye for low Dk/Df (Fig. 12.24) | example: 15 dB/m → 8 mil (A) vs 5 mil (B) | Df, W | line-width/material trade | sim | §12.9.2 | medium (graphs) |
| COOMBS-1140 | materials | Lead-free phenolic/novolac FR-4s have higher Df than legacy dicy FR-4 at 2–5 GHz (wide spread among phenolics, some Dk variation); non-dicy/non-phenolic FR-4-class materials give lead-free thermal performance with Df better than dicy — for high-end "FR-4 application" frequencies with impedance control, do not assume phenolic FR-4 matches the old dicy electricals (Tables 12.6–12.10, 13.5 missing) | — | — | material substitution reviews | review | §12.9.4, §13.6.3 | high |
| COOMBS-1141 | transmission-line | Differential-pair skew from glass-weave micro-Dk: 40 ps and 80 ps of skew progressively close a 2.5 Gb/s eye; mitigations: spread/expanded glass (1067/1086 instead of 106/1080), low-Dk glass, rotate artwork relative to the weave (costly if it lowers panel yield), or low-skew resin systems whose Dk ≈ glass Dk (uniform Dk across resin contents, Table 12.12 missing) | skew examples 40 ps, 80 ps @ 2.5 Gb/s | glass style, data rate | differential pairs > ~2.5 Gb/s | sim | §12.11 | high |
| COOMBS-1142 | solder | Assembly thermal envelope: Sn/Pb eutectic melts 183 °C, peak 230–235 °C; SAC melts ≈ 217 °C, peak up to 260 °C (some processes ≈ 245 °C), rework higher; realistic lead-free design peak 260 °C (30–40 °C above eutectic profiles); boards see 2–3 to 5–6+ cycles (rework counted); require ≥ 5 cycles, 6+ for complex assemblies; rule of thumb: +10 °C doubles the resin degradation reaction rate | T_peak = 245–260 °C; N_cycles ≥ 5 (6+ complex) | assembly profile | base-material requirement | review | §13.2, §13.3, §15.1.1 | high |
| COOMBS-1143 | materials | Lead-free property set: survive assembly → Td, CTEs, moisture absorption, T260/T288, modulus; long-term reliability → CTEs, Tg, Td, moisture absorption. Total expansion (pre- + post-Tg) governs assembly survival; pre-Tg CTE governs field life because operating temperature stays below Tg | — | — | material selection | review | §13.3, §13.6 | high |
| COOMBS-1144 | materials | Tg vs expansion (Table 13.3 / Fig. 13.2): two materials with equal CTEs differ only by Tg — 175 °C Tg delays post-Tg expansion 35 °C vs 140 °C; a 150 °C-Tg reduced-CTE FR-4 (3.4 % total) ≈ a 175 °C-Tg standard-CTE FR-4 (3.5 %) yet is far more lead-free compatible because of its higher Td (the 175 °C one is dicy) — rank by total expansion and Td, not Tg | total expansion 3.4 % vs 3.5 % | Tg, α1, α2, Td | — | calc | §13.5.1 | high |
| COOMBS-1145 | materials | Multiple-reflow degradation: cycling to 235 °C peak causes little decomposition or DMA-Tg change in any FR-4 (but high-Tg dicy FR-4 modulus still declines steadily); cycling to 260 °C rapidly degrades dicy FR-4 (mass loss, DMA Tg and modulus fall, worst for high-Tg dicy); phenolic FR-4 is essentially unchanged (slight Tg/modulus increase) | — | peak T, cycles | reflow-cycle qualification | measure | §13.5.2, §13.5.5, Figs. 13.7–13.19 | high |
| COOMBS-1146 | materials | Water vapour pressure ≈ 400 psi at 230 °C and ≈ 700 psi at 260 °C — absorbed moisture is far more damaging in lead-free reflow (blister/delamination, resin micro-voids); assess storage and add pre-assembly bake when boards were stored uncontrolled | p_H2O ≈ 400 psi @ 230 °C; ≈ 700 psi @ 260 °C | storage history | lead-free assembly | review | §13.5.3, §14.2.1.1 | high |
| COOMBS-1147 | test | Moisture screening: 60 min in 15 psi steam then 20 s solder shock at 288 °C — most materials with 0.2–0.4 % absorption passed, a high-absorption halogen-free failed, one at ≈ 0.3 % showed defects → datasheet absorption correlates poorly; use functional reliability tests. Moisture from 5-day RT water soak or 7 days 35 °C/85 % RH was fully removable by 125 °C bakes (24–120 h) | 15 psi/60 min + 288 °C/20 s | — | material screening | measure | §13.5.3 | high |
| COOMBS-1148 | materials | Lead-free FR-4 class guidance: dicy high-Tg FR-4 — not compatible (only very limited use); dicy 140 °C FR-4 — thin, low-reliability boards at intermediate peaks only (slightly higher Td than high-Tg dicy); mid-Tg high-Td FR-4 — intermediate-complexity boards; high-Td + high-Tg + reduced-CTE (often filled phenolic) — broadest range incl. complex boards at 260 °C peak; non-dicy/non-phenolic for combined thermal + electrical needs (Table 14.3 by peak-temperature range missing) | — | board class, T_peak | material selection | review | §13.6, §13.7, §14.3.1.1 | high |
| COOMBS-1149 | test | Reflow-survival benchmark: 10-layer, 0.093 in (2.6 mm) "designed-to-fail" MLB, 1.5 min dwell at peak, 6 IR cycles; dicy high-Tg FR-4 showed defects from 240 °C peak; all dicy FR-4 (175 and 140 °C Tg) showed defects at 260 °C; high-Td 150 °C and 175 °C Tg materials survived 6 × 260 °C | 6 cycles; 1.5 min dwell; 240/260 °C | — | material qualification | measure | §13.6.1 | high |
| COOMBS-1150 | test | IST (Interconnect Stress Test): current-heated PTH daisy-chain coupons cycled RT ↔ 150 °C (typical) after preconditioning (as-is; 3× and 6× at 230 °C; 3× and 6× at 255 °C); failure = +10 % resistance. Reference vehicle: 14-layer, 0.120 in (3.1 mm), 0.012 in (0.30 mm) PTH, actual plating 0.8 mil (20.3 µm) vs 1.0 mil (25.4 µm) requested. Result: higher Td gave a larger life gain than lower CTE for this design; low CTE gains importance with thickness and tighter pitch; coupons at 1.0 mm and 0.8 mm hole pitch | fail = ΔR ≥ 10 %; cycles to 150 °C | — | PTH reliability qualification | measure | §13.6.2, §14.3.1 | high |
| COOMBS-1151 | fab | Balance thermal robustness with manufacturability: harder/brittle high-Td resins can fracture in scoring, routing and tight-pitch drilling, resist hole-wall texturing, and show resin recession or hole-wall pull-away; a laminate slash-sheet pass does not guarantee a reliable PCB — involve the laminate supplier and validate with test vehicles | — | — | material qualification | review | §13.5, §13.6, §14.3.2 | high |
| COOMBS-1152 | fab | Inner-layer hold between oxide/oxide-alternative and lay-up: store at 20 °C (68 °F) and ≤ 50 % RH (lower preferred), minimize hold time; same or cooler/drier for prepreg; some high-performance resins need dried cores (moisture interferes with cure); polyimide often vacuum-desiccated before lay-up; store lay-up books controlled and press promptly | 20 °C, ≤ 50 % RH | — | MLB lamination | inspect | §14.2.1.4 | high |
| COOMBS-1153 | fab | MLB lamination cycle rules: pre-lamination vacuum 15–30 min before heating (removes moisture/solvents; do not overheat during vacuum); design heat-rise from prepreg rheology to fill circuitry and wet the glass; after resin gels reduce pressure to 50–75 psi to relieve stress; cool slowly through Tg then faster below Tg (warpage/residual stress vs productivity) | vacuum 15–30 min; relief 50–75 psi | material rheology | every MLB press cycle | review | §14.2.1.5 | high |
| COOMBS-1154 | fab | Lead-free and high-speed resins are harder (higher modulus): re-optimize drill feeds/speeds, expect faster drill wear and lower hit counts; they are more chemically resistant: adjust swell/permanganate desmear per laminate supplier guidance; plasma desmear is required for most high-speed materials | — | material class | drilling/desmear setup | review | §14.2.1.6–14.2.1.7 | high |
| COOMBS-1155 | assembly | Non-HASL finishes (ENIG, ImAg, ImSn, OSP) involve no bake — one less moisture-removal step before assembly; lead-free HASL adds a hotter thermal cycle. Decide explicitly whether a pre-assembly bake is needed | — | finish, storage | assembly planning | review | §14.2.1.8 | high |
| COOMBS-1156 | materials | Categorize lead-free compatibility by: peak temperature (245 °C vs 260 °C — a 15 °C difference can flip the result), reflow/rework count (3×, 5×, 6×, 8×, 10×), layer count/thickness (thicker → more total expansion; thin high-RC dielectrics expand more), PTH size/aspect ratio/hole-to-hole pitch (≥ 2.5 mm thick with ≤ 0.8 mm pitch is the active test frontier), inner copper ≥ 2 oz (resin fill/viscosity). Some materials pass at 245 °C or 1.0 mm pitch but fail at 260 °C or 0.8 mm | thresholds as stated | design attributes | material rating matrix (Fig. 14.7) | review | §14.3.1 | high |
| COOMBS-1157 | fab | Prepreg melt viscosity depends on heat-rise rate: phenolic FR-4 106 prepreg minimum viscosity 732 Pa·s at 1 °C/min falling to 163 Pa·s at 3.5 °C/min; faster rise → lower minimum viscosity; high-speed resins have higher minimum viscosity → harder fill of thick copper; spread glass impedes resin flow-through from adjacent plies, so it is not preferred where resin must migrate to fill thick inner-layer copper | η_min = 732 Pa·s @ 1 °C/min → 163 Pa·s @ 3.5 °C/min (106 prepreg) | heat-rise rate, glass style, Cu weight | press-cycle design | review | §14.3.1, Figs. 14.4–14.6 | high |
| COOMBS-1158 | process | Use an IPC-4101 slash sheet as the baseline callout and document exceptions (e.g., peel strength with VLP foil); sheet limits apply to laminate, not to the finished PCB (PCB Tg may differ); a material meeting a sheet is not automatically lead-free reliable and vice versa — validate by test vehicle | — | — | fab-drawing material note | review | §14.3.2 | high |
| COOMBS-1159 | transmission-line | Foil-roughness/material loss simulation reference: 20 in single-ended stripline, 4 mil and 6 mil widths, ½ oz copper, four foil classes from standard to EVLP (extremely-low-profile), three resin systems, three frequencies (Tables 14.4–14.5 missing); 6 mil lines lose less than 4 mil | — | W, foil class, resin, f | loss budgeting | sim | §14.4.1 | medium (tables missing) |
| COOMBS-1160 | materials | OEM loss classes by Df: high-loss, standard-loss, mid-loss, low-loss, ultra-low-loss (Table 14.6 boundaries missing; ultra-low = very-low-loss resin + ultra-low-profile foil + low-Dk glass); cost rises as Df falls; prefer functional (multilayer insertion-loss) test data to laminate Dk/Df for > 10 GHz or loss-sensitive designs | — | Df / insertion loss | material class selection | review | §14.4.3 | high |
| COOMBS-1161 | test | Dk/Df measurement methods: SPDR and parallel-plate (IPC-TM-650 2.5.5.9) use unclad laminate and do not reflect PCB effective values; stripline resonator (IPC 2.5.5.5, Bereskin); IPC-TM-650 2.5.5.12 covers five PCB loss methods incl. SPP (TDR/TDT on high- and low-RC stack-ups) and SET2DIL (TDR/TDT, stripline & microstrip, reports insertion loss at 4 and 8 GHz, suited to volume manufacturing); laminate-level IPC 2.5.5, 2.5.5.1 (etched pattern), 2.5.5.2 need ≥ 3 samples (thickness sensitivity) | SET2DIL @ 4 and 8 GHz | — | material electrical qualification | measure | §14.4.3, §15.5.3.1 | high |
| COOMBS-1162 | test | CAF test conditioning: precondition coupons with lead-free reflow (many compatible materials improve; non-robust ones develop micro-voids); test as-received and after multiple reflow simulations; match coupon spacing/hole size/aspect ratio to the real design's minimum features (too stringent → excludes cheaper materials; too lax → misses risk) | — | design min spacing | CAF qualification | measure | §14.5.1, §14.5.3 | high |
| COOMBS-1163 | test | CAF glass-style sensitivity: 7628 historically worst; 106 and 1080 hard to fully wet; spread 1067/1086 easier; test both warp and fill orientations (warp bundles denser → harder to wet); hole-to-hole is the hardest feature | — | glass style | CAF qualification | measure | §14.5.1–14.5.2 | high |
| COOMBS-1164 | test | Initial Tg screen: ≥ 2 samples; measured Tg must match datasheet within instrument accuracy; Tg1 and Tg2 (rescan of same sample) within 7 °C (Ch. 15 acceptance) — Ch. 9 uses ±5 °C for dicy FR-4 and Ch. 15 TMA guidance asks for further testing if > 5 °C; Tg2 << Tg1 signals decomposition started during scan (confirm with Td); Tg1 << Tg2 signals undercure | |Tg2 − Tg1| ≤ 7 °C (≤ 5 °C tighter) | Tg1, Tg2 | incoming laminate screen | measure | §15.4.4, §15.5.2.1.1, §9.3.1.3 | high |
| COOMBS-1165 | test | Td by TGA (IPC-TM-650 2.3.40 / ASTM): dry specimen 2–20 mg; 5 °C/min to 150 °C, hold 15 min (establish dry base weight); 5 °C/min to 800 °C; Td = 5 % weight-loss temperature. Caveats: larger surface/volume ratio lowers apparent Td; non-decomposing filler/glass inflates apparent Td (loss is resin-only); also compare onset temperature — prefer high onset AND high Td5% | 2–20 mg; 5 °C/min; 150 °C/15 min; to 800 °C; Td at −5 % | — | material qualification | measure | §15.4.5 | high |
| COOMBS-1166 | test | Tensile modulus/strength (ASTM D882; IPC-TM-650 2.4.19 flex, 2.4.18.3 films): strips 152.4 mm × 15.7 mm, ≥ 10 samples, all copper removed, identical thickness/glass construction, cut then condition 23 °C / 50 % RH for 24 h, test warp and fill separately to break; tensile strength = max load / original min cross-section (MPa); elongation % = Δl/l0 × 100; Young's modulus (GPa) from tangent to linear region; average of 10 | — | — | FEA inputs / material comparison | measure | §15.5.1.1 | high |
| COOMBS-1167 | test | Flexural strength (ASTM D790; IPC-TM-650 2.4.4B): unclad, specimen size/span/speed per thickness in 2.4.4; resin-dominated (tensile is glass-dominated); compare only same-method data (Eq. 15.2 missing) | — | — | material comparison | measure | §15.5.1.2 | high |
| COOMBS-1168 | test | TMA Tg/CTE (IPC-TM-650 2.4.24C): specimen ≥ 0.51 mm thick, ≥ 2 from random locations, copper etched, surface lightly sanded, edges burr-free; precondition 2 h at 105 °C then desiccator; start ≤ 35 °C (23 °C recommended); 10 °C/min; run ≥ 30 °C past the transition (CTE scans to ≥ 250 °C); Tg = tangent intersection; report α1 (below Tg) and α2 (above Tg). Example scan: Tg 136.7 °C, z-CTE α1 ≈ 65 ppm/K, α2 ≈ 150 ppm/K; copper plating CTE ≈ 17 ppm/K; x-y CTE also by strain gauge (2.4.41.2, run one pre-cycle) | 10 °C/min; 2 h/105 °C precondition | — | material qualification | measure | §15.5.2.1.1, §15.5.2.2 | high |
| COOMBS-1169 | test | DSC Tg (IPC-TM-650 2.4.25C): solid specimen 15–25 mg (unclad recommended for signal), prepared before conditioning; precondition 2 h at 105 °C, ≥ 30 min desiccator; Al pan with crimped lid; start ≥ 30 °C below expected onset; 20 °C/min; run ≥ 30 °C past transition; Tg = midpoint (½ ΔCp) between tangents; example first scan 192.9 °C, second 195.3 °C (additional cure) | 20 °C/min; 15–25 mg | — | material qualification | measure | §15.5.2.1.2 | high |
| COOMBS-1170 | test | DMA Tg (IPC-TM-650 2.4.24.2): strip cut parallel/perpendicular to the weave, copper etched, stiff enough not to deform plastically; precondition as TMA/DSC (authors) or 23 °C/50 % RH 24 h (IPC); clamps torque-tightened; 1 Hz (6.28 rad/s); heat ≤ 2 °C/min in dry N2 or dry air; run ≥ 50 °C past transition; Tg = tan δ peak (Eq. 15.3 missing); example 193.17 °C | 1 Hz; ≤ 2 °C/min | — | material qualification (blends, polyimide) | measure | §15.5.2.1.3 | high |
| COOMBS-1171 | test | Solder-dip resistance (IPC-TM-650 2.4.23): 1¼ in × 1¼ in, 3 specimens each of never-clad, etched and as-clad surfaces; preclean 15 s in 10 vol-% HCl at 60 °C, rinse, dry; flux and drain 60 s; solder skimmed at 245 °C; insert/withdraw edgewise at 1 in/s, dwell 4 s, air-cool vertical; inspect for discoloration, resin loss, softening, delamination, blisters, measles, foil lift. For lead-free use raise temperature or dwell | 245 °C; 4 s; 1 in/s | — | initial thermal screen | measure | §15.5.2.3.1 | high |
| COOMBS-1172 | test | Solder-float resistance (IPC-TM-650 2.4.13): ≥ 2 random specimens, back-side copper etched, precondition 135 °C for 1 h (desiccator hold), float foil-down 10 s on solder at 260 °C (method A) or 288 °C (method B), tap off solder, clean, inspect for blister/delamination/wrinkle; to rank materials extend time incrementally or repeat to failure; this z-gradient test mimics wave soldering | 10 s @ 260 °C (A) / 288 °C (B) | — | initial thermal screen | measure | §15.5.2.3.2 | high |
| COOMBS-1173 | test | Time-to-delamination (IPC-TM-650 2.4.24.1): as-received clad specimen (TMA sample rules), ≥ 2; precondition 2 h at 105 °C, desiccator; ramp from ≤ 35 °C at 10 °C/min to the isotherm; hold 60 min or to failure; time counted from isotherm onset; failure = irreversible thickness change (record temperature if it fails during ramp); 260 °C for epoxy, 288 °C for lead-free-intended, polyimide and other high-temperature materials | 10 °C/min; hold ≤ 60 min; 260/288 °C | — | lead-free screening | measure | §15.5.2.3.3 | high |
| COOMBS-1174 | process | Two-tier laminate qualification: Tier 1 quick screen — surface/appearance (IPC-TM-650 2.1.2, 2.1.5), copper peel (as-received and post-thermal-stress), solder shock, Tg (rescan), Td; any failure rejects. Tier 2 — full characterization: tensile/flexural, peel after chemicals, TMA/DSC/DMA Tg, CTE x/y/z, solder dip/float, T260/T288, Dk/Df, surface/volume resistivity, electric strength/breakdown, flammability, water absorption, prepreg RC/flow/gel time; then board-level tests driven by product requirements (Table 15.4 plan missing) | — | — | new-material introduction | review | §15.3–15.6 | high |
| COOMBS-1175 | process | Manufacturability run for a new laminate: inner-layer (preclean, resist lamination, expose, develop/etch/strip, punch, AOI contrast, repair/weld settings, black-oxide/alternative bond strength), multilayer (IL drying, lay-up, press cycle, edge rout, dimensional stability → re-derive IL scaling factors), drill → deburr → desmear/plasma → electroless (hole-wall adhesion, inner-layer contact), solder-mask adhesion, finishes (ENIG, ImSn, ImAg: skip plating risk), routing/scoring; thin-core stiffness may break horizontal lines | — | — | new-material introduction | inspect | §15.7, Table 15.5 | high |
| COOMBS-1176 | process | Datasheet-stage red flags for a laminate: no complete data sheet, not yet in high-volume production, used by ≤ 1 PCB fabricator, no second source | — | — | material sourcing | review | §15.3.1 | high |
| COOMBS-1177 | materials | Apply cosmetic pit/dent surface classes (IPC-TM-650 2.1.2/2.1.5 point system over 300 mm × 300 mm; Tables 15.2–15.3 missing) only to areas that stay copper on the product — edge-connector fingers and very fine lines; > 90 % of foil is etched away, so do not reject a material on cosmetics alone | — | — | incoming laminate | inspect | §15.4.1 | high |
| COOMBS-1178 | cost | 75 % of recurring manufacturing cost is fixed by the design drawing and specifications (GE study); 60 % of manufacturing cost is set when 35 % of design engineering cost is spent | 75 % / 60 %-at-35 % | — | cost planning | review | §16.1.1, §16.2.1 | high |
| COOMBS-1179 | process | Expanded electronics design process (12 functions) adds: formal technology trade-off analysis at specification, feature trade-off selection for layout/fab/assembly, design advice during placement and routing, manufacturing audits of the finished layout ("verified design" from correlated models vs trial-and-error) | — | — | new product design | review | §16.3.1–16.3.2, Table 16.1 (missing) | high |
| COOMBS-1180 | process | Figure-of-merit producibility score: SCORE = Σ Cx × FWx, where Cx = normalized ranked-vote coefficient per factor (divide by smallest non-zero vote; zero-vote factors drop) and FWx = factor weighting 1 (easy) … 100 (impossible today) calibrated at 1/25/50/75/100. Example: C = (1.5 substrate size, 3.0 hole count, 4.0 min trace width), FW = (36, 18, 31) → SCORE = 54 + 54 + 124 = 232; calibrate pass/fail thresholds on scored historical products | SCORE = Σ Cx·FWx | factor table | producibility gate | calc | §16.4.3–16.4.4, Eq. 16.1 | high |
| COOMBS-1181 | dfm | Density equation: wiring demand W_d (total connection length needed, in/in²) must be less than substrate wiring capability W_c with margin. W_d > W_c → cannot route (enlarge board or remove parts); W_d = W_c → unacceptable layout time; W_d < W_c → goal; W_d << W_c ("sandbagging" with extra layers/finer traces) raises manufacturing cost 15–50 % | target: W_d < W_c (not <<) | W_d, W_c | every layout plan | calc | §16.5.1, Eq. 16.2 | high |
| COOMBS-1182 | dfm | Wiring capacity per signal layer = (tracks per channel × channels per unit width, from trace/space/via-land design rules and via structure) × layout efficiency; total W_c = Σ over signal layers; layout efficiency = W_d/W_c actually achieved, assume 50 % for planning (Table 16.2 detail missing; Eq. 16.4 missing) | W_c = Σ_layers (W_max,layer × ε); ε ≈ 0.5 | design rules, structure, ε | layer-count planning | calc | §16.5.3–16.5.4 | medium (equation missing) |
| COOMBS-1183 | dfm | Compute wiring demand for all three controlling cases and take the maximum: (1) breakout wiring of the densest component (flip-chip/CSP/BGA), (2) tightly linked component groups (CPU–cache, DSP–I/O), (3) all ICs and discretes collectively | W_d = max(W_breakout, W_cluster, W_total) | placement, pin counts | layout planning | calc | §16.5.2 | high |
| COOMBS-1184 | dfm | Wiring-demand models: Coors–Anderson–Seward statistical wire length (Eqs. 16.5–16.6 missing), Toshiba technology map (log-log plot of parts/in² vs leads/part gives W_d in in/in² and assembly complexity in leads/in²; Eqs. 16.7–16.8 missing), HP Design Density Index DDI = 13.6 × (EIC/in²)^1.53 with EIC = total leads / 14 (or 16, or 20); Rent's rule, section crossing, geometric analysis also cited. Worked example: 86 components, 1540 leads, 57 in² → EIC = 110 → 1.93 EIC/in² → DDI = 316.7 → chart (Fig. 16.13, missing) advises two tracks between pads on two signal layers | DDI = 13.6 × (EIC/in²)^1.53; EIC = leads/14 | leads, parts, area | design-rule / layer selection | calc | §16.5.5–16.5.6, Eqs. 16.9–16.10 | high (constants from worked example) |
| COOMBS-1185 | dfm | Complexity Index CI collects area, number of holes, minimum trace width, number of layers and minimum tolerance (absolute) into one metric (Eq. 16.11 missing; Holden, IPC Technical Review 1986); first-pass yield follows a Weibull-form FPY = f(CI; A, B) (Eq. 16.12 missing) where A sets the slope of the yield-curve inflection and B its x-position; fit A, B per fabricator from 10–15 running boards × ≥ 10 lots using transform x = log[log(CI)], y = log[ln(yield/100)] (sign as printed; must be log[−ln(Y/100)] for Y < 100): B = fitted slope, A = 10^(−intercept/slope); example fabricator A = 11.5, B = 9.0 (valid ~6 months) | FPY(%) ≈ 100·exp[−(log10 CI / A)^B] (implied by the printed transform) | CI, A, B | yield prediction | calc | §16.6.2, Eqs. 16.11–16.13, Fig. 16.14 | medium (form implied; CI formula missing) |
| COOMBS-1186 | cost | Fabrication complexity matrix (fabricator-supplied points per feature: board size/boards per panel, layers, material, trace/space, hole count, smallest hole, solder mask/legend, finish, gold fingers, design-specific; normalized by smallest non-zero cost; one company builds it per 18 in × 24 in panel). Price index PI = total design points / first-pass yield; PI 150 ↔ −70 % price, PI 1000 ↔ +275 % price (Fig. 16.15 curve missing) | PI = Σ points / FPY | matrix, FPY | price prediction | calc | §16.6.1, §16.6.3 | high |
| COOMBS-1187 | dfm | Consumer-board case: wiring demand showed 0.007 in trace / 0.008 in space two-track routing on a 0.100 in grid (printed "1.100-in") was more density than needed; one-track 0.012 in trace / 0.013 in space on two signal layers sufficed; removing 14 in² (via a gate-array ASIC) moved from 6-up to 8-up on an 18 × 24 in panel, cut CI 18 % and price 24.7 % | −18 % CI, −24.7 % price | — | DFM trade example | calc | §16.6.3.4 | high |
| COOMBS-1188 | assembly | Assembly complexity matrix factors: 1- vs 2-pass reflow, wave solder, manual vs automatic placement, odd-form parts, part quality level, connector placement, test coverage, diagnosability, stress testing, repair compatibility. IBM Assembly Report Card: 10 factors scored 0–35 points each; total maps to −30 % … +30 % assembly price; average scores rose from ≈ 50 to ≈ 75 within 2 years of use (higher = more producible) (Tables 16.12–16.13 missing) | 10 factors × 0–35 pts → ±30 % price | — | assembly DFM gate | calc | §16.7 | high |
| COOMBS-1189 | components | Fine-pitch SMT = lead pitch < 0.65 mm (25 mil), typically ASICs ≥ 160 pins; source of most SMT line defects (lead coplanarity, bent leads, insufficient solder, misalignment) — flag every fine-pitch part for joint designer/fab/assembler pad and process definition | pitch < 0.65 mm → fine-pitch flag | package pitch | assembly DFM | inspect | §17.4.3.1 | high |
| COOMBS-1190 | components | BGA consequences: joints need X-ray inspection, no touch-up (process must be near-perfect), special removal tooling, every ball pad typically needs its own via through the board (routing burden → more layers than fine-pitch QFP), package cost up to 3× fine-pitch SMT; robust in test/assembly vs fragile fine-pitch leads | — | package type | package selection | review | §17.4.3.2 | high |
| COOMBS-1191 | via | Mobile-class density: 0.4 mm (16 mil) pitch parts on both sides drive build-up PCBs with laser blind vias down to 0.1 mm (4 mil), ultrathin spread-glass dielectrics, and up to three build-up layers per side over a multilayer core | via ≥ 0.1 mm; ≤ 3 build-up layers/side (common) | pitch | HDI planning | review | §17.1, §17.2.6 | high |
| COOMBS-1192 | via | Backplanes to 28 Gb/s: press-fit PTH stubs add parasitic capacitance → back-drill unused hole portions; glass-weave and copper-roughness loss must be managed; press-fit avoids solder heat so much thicker boards are feasible | — | data rate, thickness | backplane design | review | §17.2.5 | high |
| COOMBS-1193 | components | Through-hole ICs are disappearing — avoid in new designs unless a secure supply is assured; keep TH for connectors, PGAs/sockets and high-dissipation parts needing heat sinks | — | BOM | part selection | review | §17.4.2 | high |
| COOMBS-1194 | assembly | Attachment-method process count: TH only → placement + wave; SMT one side → 1 reflow; SMT both sides → 2 reflows (design/test conflicts for vias and test points where parts overlap); SMT + press-fit/TH (most common) → reflow then wave or hand solder | — | — | assembly planning | review | §17.3 | high |
| COOMBS-1195 | process | Autorouters typically complete ≈ 80 % of nets (20 % hand-finished) unless given net-class rules; verify the DRC and that manufacturing output covers Gerber, ODB++ and IPC-2581; Gerber (Ucamco) needs separate NC drill and documentation, ODB++ (Mentor) and IPC-2581 (vendor-neutral) are single-package formats | — | — | tool selection / release | review | §18.2, §18.7 | high |
| COOMBS-1196 | process | Virtual-prototyping flow (right-first-time): select parts with IBIS models, worst-case timing, mechanical data, logic models, power/current-variation and thermal data → build/verify library models (second qualified checker; mirrored footprints are a classic error; IBIS may need hardware correlation) → simulate net classes pre-schematic → preliminary netlist → power-delivery analysis → routing-space estimate → stack-up → routing rules (technology table) → netlist with classes → logic simulation → placement → Manhattan-length extraction → timing → thermal → placement iteration → final rules (simulate multipoint nets) → route → post-route DRC → release → archive (on-site + off-site copies) | 20-step flow | — | high-speed design process | review | §19.2 | high |
| COOMBS-1197 | transmission-line | Pre-schematic net-class simulation needs only: assumed Z0 (almost always 50 Ω), driver/receiver IBIS or SPICE models, clock/data rate, estimated lengths → yields termination rule, worst-case voltage margin, load/termination timing effects per net class; simulate one member per class; reject drivers that cannot drive transmission lines | Z0 = 50 Ω (default) | models, rates, lengths | every high-speed net class | sim | §19.2.3, Fig. 19.3 | high |
| COOMBS-1198 | timing | Signal-layer count is usually set by the highest-pin-count IC; interconnect delay can exceed silicon delay (example: 3 ns worst-case silicon vs 6 ns wire) so timing analysis must run after placement using Manhattan (x-y) lengths and re-run after any placement change | check t_wire vs t_silicon | placement, lengths | timing closure | calc | §19.2.6, §19.2.12–19.2.13 | high |
| COOMBS-1199 | process | Pre-route checks: netlist matches schematic, no unintended inter-net connections, no unconnected single pins, no mechanical interference, every transmission line has its termination of the right type at the right location, every net has a driver and a load. Post-route checks: all nets routed, no shorts to signals/planes/terminals, length matching, net spacing, clearances to component and mounting holes; whole-board post-layout SI is "too late" except for a few critical nets | checklist | — | routing gate | inspect | §19.2.17–19.2.18 | high |
| COOMBS-1200 | transmission-line | SI risk triggers: driver edge rates faster than 2 ns make package/trace/via/connector L and C significant (many edges now < 100 ps); rise time defined 10–90 %; above ≈ 300 MHz lossy R and G per unit length matter; every transmission line needs a complete current loop supplied by distributed capacitance | t_r < 2 ns → parasitics matter; f > 300 MHz → losses matter | t_r, f | SI screening | review | §20.2.3 | high |
| COOMBS-1201 | stackup | Prefer symmetric (one signal layer between two planes) stripline for maximum crosstalk immunity; asymmetric (two signal layers between planes) is the alternative; an n-layer board offers 2 microstrip layers and up to n − 2 stripline candidates | — | stack-up | high-speed stack-ups | review | §20.2.4 | high |
| COOMBS-1202 | stackup | Dielectric constants for impedance models: typical PCB Dk 3.5–4.3; more expensive laminates ≈ 3.3; air/vacuum 1.0; solder mask Dk ≈ 3.3–3.4 → model outer traces as coated microstrip (conformal coating/thermal blankets also shift Z0) | Dk_PCB = 3.5–4.3; Dk_mask ≈ 3.3–3.4 | material | impedance calculation | calc | §20.2.4 | high |
| COOMBS-1203 | stackup | Copper thickness for impedance: ½ oz ≈ 0.7 mil before etch, ≈ 0.6 mil finished; 1 oz double; outer (plated) microstrip starts at 0.6–0.7 mil foil and is plated to ≈ 3× → 1.8–2.1 mil finished — use finished thickness in the impedance model; etched traces are trapezoidal (use an effective rectangular width) | T_inner(½ oz) ≈ 0.6 mil; T_outer ≈ 1.8–2.1 mil | copper weight, plating | impedance calculation | calc | §20.2.4 | high |
| COOMBS-1204 | transmission-line | Propagation: stripline in FR-4 (Dk ≈ 4.0) ≈ 5.8 in/ns (≈ half of c; use 6 in/ns); stripline delay = 85 ps/in × sqrt(Dk) → 10 in at Dk 4.0 = 1.7 ns; microstrip is faster (air above). Z0 typically 40–65 Ω; Z0 = sqrt(L/C) with L, C per unit length from the cross-section; IPC-4121 closed-form approximations; field solvers within ≈ 1 Ω for single-ended | v = 1/sqrt(L·C); t_pd = 85 ps/in × sqrt(Dk); Z0 = sqrt(L/C) | Dk, L, C, length | delay/impedance | calc | §20.2.5, Eq. 20.1 (display missing) | high |
| COOMBS-1205 | transmission-line | Impedance levers: wider W → lower Z0; thicker T → lower Z0; larger H → higher Z0; lower Dk → higher Z0 (or same Z0 with thinner H). Rule of thumb for 50 Ω microstrip in FR-4: W/H ≈ 2:1 (H = 3.5 mil → W ≈ 7 mil) | W/H ≈ 2 for 50 Ω FR-4 microstrip | W, T, H, Dk | quick impedance sanity check | calc | §20.2.6 | high |
| COOMBS-1206 | transmission-line | Reflection at any impedance change: Z2 > Z1 → positive reflection; Z2 = Z1 → 0 %; Z2 < Z1 → negative (standard form Γ = (Z2 − Z1)/(Z2 + Z1)); sources: stack-up variation, width changes, BGA breakouts, stubs, vias, loads, connector transitions, plane splits; far-end reflections re-reflect at the (low-impedance) source as anti-reflections → overshoot, undershoot, ringing. Significance scales with ΔZ, the length of the discontinuity relative to the path, and the technology's noise tolerance | Γ = (Z2 − Z1)/(Z2 + Z1) | Z1, Z2 | every discontinuity | calc | §20.2.7, §20.2.9, Fig. 20.8 | high (formula from figure; sign cases explicit) |
| COOMBS-1207 | transmission-line | Critical length: proposed rules limit line delay to 1/3, 1/4, 1/6 or 1/10 of the driver rise time; transition electrical length TEL (in) = t_r (ns) × 6 (in/ns) in FR-4; with the 1/6 rule, max unterminated length (in) ≈ t_r (ns) (a 1 ns edge → 1 in); simulation shows even 1 in still rings for a 1 ns driver — simulate rather than trust the rule | L_max(in) ≈ t_r(ns) (1/6 rule, FR-4); TEL = 6 × t_r | t_r | unterminated nets | sim | §20.2.8 | high |
| COOMBS-1208 | termination | Terminate any net with edge rate faster than ≈ 5 ns and length > 1 in. Triage: (1) SI-critical nets (clocks, strobes) need clean waveforms; (2) timing-critical (address/data) may ring but must meet timing; (3) any signal with edge < 5 ns; slower nets can be ignored. Reference: 5-in trace — 10 ns and 5 ns edges clean, 2.5 ns and 1 ns ring; for a 1 ns driver 5 in bad, 1 in better, 0.5 in better still | t_r < 5 ns AND L > 1 in → terminate | t_r, L | net triage | sim | §20.2.10.1–20.3 | high |
| COOMBS-1209 | termination | Termination selection: parallel DC (R = Z0 to a rail; one part; most power, loads driver); parallel AC (R + series C; less DC power; extra part, value tuning); series/source (R_s + Z_driver = Z0; one part; driver Z uncertain; receivers must cluster at the far end, mid-line receivers see a half-amplitude plateau/skew); Thevenin (two rails, lower DC current). Use source termination for point-to-point unidirectional, far-end for multipoint, distributed for variable plug-in systems; parallel AC suits daisy chains; star nets: branches equal delay and impedance, branches > ¾ in → make parallel branch impedance equal the inbound line, expect to need a stronger driver (24 mA vs 8 mA) | R_parallel = Z0; R_series = Z0 − Z_drv | topology, Z0, Z_drv | every terminated net | sim | §20.3, Figs. 20.12–20.14 | high |
| COOMBS-1210 | crosstalk | Spacing rules: "3W" (space ≥ 3 × trace width) and "3H" (space ≥ 3 × dielectric height to nearest plane) — both widen buses; 4 mil / 4 mil autorouting yields 20–60 mV crosstalk; move noise-sensitive victims to > 6 mil spacing; for two parallel 5-in lines NEXT/FEXT curves flatten at ≈ 7 mil spacing (diminishing return beyond) | S ≥ 3W or S ≥ 3H; S > 6–7 mil for sensitive nets | W, H, S | bus routing rules | calc | §20.3.1, §20.3.3, Fig. 20.19 | high |
| COOMBS-1211 | crosstalk | Capacitive trace-to-trace coupling falls quadratically with distance to the reference plane: traces within 4 mil of a plane are much more immune than at ≥ 6 mil; symmetric stripline (two planes) beats microstrip; capacitive crosstalk scales roughly linearly with Dk; reducing copper from 1 oz to ½ oz alone is not significant | XT_cap ∝ H² (approx.), ∝ Dk | H, Dk | stack-up for noise-sensitive buses | sim | §20.3.4, §20.3.5 | high |
| COOMBS-1212 | crosstalk | Bus crosstalk case (LineSim, 200 mV budget): W = 6 mil, S = 8 mil, 12 in parallel, Dk 4.3, H 5 mil, 1 oz, 590 ps aggressor edges → FEXT +600 / −660 mV. Halving coupled length to 6 in: no reduction (peaks move in time). S 8 → 12 mil: ±400 mV. ½ oz + Dk 3.8 + H 4.5 mil (holding Z0 ≈ 50 Ω): +211 / −230 mV (> 60 % better). W 5 mil + H 3.75 mil (Z0 ≈ 50 Ω): ≈ 200 mV. Adding S 9 mil: +160 / −170 mV. Final rule: W 5 mil, Dk 3.8, H 3.75 mil, S 9 mil | resulting rule W5/H3.75/S9/Dk3.8 | W, S, H, Dk, T, t_r, L | parallel bus design | sim | §20.3.4.1–20.3.8, Table 20.1 (missing) | high |
| COOMBS-1213 | pdn | PDN droop (insufficient decoupling charge) propagates between planes as an RF wave that radiates at board edges, vias and even upward through packages → EMI; SI, PDN and EMC physics are coupled — passing functional test does not imply passing EMC (unterminated fast clocks that ring show up as emissions months later) | — | — | design reviews | review | §20.1 | high |
| COOMBS-1214 | timing | Receiver thresholds: Vih = guaranteed switch-high voltage, Vil = guaranteed switch-low; region between is indeterminate — any excursion (undershoot/ringing) back across a threshold is false clocking; thresholds also enter flight-time calculations in the timing budget | check waveform vs Vih/Vil with margin | Vih, Vil, simulated waveform | SI acceptance | sim | §20.2.1 | high |

## 2. Formulas & tables (numbers)

All values below are transcribed from running prose; the book's own tables/figures are absent from the text extraction (noted per item).

### 2.1 Density, yield and cost formulas (Ch. 1, 4, 16)

| quantity | formula (ASCII) | symbols / units | source | conf |
|---|---|---|---|---|
| Assembly complexity | leads_per_in2 = avg_IO × parts_per_in2; avg_IO = IO_total / N_parts | IO_total counts both sides + edge fingers; parts_per_in2 range 1 … >100 | §1.2.2 | high |
| Wiring density per plane (achievable) | 40–60 in/in² (4–5 mil lines, PTH pads); 100–140 in/in² (invisible/padless vias); 200–250 in/in² (2 mil lines) | in/in² per signal plane | §1.7.1 | high |
| Signal layers needed | N_sig = ceil(L_total / (W_plane × A)) | L_total = total wiring length (in), A = board area (in²), W_plane (in/in²); book case: 10,000 in on 50 in² | §1.7.1 (Table 1.4 construction) | medium |
| Registration-driven annular ring | ring_min ≈ ppm_movement × L_panel; 500e-6 × 20 in = 0.010 in; 200e-6 → 0.004 in | ppm = laminate movement; L = panel span (in) | §1.7.1 | high |
| Density-dependent yield | Y_total = Y_Id × Y_proc; Y_Id = exp(−ν × TL) | ν = defects per unit conductor length; TL = total conductor length; Poisson P(n=0) | §1.7.3 | high (exp form implied) |
| Padless design relations | Cp = 2w; Id = TL/A; Id × Cp = 1; TL = A/Cp | Cp = conductor pitch; w = width; A = area | §1.7.3 | high |
| Process cost allocation | rate = C_annual / N_annual (e.g. $100,000 / 10,000 = $10 per unit) | — | §4.2 | high |
| Design-dependent cost | C ≈ (C_material + Σ C_process) / FPY | FPY = first-pass yield (fraction) | §4.2 | medium |
| Cost lock-in | 60 % of mfg cost fixed at 35 % of design effort; 75 % of recurring mfg cost fixed by drawing/specs | — | §1.4.5.1, §16.1.1 | high |
| Producibility figure of merit | SCORE = Σ_x Cx × FWx; example 1.5×36 + 3.0×18 + 4.0×31 = 232 | Cx normalized vote coefficients; FWx = 1 … 100 | §16.4.4 | high |
| EIC density | EIC = leads_total / 14 (alt. 16 or 20); EIC_density = EIC / A | A in in² | §16.5.5.1.4, Eq. 16.10 | high |
| HP Design Density Index | DDI = 13.6 × (EIC_density)^1.53; example 13.6 × 1.93^1.53 = 316.7 | EIC_density in EIC/in² | §16.5.6, Eq. 16.9 | high |
| Wiring capacity | W_c = Σ_layers (W_max,layer × ε); ε (layout efficiency) ≈ 0.5 default | W_max from tracks/channel and design rules (Eq. 16.4 missing) | §16.5.3–16.5.4 | medium |
| Density balance | require W_d < W_c (margin); W_d << W_c costs +15–50 % | — | §16.5.1 | high |
| Complexity index | CI = f(area, hole count, min trace width, layer count, min tolerance) — Eq. 16.11 not in text | — | §16.6.2 | low (form missing) |
| First-pass yield vs CI | regression transform: x = log10(log10 CI), y = log10(ln(Y/100)) [sic: needs −ln for Y<100]; B = slope; A = 10^(−intercept/slope) ⇒ FPY(%) ≈ 100·exp[−(log10 CI / A)^B]; example A = 11.5, B = 9.0 | Y = yield %, CI complexity index | §16.6.2.1–16.6.3.2 | medium |
| Price index | PI = Σ complexity points / FPY; PI 150 ↔ −70 % price; PI 1000 ↔ +275 % price | — | §16.6.3.2–16.6.3.3 | high |
| Assembly report card | 10 factors × 0–35 points; total → −30 % … +30 % price | — | §16.7.2 | high |
| Panelization | utilization = A_shippable / A_panel (maximize); part-to-part ≥ 0.100 in; border ≥ 1.0 in; material = 30–40 % of cost | — | §5.5.5.1 | high |
| Process capability | Cpk ≥ 1.0 → 99.73 % in spec; Cpk ≥ 2.0 (six sigma) → ≈ 2 ppb out; ±3σ = 99.74 %; ±1σ printed as 67.26 % [sic; 68.27 % is the normal value] | — | §7.2 | high |

### 2.2 Transmission-line / SI numbers (Ch. 12, 20)

| quantity | value / formula | conditions | source |
|---|---|---|---|
| Bandwidth | BW = 0.35 / t_rise | t_rise 10–90 % | §12.9.2 |
| Velocity | v ∝ 1/sqrt(Dk); FR-4 stripline ≈ 5.8 in/ns (use 6) | Dk ≈ 4.0 | §12.9.1, §20.2.5 |
| Stripline delay | t_pd = 85 ps/in × sqrt(Dk); 10 in @ Dk 4 → 1.7 ns | — | §20.2.5 |
| Dielectric loss | α_d ∝ sqrt(Dk) × Df, rising with f | — | §12.9.1 |
| Z0 range | 40–65 Ω typical; Z0 = sqrt(L/C); field solver ± ~1 Ω; IPC-4121 approximations | single-ended | §20.2.5–20.2.6 |
| 50 Ω microstrip rule | W/H ≈ 2 (H 3.5 mil → W ≈ 7 mil) | FR-4, uncoated | §20.2.6 |
| Reflection | Γ = (Z2 − Z1)/(Z2 + Z1); >0 if Z2 > Z1 | — | §20.2.7 |
| Critical length | TEL = t_r(ns) × 6 in/ns; L_max ≈ TEL/6 = t_r(ns) inches (1/6 rule); alt. rules 1/3, 1/4, 1/10 | FR-4 | §20.2.8 |
| Termination trigger | t_r < ~5 ns and L > 1 in | — | §20.3 |
| Edge-rate waveform reference | 5 in trace: 10 ns, 5 ns clean; 2.5 ns, 1 ns ring; 1 ns: 1 in better, 0.5 in best | Fig. 20.10–20.11 (graphs) | §20.2.10 |
| Crosstalk spacing | 4/4 mil → 20–60 mV; > 6 mil for sensitive; curves flatten ≈ 7 mil (5 in parallel) | — | §20.3.3 |
| Crosstalk vs plane distance | capacitive coupling ∝ ~H²; H ≤ 4 mil much better than ≥ 6 mil; ∝ Dk (linear) | — | §20.3.4 |
| Bus case study | see COOMBS-1212 (600/−660 mV → 160/−170 mV) | 590 ps edges, 12 in | §20.3.4.1–20.3.8 |
| Copper thickness | ½ oz: 0.7 mil pre-etch, 0.6 mil finished; outer plated 1.8–2.1 mil | — | §20.2.4 |
| Dk values | PCB 3.5–4.3; premium ≈ 3.3; solder mask 3.3–3.4; air 1.0 | — | §20.2.4 |
| Skin-depth threshold | skin depth ≈ Ra of ½ oz foil above 1 GHz; ultra-smooth foil pays off > 10 GHz | — | §12.3.5 |
| Oxide roughness effect | effective Df 0.021 (smooth) vs 0.026 (rough) @ 1 GHz | same foil/resin | §12.3.5 |
| Skew | 40 ps / 80 ps skew close 2.5 Gb/s eye progressively | differential pair | §12.11 |
| Loss vs width | 15 dB/m ceiling: ~8 mil (material A) vs ~5 mil (material B) | Fig. 12.26 (graph) | §12.9.2 |
| Eye simulation setup | 5 Gbps, 1 m, 50 Ω, 5-mil track | Fig. 12.24 | §12.9.2 |
| SET2DIL report points | insertion loss at 4 GHz and 8 GHz | IPC-TM-650 2.5.5.12 | §14.4.3 |
| Df method spread | 0.002–0.008 for one material across 4 methods | HDPUG 2015 | §14.4.3 |

### 2.3 Base-material thermal properties (Ch. 9–15)

| material / item | Tg (°C) | Td (°C) | other | source |
|---|---|---|---|---|
| Difunctional epoxy | < 120 | — | simple DS boards / blend component | §10.1.3 |
| Epoxy laminate bands | 125–145; 150–165; > 170; blends > 190 | — | — | §10.1.4 |
| FR-4 sheet 21 (IPC-4101) | ≥ 110 | — | — | §9.4.1 |
| Mainstream FR-4 | 130–140; 170–180 | — | — | §9.4.1 |
| Traditional dicy FR-4 (140 °C Tg) | 140 | 320 (5 %) | 1.5–3 % mass loss in lead-free window | §9.3.2, §11.2.4 |
| Dicy high-Tg FR-4 | ~175 | 290–310 (5 %); example 305 (1 %: 297, 2 %: 301) | not lead-free compatible | §11.2.4, §13.5.2 |
| Enhanced/phenolic high-Tg FR-4 | ~175 | 350 (5 %) one example; 330 (1 %: 326, 2 %: 328) another | lead-free compatible | §9.3.2, §13.5.2 |
| Low Dk/Df lead-free material | — | 405 (5 %); 336 (1 %); 367 (2 %) | gradual decomposition | §11.2.4, §13.5.2 |
| BT/epoxy | 180–220 | — | BGA substrates; brittle; higher moisture | §10.2.2 |
| Cyanate ester | ≈ 250 | — | moisture sensitive | §10.2.3 |
| Polyimide | 260 (pure) / 220 (toughened) | very high | moisture; avoid for new designs (Ch. 17) | §10.2.4, §17.5.2 |
| Filled lead-free FR-4 (TMA example) | 154.45 | — | α1 ≈ 45 ppm/°C; α2 ≈ 219 ppm/°C; 50–250 °C expansion 2.58 % | §11.2.1 |
| TMA example (Ch. 15) | 136.7 | — | z-CTE α1 ≈ 65 ppm/K; α2 ≈ 150 ppm/K | §15.5.2 |
| DSC example | 192.9 → 195.3 (rescan) | — | — | §15.5.2.1.2 |
| DMA example | 193.17 | — | 1 Hz tan δ peak | §15.5.2.1.3 |
| Copper | — | — | CTE ≈ 17 ppm/K | §15.5.2.2 |
| Table 13.3 comparisons | 175 °C-Tg C: 3.5 % total expansion; 150 °C-Tg B (reduced CTE): 3.4 % | — | — | §13.5.1 |
| HTE foil | — | — | elongation 4–10 % at 180 °C | §12.3.1 |
| Water vapour pressure | — | — | ≈ 400 psi @ 230 °C; ≈ 700 psi @ 260 °C | §13.5.3 |
| Solder alloys | — | — | Sn/Pb mp 183 °C, peak 230–235 °C; SAC mp ≈ 217 °C, peak ≤ 260 °C | §13.2 |

### 2.4 Glass fabric and foil data (Ch. 10, 12)

| item | value | source |
|---|---|---|
| Fabric counts (warp × fill) | 1067: 70 × 70; 1086: 60 × 60; 1080: 60 × 47 | §10.5.3 |
| Yarn example (US) | ECD 450-1/0: E-glass, continuous, D filament, 45,000 yd/lb, singles | §10.5.2.1 |
| Yarn example (SI) | EC5 11 1X2: 5 µm filament, 11 tex (g/km), 1×2 | §10.5.2.2 |
| Twist notation | 3.0S = 3 turns/in, S twist (up-left); Z = up-right | §10.5.2.1 |
| Common styles cited | 1017, 1027, 1035, 1037, 106, 1067, 1080, 1086, 2113, 2313, 2116, 3070, 3313, 1652, 1506, 7628 | §10.5.3 Figs. |
| Glass matte | chopped strands 1–2 in | §10.5.4.1 |
| Foil purity | ED ≥ 99.8 % (Ag as Cu); wrought ≥ 99.9 % | §10.6.4 |
| Wrought foil resistivity max | 0.155–0.160 Ω·g/m² | §10.6.4 |
| Thin HDI foils | 5, 9, 13 µm (3 µm emerging) | §12.3.3 |
| UTC for pattern plating | 1/8 or 1/4 oz | §2.8.2 |
| Foil barrier layers | several hundred Å (Zn/Ni/brass); passivation < 100 Å | §10.6.1 |
| VLP naming | VLP-2 = 2 µm average roughness | §10.6.1 |
| Thickness tolerance classes | A, B, C (micrometer, unclad); D (microsection); K, L, M (micrometer, clad) | §9.5 |
| Surface-quality inspection | worst 50 mm × 50 mm at 10×; measure with ≥ 4× (referee 10×); grade over 300 mm × 300 mm | §9.5 |
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

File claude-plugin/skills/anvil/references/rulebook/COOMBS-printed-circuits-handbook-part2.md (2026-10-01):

# Printed Circuits Handbook (7th ed.) — Anvil rulebook, Part 2 (Chaps. 20.4–37.8)

## 0. Citation

C. F. Coombs, Jr. and H. T. Holden (Eds.), *Printed Circuits Handbook*, 7th ed. New York, NY, USA: McGraw-Hill Education, 2016. ISBN 978-0-07-183395-0 (print), 978-0-071-83396-7 (eBook).

Chapter authors cited in this extraction: B. Hargin & M. I. Montrose (Ch. 20), S. Webb (Ch. 21), M. Jouppi (Ch. 22, 23; Ch. 23 edited from D. Edwards, 6th ed.), V. Solberg (Ch. 24, orig. D. Fritz), H. T. Holden (Ch. 25, 26, 27), M. Stickel (Ch. 28, 29), G. Parry (Ch. 30, 37), C. D. Dupriest & H. T. Holden (Ch. 31), M. Carano (Ch. 32), G. Milad (Ch. 33, 35), H. Nakahara (Ch. 34), D. A. Vaughan (Ch. 36).

**Chapters covered by THIS extraction (text lines 4050–8100 of 16154):** Ch. 20 §20.4 (differential signaling, from mid-section) through §20.10; Ch. 21 (Basics of PCB Design); Ch. 22 (Current Carrying Capacity); Ch. 23 (PCB Design for Thermal Performance); Ch. 24 (Embedded Components); Ch. 25 (Intro to HDI); Ch. 26 (Advanced HDI); Ch. 27 (CAM Tooling); Ch. 28 (Drilling); Ch. 29 (Precision Interconnect & Laser Drilling); Ch. 30 (Imaging & AOI); Ch. 31 (Multilayer Materials & Processing); Ch. 32 (Preparing Boards for Plating); Ch. 33 (Electroplating); Ch. 34 (Direct Plating); Ch. 35 (Surface Finishes); Ch. 36 (Solder Mask); Ch. 37 §37.1–§37.8 (Etching, partial).

**Chapters NOT read (assigned to other agents):** Ch. 1–19 and Ch. 20 §20.1–20.3 (lines 1–4049); Ch. 37 §37.8 (remainder) through Ch. 71 and Appendix (lines 8101–16154).

Note on figures/equations: the source is an eBook text extraction in which most equations, all figures and most tables appear only as the placeholder "Images" or a bare caption. Where an equation is a placeholder, the rule transcribes only the numeric anchors stated in prose (tagged `medium`/`low`, "eq. not in text"); where the prose gives enough worked numbers to reconstruct the equation, the reconstruction is checked against those numbers and tagged `medium`. Printed page numbers are not preserved in this extraction; citations use §chapter.section and figure/table numbers.

## 1. Design rules

| id | domain | rule statement | formula / limit (units) | inputs | applicability & conditions | verify by | source | conf |
|---|---|---|---|---|---|---|---|---|
| COOMBS-2001 | transmission-line | Differential pairs target the impedance most component vendors recommend for noise cancellation | Zdiff = 100 Ω or 85 Ω | Zdiff (Ω) | differential signaling (LVDS, SERDES) | calc | §20.4 | high |
| COOMBS-2002 | transmission-line | Loss is the principal SI concern for fast signals over long paths; ISI appears when degraded rise time ≈ bit period | f > 1 GHz AND length > 10 in (25.4 cm) → loss-dominated | f (GHz), length (in) | serial links | sim | §20.4.1 | high |
| COOMBS-2003 | transmission-line | Every multi-Gb/s SERDES link needs an end-to-end attenuation (link) budget | typical budget 10–15 dB end-to-end; lower with RX equalization | channel loss (dB) | multi-Gb/s SERDES | calc | §20.4.2 | high |
| COOMBS-2004 | transmission-line | Interconnect loss budget derived from TX/RX voltage levels (before pre-emphasis/equalization) | Attenuation_budget (dB) = 20*log10(V_RX,min / V_TX,min) | V_RX,min (V) receiver min input; V_TX,min (V) transmitter min output | SERDES channels | calc | §20.4.2, Ref. 15 (Johnson & Graham) | high |
| COOMBS-2005 | transmission-line | Budget BGA package loss at each end of channel | ≤ 0.5 dB per package end at f < 2 GHz; 0.8 dB per package at 3.0 GHz | f (GHz) | backplane/line-card channels | calc | §20.4.3 | high |
| COOMBS-2006 | connectors | Choose connectors with matched differential impedance so connector loss stays small | connector Zdiff = 85–100 Ω → loss "well under 3 dB" at target frequency | Zdiff (Ω), f_target | high-speed connectors | calc/measure | §20.4.3 | high |
| COOMBS-2007 | via | Budget via loss; mitigate with blind/buried vias, backdrilling, minimal/small pads, large antipads, nearby stitching vias/bypass caps | poorly designed via: 0.5–1.0 dB each at Gb/s; mitigated via: < 0.25 dB each | via count, stub length, pad count | Gb/s nets | sim | §20.4.3 | high |
| COOMBS-2008 | transmission-line | Below the crossover frequency (where dielectric loss begins to dominate), widening the trace reduces loss more than lowering loss tangent | applies for f < f_crossover | f, W (mil), Df | loss-budget trimming | sim | §20.4.4 | high |
| COOMBS-2009 | transmission-line | Reference loss anchors for 4.5-mil stripline (see §2 table T-20.25): 5.0 dB total at 4 GHz over 12 in (Er 3.75, Df 0.009) vs 10.0 dB over 17 in (Er 3.9, Df 0.02) | see T-20.25 | length (in), Er, Df, W | stripline, 4 GHz | sim | §20.4.4, Fig. 20.25 | high |
| COOMBS-2010 | materials | Standard-loss FR-4 (Df 0.02) has a crossover frequency ~75 % lower than low-loss material (Df 0.009) | 1.78 GHz vs 7.86 GHz for the two Fig. 20.25 cases | Df | material selection | sim | §20.4.4 | high |
| COOMBS-2011 | transmission-line | Channels with 12–18 dB loss are buildable inexpensively if TX pre-emphasis and RX equalization correct the loss, leaving margin for crosstalk/reflections; verify only by simulator including crosstalk & reflections | 12–18 dB channel loss with equalization | channel loss (dB) | SERDES | sim | §20.4.5 | high |
| COOMBS-2012 | pdn | PDN must hold rail ripple/fluctuation at or below target | ripple ≤ 5 % of V_rail | V_rail, ripple | all digital PDNs | sim/measure | §20.5.1, §20.5.3 | high |
| COOMBS-2013 | pdn | Lower Z_PDN by minimizing loop inductance and increasing capacitance: reduce loop area (incl. z), put power/return planes adjacent and close, widen conductors | Z = V/I (Ohm's law, time & frequency domain; Eq. 20.3 not in text) | stackup, loop geometry | PDN layout | sim | §20.5.2 | medium |
| COOMBS-2014 | decoupling | Bulk bypass capacitors hold DC voltage/current and are effective only at low frequency | bulk C = 1–1000 µF; useful up to ~10 MHz | C (µF) | PDN | calc | §20.5.3 | high |
| COOMBS-2015 | decoupling | Decoupling capacitors supply edge-transition charge up to a limited frequency; above that only plane-pair or on-die capacitance works | decoupling caps effective to ~200 MHz; plane pair/on-die above 200 MHz | f (MHz) | PDN | sim | §20.5.3 | high |
| COOMBS-2016 | decoupling | Capacitor impedance minimum is at self-resonance, where Z = ESR; above SRF the part is inductive and useless for local charge | f_SRF = 1/(2*pi*sqrt(L_mounted*C)) (Eq. 20.4 not in text; standard form); Z(f_SRF) = ESR | C (F), L_mounted = ESL + via/trace inductance (H), ESR (Ω) | discrete decoupling | calc | §20.5.4 | medium |
| COOMBS-2017 | decoupling | Paralleling N identical capacitors divides ESL and ESR and multiplies C | ESL_total = ESL/N; ESR_total = ESR/N; C_total = N*C | N, ESL, ESR, C | PDN | calc | §20.5.4 | high |
| COOMBS-2018 | decoupling | Mixing two capacitor values creates an antiresonance peak between their SRFs; check switching harmonics against it | example: 100 nF (SRF 16 MHz) ∥ 1 nF (SRF 170 MHz) → antiresonance at 120 MHz; harmonics of 10/20/30/40/60 MHz can radiate at 120 MHz | C1, C2, ESL, switching f | mixed-value decoupling | sim | §20.5.4, Fig. 20.30 | high |
| COOMBS-2019 | decoupling | Mounted inductance (ESL) of a decap = footprint (via placement vs pad, trace length/width) + distance to plane + plane spreading inductance; minimize all three for energy delivery below 200 MHz | ESL_mounted = L_footprint + L_via(distance to plane) + L_spreading (Fig. 20.31 values not in text) | via-to-pad distance, trace length, plane depth | discrete decaps | inspect/calc | §20.5.5 | medium |
| COOMBS-2020 | pdn | Plane-pair capacitance scales with area and dielectric constant and inversely with spacing | C = eps0*eps_r*A/d (Eq. 20.5 not in text; standard parallel-plate form) | A (m^2), d (m), eps_r | power/return plane pairs | calc | §20.5.5 | medium |
| COOMBS-2021 | pdn | Embedded power/return planes are the least-inductive charge source and take over where discrete caps go inductive | planes supply from ~150 MHz up into GHz; discrete caps cease at ~250 MHz upper limit | f | multilayer PDN | sim | §20.5.5 | high |
| COOMBS-2022 | materials | Standard FR-4 plane-pair capacitance density is limited; ultra-thin high-Dk laminates give 10–50× more | FR-4: min 2 mil, Dk ≈ 4.0, 49–68 pF/cm² (0.31–0.43 nF/in²); thin cores 8–14 µm (0.31–0.55 mil), Dk double-digit → 0.3–3.6 nF/cm² (2–23 nF/in²) | dielectric thickness, Dk | embedded capacitance | calc | §20.5.5, Table 20.2 (contents not in text) | high |
| COOMBS-2023 | return-path | Above 100 kHz all signals are RF: return current follows the path of least inductance, i.e., the reference plane directly under the trace; DC return follows least resistance | f > 100 kHz | f, stackup | all signal routing | inspect | §20.6.3 | high |
| COOMBS-2024 | emc | A conductive return path must exist with impedance below free space, otherwise free space becomes the return (radiation) | Z_return < 377 Ω | Z_return | all nets | calc | §20.6.3 | high |
| COOMBS-2025 | emc | Single-sided PCBs with digital components are unlikely to pass EMC unless edges are very slow and routes very short; add a 0 V reference plane (multilayer) | exception only if t_r/t_f > 1 µs and short routes | t_r, t_f, layer count | low-cost boards | review | §20.6.3 | high |
| COOMBS-2026 | return-path | Inductive reactance dominates trace impedance above 100 kHz; resistance can be ignored | X_L = 2*pi*f*L; example L = 100 nH, R = 10 mΩ: X_L = 630 mΩ @1 MHz, 63 Ω @100 MHz, 630 Ω @1 GHz (>377 Ω → radiates) | f (Hz), L (H) | return-path analysis | calc | §20.6.3, Eq. 20.6 | high |
| COOMBS-2027 | return-path | No high-speed digital signal (or power/return trace) may cross a slot, gap or split in its adjacent reference plane | crossings = 0 | trace routes, plane cutouts | all high-speed nets | inspect (DRC) | §20.6.4, Fig. 20.34 | high |
| COOMBS-2028 | grounding | Single-point grounding is only appropriate when all switching is slow; otherwise use multipoint (multiple connections to a single-point reference) | single-point OK only if all switching < 100 kHz–1 MHz | max switching f | grounding architecture | review | §20.6.8–20.6.9 | high |
| COOMBS-2029 | grounding | All ground/reference nets (digital, analog, chassis, ESD…) must eventually connect at one 0 V reference; PCB-to-chassis bonds via low-inductance standoffs, not wires | exactly one 0 V reference in system | net list of grounds | mixed systems | inspect | §20.6.9 | high |
| COOMBS-2030 | compliance | Protective-earth bond is legally mandated when hazardous voltage present | hazardous if V ≥ 42.2 VAC or ≥ 60 VDC (mains 115/230 VAC always hazardous) | V_max | product safety | review | §20.6.11 | high |
| COOMBS-2031 | compliance | AC/high-voltage traces must meet creepage (along insulation surface) and clearance (through air) distances from safety standards, plus ampacity/heating | creepage & clearance per applicable safety standard (Fig. 20.40 values not in text) | V, pollution degree, material group | hazardous-voltage nets | calc/inspect | §20.6.11 | high |
| COOMBS-2032 | mechanical | Provide at least two datums; the primary datum is a nonfunctional hole or surface feature, never an edge machined in a late secondary operation | ≥ 2 datums | fab drawing | all PCBs | inspect | §20.7.2, Fig. 20.41 | high |
| COOMBS-2033 | mechanical | Mechanically mounted assemblies are supported near the edge on at least three sides | support within 25 mm of edge on ≥ 3 sides | mounting geometry | mechanically mounted PBAs | inspect | §20.7.3 | high |
| COOMBS-2034 | mechanical | Support-interval limits by board thickness | 0.7–1.6 mm thick: support intervals ≤ 100 mm; > 2.3 mm: "1.3-mm intervals" [sic in text; likely 130 mm] | board thickness (mm) | mechanically mounted PBAs | inspect | §20.7.3 | high (text as printed) |
| COOMBS-2035 | mechanical | Steinberg max-deflection formula (mm units) predicts solder-joint life; compliant-lead parts tolerate ~2× the deflection of rigid packages | rated 10e6 stress reversals (sinusoidal) / 20e6 (random) (Eq. 20.7 not in text) | board L, thickness, component size/position | shock & vibration | calc | §20.8.1 | medium |
| COOMBS-2036 | mechanical | Fundamental (first) mode dominates fatigue; components at board center see max strain; raise f_n above the threat by clamped guides, ribs/stiffeners, extra mounts, snubbers | f_n from plate stiffness D (Eqs. not in text) | E, thickness, edge conditions | vibration design | sim | §20.8.2, Fig. 20.44 | low |
| COOMBS-2037 | requirements | Assign IPC performance class from end use | Class 1 general electronics; Class 2 dedicated service (uninterrupted service desired); Class 3 high reliability (military/medical, interruption may be life-threatening) | product use | all PCBs | review | §21.2.1 | high |
| COOMBS-2038 | dfm | Record IPC producibility level of the design | Level A general (preferred); Level B moderate (standard); Level C high complexity (reduced producibility) | feature sizes | all PCBs | review | §21.2.2 | high |
| COOMBS-2039 | process | Schematic conventions: flow left→right, inputs left/outputs right, power pins top, ground pins bottom, all pins of every symbol/gate shown, decoupling caps drawn next to their IC, connector pins at page edge | — | schematic | all designs | inspect | §21.3.1 | high |
| COOMBS-2040 | components | Footprint must carry: correct pad count/locations, solder-mask opening, paste opening, silkscreen outline, ref des, pin numbers, placement boundary, origin (pick point), orientation, part height | — | library | all footprints | inspect | §21.4.1 | high |
| COOMBS-2041 | components | Use an IPC land-pattern density level consistently (minimum / nominal / maximum) and IPC naming convention (type, lead span, size, height, pin count) | one level per library | library policy | SMT | review | §21.5 | high |
| COOMBS-2042 | components | For high-speed parts prefer packages with power and ground pins physically adjacent | — | package pinout | high-speed ICs | review | §21.5 | low |
| COOMBS-2043 | mechanical | Import board outline, holes, keepouts and connector positions from mechanical CAD (.dxf/.emn) onto a nonfunctional layer rather than redrawing | — | MCAD file | all PCBs | inspect | §21.6 | high |
| COOMBS-2044 | process | Database precision: metric boards 4 decimal places; imperial boards on 0.001 in grid with 2 decimal places | — | units | CAD setup | inspect | §21.6 | high |
| COOMBS-2045 | fab | Ask fabricator for their "normal" via/pad size and the smallest via hole without up-charge before setting default via | — | fab capability | all PCBs | review | §21.6 | high |
| COOMBS-2046 | stackup | Fix board thickness at project start; most common thickness 0.062 in; plan copper weights from current need | 0.062 in (1.6 mm) default | current, layer count | all PCBs | review | §21.6 | high |
| COOMBS-2047 | placement | Place BGAs on a grid of half the ball pitch; route on a quarter-pitch grid so fanout vias/traces are uniformly spaced | placement grid = pitch/2 (0.8 mm → 0.4 mm); routing grid = pitch/4 (0.2 mm) | ball pitch (mm) | BGA fanout | inspect | §21.7 | high |
| COOMBS-2048 | placement | Keep analog parts/signals in their own region, input→output "clothesline" order, no digital parts or traces in or through the analog region | digital crossings of analog region = 0 | placement regions | mixed-signal | inspect | §21.7, Fig. 21.16 | high |
| COOMBS-2049 | placement | Group each IC with its decoupling caps and termination devices so they move together | — | groups | all | inspect | §21.7 | high |
| COOMBS-2050 | placement | Part orientation (N-S vs E-W) no longer matters for modern pick-and-place | — | — | SMT assembly | review | §21.7 | high |
| COOMBS-2051 | placement | Group parts by logic family and voltage so one power layer can be split per voltage and signals stay within their region | — | supply nets | multilayer | inspect | §21.7 | high |
| COOMBS-2052 | return-path | Every power plane and every routing layer must have a return plane (normally ground) adjacent in the stack | — | stackup | all multilayer | inspect | §21.8 | high |
| COOMBS-2053 | grounding | Ground planes are never split; power planes may be divided into voltage regions; a signal returning on a power plane must have the same voltage as that region and not cross splits | ground splits = 0 | plane shapes | multilayer | inspect | §21.8 | high |
| COOMBS-2054 | stackup | Plane layers are solid copper, not cross-hatched | — | plane fill | multilayer | inspect | §21.8 | high |
| COOMBS-2055 | stackup | Prefer foil construction (foil + prepreg outer, cores alternating with prepreg inside): fewer cores and etch steps → lower cost | — | stackup | multilayer | review | §21.9 | high |
| COOMBS-2056 | stackup | Even number of layers with layer types mirrored about the centerline (balanced) to prevent warp; pour copper into open areas (tied to power/ground) to balance etch | layer count even; mirror symmetry | stackup | multilayer | inspect | §21.9 | high |
| COOMBS-2057 | pdn | Put a power/ground plane pair adjacent near the stack center with thin spacing for plane capacitance (not achievable in 4-layer) | plane pair spacing 0.003–0.010 in | stackup | ≥ 6-layer | inspect | §21.9 | high |
| COOMBS-2058 | stackup | At most two signal layers adjacent, and only with return planes on both sides; the outermost signal layer must have a plane beneath it (never two signal layers at the surface) | adjacent signal layers ≤ 2; outer signal layer must be plane-referenced | stackup | multilayer | inspect | §21.9, Fig. 21.19 | high |
| COOMBS-2059 | stackup | Any controlled-impedance stackup is coordinated with/checked by the fabricator (widths, spacing, dielectric distances) | — | stackup | controlled-Z boards | review | §21.9 | high |
| COOMBS-2060 | transmission-line | Even without a spec, control trace impedance layer-to-layer: pick one Z0 near 50–60 Ω and hold it on every layer (widths differ per layer) | Z0 target 50–60 Ω, same on all layers | stackup | all routing | calc | §21.10 | high |
| COOMBS-2061 | dfm | Trace width and spacing are generally equal; give any extra room to spacing; never use narrower traces than needed; check width fits between IC/BGA leads | space ≥ width | W, S, fab capability | all routing | inspect | §21.10 | high |
| COOMBS-2062 | routing | Fan out power connections to vias first; place BGA fanout early (X or + pattern so planes reach the BGA center) | — | BGA | dense boards | inspect | §21.10, Fig. 21.21 | high |
| COOMBS-2063 | routing | Use one grid (metric or imperial) for all fanout/via patterns so routing channels align | — | grid | dense boards | inspect | §21.10 | high |
| COOMBS-2064 | routing | Route the densest area (e.g., BGA escape) first; it sets layer count; establish a per-layer routing direction; adjacent signal layers route perpendicular | — | placement | multilayer | inspect | §21.10 | high |
| COOMBS-2065 | routing | Route critical/high-speed signals on internal layers; slower signals may use outer layers | — | net classes | multilayer | inspect | §21.10 | high |
| COOMBS-2066 | routing | Topologies: buses daisy-chain driver→loads; clocks star / branch-by-n; T-routing for lumped load groups | — | net classes | all | inspect | §21.10, Fig. 21.25 | high |
| COOMBS-2067 | routing | Routing order: 1 power fanout vias, 2 I/O, 3 critical nets, 4 lock criticals, 5 analog (isolated), 6 location-specific, 7 general | — | net classes | all | review | §21.10 | high |
| COOMBS-2068 | crosstalk | Same-bus signals switching together may be channelled at spacing = trace width; dissimilar signals at minimum spacing risk crosstalk | S_bus = W acceptable; S_mixed > minimum | W, S, net classes | bus routing | inspect | §21.10, Fig. 21.26 | high |
| COOMBS-2069 | dfm | Trace entry into a pad must not form an acute angle | entry angle ≥ 90° | trace/pad geometry | all | inspect (DRC) | §21.10 | high |
| COOMBS-2070 | assembly | Trace width entering a pad ≤ ~60 % of pad width (thermal balance during soldering) | W_trace ≤ 0.6 * pad size | W, pad | SMT pads | inspect (DRC) | §21.10 | high |
| COOMBS-2071 | routing | Do not route traces on power or ground layers (they cut the return region) | traces on plane layers = 0 | layer usage | multilayer | inspect | §21.10 | high |
| COOMBS-2072 | decoupling | Via decoupling caps and IC power pins directly to the planes whenever pin-to-cap distance exceeds the limit | via to plane if distance > 0.100 in | cap-to-pin distance | all | inspect (DRC) | §21.10 | high |
| COOMBS-2073 | emc | Keep high-speed traces away from board edges | — | edge distance | high-speed nets | inspect | §21.10 | low |
| COOMBS-2074 | routing | Use larger vias for power connections layer-to-layer | — | via sizes | power nets | review | §21.10 | low |
| COOMBS-2075 | crosstalk | Extra spacing around clocks/strobes and around differential pairs relative to other routing and vias | — | net classes | clocks, diff pairs | inspect | §21.10 | low |
| COOMBS-2076 | timing | Serpentine length-matching loops keep 3–4 trace widths between segments so the signal does not couple across loops | loop gap = 3–4 × W | W | length-matched nets | inspect (DRC) | §21.10 | high |
| COOMBS-2077 | routing | Do not route unrelated signals through a BGA area | — | BGA regions | dense boards | inspect | §21.10 | high |
| COOMBS-2078 | routing | Layer-paired routing: when changing direction, switch to the signal layer on the other side of the same reference plane to contain return current | — | stackup | high-speed | inspect | §21.10, Fig. 21.27 | high |
| COOMBS-2079 | process | DRC must be clean (any accepted exceptions documented); also check unconnected nets/pins, differential pairs, noisy-signal adjacency, same-net spacing | DRC errors = 0 (or documented) | DRC report | all | inspect | §21.11 | high |
| COOMBS-2080 | process | Resequence reference designators in a grid (left→right, top→bottom; top side then bottom), back-annotate to schematic, re-import netlist to confirm sync | — | ref des | all | inspect | §21.11 | high |
| COOMBS-2081 | dfm | Silkscreen text/ref des must not fall on pads or vias (it is clipped in fab); use leader lines if needed | silkscreen-on-pad = 0 | silkscreen | all | inspect (DRC) | §21.11 | high |
| COOMBS-2082 | fab | Drill schedule lists every hole size, its tolerance, plated/nonplated, and quantity | hole tolerance usually ±0.003 in | drill table | fab drawing | inspect | §21.11 | high |
| COOMBS-2083 | fab | Stackup drawing lists layer name, copper weight, plating amount, dielectric thickness between layers, and impedance where controlled | — | stackup | fab drawing | inspect | §21.11 | high |
| COOMBS-2084 | fab | Deliver Gerber / ODB++ / IPC-2581, IPC-D-356 netlist, pick-and-place files, fab & assembly drawings, file list and contact; verify each output layer against the database after translation | — | output set | fab release | inspect | §21.11 | high |
| COOMBS-2085 | process | Save a dated copy of the design database daily and at milestones; on completion archive read-only master on network | ≥ several days retained | — | all | inspect | §21.12 | high |
| COOMBS-2086 | reliability | Arrhenius rule of thumb: every 10 °C rise halves component life; every 10 °C reduction doubles it — keep electronics as cool as possible | life(T+10 °C) = 0.5·life(T) | T_component | all | calc | §22.1 | high (as stated; author notes "whether exactly true or not") |
| COOMBS-2087 | current-carrying | Size traces with IPC-2152 baseline charts (not the superseded IPC-2221/MIL-STD-275 charts); baseline = polyimide, 1.78 mm (0.07 in) thick, no internal planes, still air, per IPC-TM-650 2.5.4.1a | ΔT_trace = f(I, cross-section) from IPC-2152 baseline chart (charts are figures, not in text) | I (A), W, Cu weight, ΔT allowed | all current-carrying traces | calc | §22.1, §22.3 | high |
| COOMBS-2088 | current-carrying | Cross-sectional area is the dominant variable for trace temperature rise; copper weight has only a small effect for the same area (most noticeable at high ΔT) | — | W × t (sq mil) | trace sizing | calc | §22.2.1, §22.3.1 | high |
| COOMBS-2089 | current-carrying | The old IPC-2221 internal chart was simply the external chart at ½ current (not test data); measured internal traces run similar to but slightly cooler than external traces (2001–2004 tests) | I_internal,old = 0.5·I_external,old | — | legacy designs | review | §22.2.1 | high |
| COOMBS-2090 | current-carrying | Trace temperature rise increases as board gets thinner; correct baseline ΔT for board thickness | example 1 oz internal 0.0088-in-wide trace at 1 A: ΔT = 10 °C @0.070 in; 12.1 °C @0.059 in; 13.3 °C @0.038 in board | board thickness (in) | thin boards, flex | calc | §22.3.4 | high |
| COOMBS-2091 | current-carrying | Board thermal conductivity is secondary to board thickness; dielectric k ≈ 0.354 W/m·K vs air 0.026 W/m·K, so traces in free air have the least capacity | k_dielectric ≈ 0.354 W/m·K; k_air ≈ 0.026 W/m·K | material | trace sizing | calc | §22.2.1, §22.3.3, Table 22.2 | high |
| COOMBS-2092 | current-carrying | A nearby copper plane reduces trace ΔT significantly; effect grows as trace-to-plane distance shrinks; IPC-2152 plane charts (ideal plane, no cutouts) are for margin estimation, not sizing | ΔT decreases with decreasing trace–plane distance (Fig. 22.9, values not in text) | trace-to-plane distance, plane size | boards with planes | calc | §22.2.1, §22.3.2 | medium |
| COOMBS-2093 | current-carrying | In vacuum, traces run hotter than in air and internal ≈ external temperature | vacuum charts (Fig. 22.10, values not in text) | environment | space/vacuum | calc | §22.3.5 | high |
| COOMBS-2094 | current-carrying | Use end-product (after-processing) copper thickness when sizing, per IPC-2221 Table 10-1 minimum internal foil thickness and external conductor thickness (Tables 22.3/22.4) | finished Cu thickness ≥ IPC-2221 Table 10-1 minimum (values not in text) | Cu weight, plating | all | inspect | §22.3.6 | medium |
| COOMBS-2095 | current-carrying | Parallel-conductor rule: closely spaced conductors carrying current simultaneously are evaluated as one conductor with equivalent cross-section = Σ areas and equivalent current = Σ currents (include traces above/below and side-to-side) | A_eq = ΣA_i; I_eq = ΣI_i | conductor list | buses, parallel power traces | calc | §22.3.7 | high |
| COOMBS-2096 | current-carrying | Estimate I²R power loss of all simultaneously energized conductors early; if it is a significant fraction of board power, redesign before layout | P_traces = Σ I_i²·R_i; compare to P_board | I, R | all | calc | §22.3.7 | high |
| COOMBS-2097 | current-carrying | Neck-downs around connector pins and planes with many via cutouts/keepouts are hot-spot risks requiring a thermal analysis tool | — | geometry | power distribution | sim | §22.3.7 | high |
| COOMBS-2098 | current-carrying | High-current pulses can fuse traces earlier than steady-state charts predict; do not extrapolate charts to pulses | — | pulse current | pulsed loads | measure | §22.3.8 | low |
| COOMBS-2099 | current-carrying | Baseline charts remain more accurate when extrapolating to higher current and cross-section > 700 sq mil | > 700 sq mil | area | heavy copper | calc | §22.3 | high |
| COOMBS-2100 | thermal | θ_ja is not a constant: it varies ≥ 2× with PCB layout; do not compute T_j = T_a + θ_ja·P for modern systems (JEDEC JESD51-2 §1.1) | θ_ja variation factor ≥ 2 | θ_ja | all component thermal estimates | review | §23.1, Ref. 1 | high |
| COOMBS-2101 | thermal | The PCB acts as the component heat sink and can dissipate 60–95 % of thermal energy if: large spreading planes, sparse population, long traces from component pins, adequate card spacing | 60–95 % | layout | all | sim | §23.2 | high |
| COOMBS-2102 | thermal | Conduction: Q = k·A·(T2−T1)/L (Fourier, Eq. 23.2 not in text); Cu conductivity is ~3 orders of magnitude above polymers, so Cu layout dominates | k_Cu ≈ 386 W/m·°C (also cited 380); k_FR-4 ≈ 0.8 W/m·°C; via Cu 0.389 W/mm·°C | k, A, L | all | calc | §23.3.1, §23.3.3–23.3.4, §23.6.3 | high |
| COOMBS-2103 | thermal | Table 23.1 conductivities valid at ~23 °C; re-source temperature-dependent data for operation > 85 °C or < −25 °C | — | T_op | extreme temps | review | §23.3.1 | high |
| COOMBS-2104 | thermal | Lengthen and widen traces attached to hot component pins; SOIC-8 @1 W on single-layer 1.57 mm FR-4: device ΔT changes ~40 % with trace length; diminishing returns beyond ~15 mm trace length | trace length ≥ 15 mm to pins where SI allows | trace L, W | leaded/SOIC parts | sim | §23.3.1, Fig. 23.3 | high |
| COOMBS-2105 | thermal | Use thickest available foil plus thickest electroplating for thermal traces; route them directly to thermal vias, side rails, or thermal screw holes | — | Cu thickness | thermal paths | review | §23.3.1 | high |
| COOMBS-2106 | thermal | Thermal-plane structure: thermal landing (collection plate) under exposed pad → thermal vias → continuous buried plane (power or ground); optional bottom landing for indirect heat sink; isolation so vias do not short other planes | — | stackup | exposed-pad packages | inspect | §23.3.2, Fig. 23.4 | high |
| COOMBS-2107 | thermal | Always solder exposed pads / thermal balls to a thermal collection land connected by thermal vias to a plane; use θ_jc / θ_jp from vendor; fix "floating package" by optimizing paste volume, never by deleting the thermal pad solder | — | package data | exposed-pad, BGA thermal balls | inspect | §23.3.2 | high |
| COOMBS-2108 | thermal | Maximize thermal spreading plane area near the component; 12×12 mm CSP with 49 thermal balls improves θ_ja by ≥ 2× going from small to large plane | improvement ≥ 2× | plane area | CSP/BGA | sim | §23.3.2, Fig. 23.6 | high |
| COOMBS-2109 | thermal | A dielectric break in a thermal plane is catastrophic: 1 mm FR-4 gap ≈ 1000 mm of Cu in thermal resistance; a 0.25 mm isolation slot halfway across a plane caused 29 °C drop across the slot and +33 °C component temperature (7×7 mm device) | k_Cu/k_FR4 ≈ 1000 | plane cuts | thermal planes | sim | §23.3.2, Fig. 23.7 | high |
| COOMBS-2110 | thermal | Deliberate isolation cuts may segregate parts that tolerate high T_j (e.g., regulators at 150 °C) from digital parts, provided the copper to the hot parts still carries the current | — | T_j limits, currents | mixed power/digital | sim | §23.3.2 | high |
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

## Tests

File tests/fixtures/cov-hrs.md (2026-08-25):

# HRS — coverage fixture

HR-1 — 3V3 rail 3.3 V ± 3 %. verify: simulation
HR-2 — ripple ≤ 30 mV p-p. verify: simulation
HR-3 — board ≤ 50 × 40 mm. verify: inspection

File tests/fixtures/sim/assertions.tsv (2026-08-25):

id | measure | op | limit | units | corners | traces
A-1 | vout_avg | within | 3.3±3% | V | nominal | HR-1
A-2 | vripple | le | 0.030 | V | nominal | HR-2
A-3 | eff | ge | 0.85 | - | nominal | HR-3

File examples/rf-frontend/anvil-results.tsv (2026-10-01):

n | dimension | assertion | status | weight | evidence | traces
1 | documentation | HW-001 | not_run | 1
2 | documentation | HW-002 | not_run | 1
3 | documentation | HW-003 | not_run | 1
4 | documentation | HW-004 | not_run | 1
5 | documentation | HW-005 | not_run | 1
6 | commercial | HW-006 | not_run | 1
7 | system | HW-007 | not_run | 1
8 | system | HW-008 | not_run | 1
9 | system | HW-009 | not_run | 1
10 | system | HW-010 | not_run | 1
11 | system | HW-011 | not_run | 1
12 | system | HW-012 | not_run | 1
13 | documentation | HW-013 | not_run | 1
14 | documentation | HW-014 | not_run | 1
15 | documentation | HW-015 | not_run | 1
16 | documentation | HW-016 | not_run | 1
17 | documentation | HW-017 | not_run | 1
18 | documentation | HW-018 | not_run | 1
19 | documentation | HW-019 | not_run | 1
20 | documentation | HW-020 | not_run | 1
21 | documentation | HW-028 | not_run | 1
22 | documentation | HW-029 | not_run | 1
23 | documentation | HW-030 | not_run | 1
24 | documentation | HW-031 | not_run | 1
25 | manufacturing | HW-032 | not_run | 1
26 | manufacturing | HW-033 | not_run | 1
27 | manufacturing | HW-034 | not_run | 1
28 | documentation | HW-035 | not_run | 1
29 | documentation | HW-036 | not_run | 1
30 | documentation | HW-037 | not_run | 1
31 | commercial | HW-038 | not_run | 1
32 | documentation | HW-039 | not_run | 1
33 | documentation | HW-040 | not_run | 1
34 | documentation | HW-041 | not_run | 1
35 | documentation | HW-042 | not_run | 1
36 | documentation | HW-043 | not_run | 1
37 | documentation | HW-044 | not_run | 1
38 | documentation | HW-046 | not_run | 1
39 | documentation | HW-047 | not_run | 1
40 | commercial | HW-048 | not_run | 1
41 | documentation | HW-049 | not_run | 1
42 | documentation | HW-050 | not_run | 1
43 | documentation | HW-051 | not_run | 1
44 | manufacturing | HW-052 | not_run | 1
45 | manufacturing | HW-053 | not_run | 1
46 | compliance | HW-055 | not_run | 1
47 | compliance | HW-056 | not_run | 1
48 | compliance | HW-056-PLAN | not_run | 1
49 | compliance | HW-057 | not_run | 1
50 | compliance | HW-057-PLAN | not_run | 1
51 | compliance | HW-062 | not_run | 1
52 | compliance | HW-062-PLAN | not_run | 1
53 | compliance | HW-063 | not_run | 1
54 | compliance | HW-063-PLAN | not_run | 1
55 | compliance | HW-064 | not_run | 1
56 | compliance | HW-064-PLAN | not_run | 1
57 | compliance | HW-065 | not_run | 1
58 | compliance | HW-065-PLAN | not_run | 1
59 | compliance | HW-066 | not_run | 1
60 | compliance | HW-066-PLAN | not_run | 1
61 | compliance | HW-073 | not_run | 1
62 | compliance | HW-073-PLAN | not_run | 1
63 | electrical | AUTO-ERC | pass | 1 | evidence/AUTO-ERC.json
64 | layout | AUTO-DRC | pass | 1 | evidence/AUTO-DRC.json
65 | simulation | AUTO-SIM | pass | 1 | evidence/AUTO-SIM.json
66 | electrical | AUTO-CONNECTIVITY | pass | 1 | evidence/AUTO-CONNECTIVITY.json
67 | electrical | AUTO-RULES | pass | 1 | evidence/AUTO-RULES.json
68 | layout | AUTO-LAYOUT | pass | 1 | evidence/AUTO-LAYOUT.json
69 | electrical | AUTO-PDN | pass | 1 | evidence/AUTO-PDN.json
70 | simulation | AUTO-SI | pass | 1 | evidence/AUTO-SI.json
71 | electrical | AUTO-THERMAL | pass | 1 | evidence/AUTO-THERMAL.json
72 | simulation | AUTO-EM | not_run | 1
73 | compliance | AUTO-EMC | pass | 1 | evidence/AUTO-EMC.json
74 | manufacturing | AUTO-FACTORY | not_run | 1
75 | commercial | AUTO-COST | not_run | 1
76 | documentation | REQ-HR-001 | not_run | 1 |  | HR-001
77 | documentation | REQ-HR-002 | not_run | 1 |  | HR-002
78 | documentation | REQ-HR-003 | not_run | 1 |  | HR-003
79 | documentation | REQ-HR-004 | not_run | 1 |  | HR-004
80 | documentation | REQ-HR-005 | not_run | 1 |  | HR-005
81 | documentation | REQ-HR-006 | not_run | 1 |  | HR-006
82 | documentation | REQ-HR-007 | not_run | 1 |  | HR-007
83 | documentation | REQ-HR-008 | not_run | 1 |  | HR-008
84 | documentation | REQ-HR-009 | not_run | 1 |  | HR-009
85 | documentation | REQ-HR-010 | not_run | 1 |  | HR-010
86 | documentation | REQ-HR-011 | not_run | 1 |  | HR-011

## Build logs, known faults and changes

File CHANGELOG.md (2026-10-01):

# Changelog

## 0.7.0 — 2026-09-30

- Board truth: every board analysis reads the board through KiCad's Python (`anvil_pcb.py`: geometry,
  refilled zones, Board Setup stackup) and reports margin rows; releasing an intent table makes its check
  mandatory (AUTO-LAYOUT/SI/PDN/THERMAL/EM/EMC at G3, AUTO-SPARAMS at G4).
- `anvil_fields.py`: 2-D finite-volume field solver (Richardson-extrapolated; stripline/microstrip/CPWG/
  pairs, asymmetric coplanar gaps) and a layered board thermal solver.
- `layout` (IPC-2152, IPC-2221, Z0/Zdiff, return path, match, RF fence/stitching/keep-out), `si` (routed
  topology → ngspice), `pdn` (copper-derived capacitor mounting, cavity, VRM), `thermal` (layered copper,
  via barrels, Tj), `em` (openEMS FDTD from board copper: thirds-rule mesh, lumped ports and parts,
  Touchstone out), `sparams` (limits on VNA Touchstone files), `emc` (loop × trapezoid harmonics vs
  FCC/CISPR lines).
- `board` (schematic → footprints/nets on a template, symbol-linked for DRC parity), `place`, `route`
  (Freerouting on a copy + DRC); `doctor` reports numpy, KiCad Python, openEMS, Java/Freerouting.
- Rulebook completed (11,951 rules in 41 files): Balanis, Pozar, Paul, Williams, Pressman, Erickson, Johnson & Graham
  1993/2003, Ritchey, Wilson, Mitzner, Coombs, Horowitz & Hill and Scherz & Monk now mined in full.
- `tests/test_anvil_analysis.py`: analytic anchors for every solver and pass/fail on synthetic KiCad boards
  (CI installs numpy; KiCad/ngspice/openEMS cases skip when absent, openEMS is opt-in).
- `em` convergence and fidelity:
  - Capacitors are series ESR-ESL-C (ARCH-067 or `caps.tsv`). An ideal lumped C spread over mesh edges rang
    losslessly, so the energy never decayed.
  - Inductors are series L plus the ESR of their Q (default 50 at the band centre, column `l_q`). openEMS 0.37's
    lossless series inductor grows without bound, and its parallel R-L element diverges to NaN.
  - The model region follows the signal path and the listed parts, and a support net (a bias feed) is cut at its
    edge.
  - A run whose energy turns NaN or whose port signals are not finite is rejected as diverged; openEMS
    otherwise reports it as having met the end criterion.
  - Only the analysed and reference nets are modelled.
  - The pulse covers only the analysed band.
  - The default end is −50 dB, and a `<name>:settled` row fails when dropping the last 10 % of the run still moves
    a checked S by more than 0.01.
  - Ports sit where the pin or lead enters the pad. Over a launch cut-out they drive the coplanar gaps
    (validated against the 2-D solver on a CPW), because a tall vertical port adds inductance.
  - The fine mesh follows the signal path, not a narrow bias feed.
- Receipts bind the whole checker (`anvil.py` and every `anvil_*.py` module): a changed analysis
  invalidates the receipts it produced.
- `report`: the IEEE paper includes every verification figure, keeps each check's tightest margin, wraps long
  columns in full-width tables and compiles cleanly (symbols such as <=, |, Ω and λ escaped; BibTeX author lists).
  `log research` now writes `audit/research.tsv`, the ledger the report reads (it wrote `researchs.tsv`);
  decisions and research rows get D-n / SRC-n IDs.
- `layout` return path ignores trace length inside the net's own pads (a launch cut-out under a pad is deliberate);
  `rules` `capacitor_reactance` takes the body ESL (above self-resonance a capacitor is an inductor).
- `examples/rf-frontend`: a 4-layer 2.4 GHz gain block + 25 MHz clock taken from requirements to recorded
  G3 evidence for ten automatic checks (ERC, DRC, simulation, connectivity, rules, layout, PDN, SI, thermal,
  EMC). `rf_in` passes in openEMS (S11 −17.1 dB, S21 −0.21 dB); AUTO-EM is not yet recorded.
- Known issue: the `rf_out` bias-tee model diverges in openEMS 0.37 with any series-type lumped part (choke or
  capacitors) on that board, even though the same elements are stable in isolation. The cause is under
  investigation; diverged runs are rejected, not reported.

## 0.6.0 — 2026-09-29

- Rulebook: ~6,900 cited rules from the reference library in `references/rulebook/` (INDEX marks partial
  books) plus `bibliography.json` (IEEE strings, rule-id prefixes). Extraction brief kept in `research/`.
- `anvil_rules.py` cited calculations and the `rules` gate check / `calc` CLI. Fixed against the sources:
  Onderdonk fusing time (33.5, divides; Brooks §12) and IPC-2221 Table 6-1 A5 column (Mitzner Table 6.8).
- `anvil_schematic.py`: wired `.kicad_sch` from a golden `sch/circuit.json` (maze-routed orthogonal wires,
  power symbols, labels, NC flags), proven by KiCad reload + netlist equality + ERC; `schematic-spec`
  converts existing label-only drawings. `connectivity` gains a `golden` assertion.
- `anvil_netlist.py` (fresh-netlist wiring assertions, `wiring` tables), `anvil_plots.py` (ngspice rawfile
  corner plots, margin charts), `renders`, `fabpack`, `log`, `report` (audit + IEEE paper skeleton).
- New optional project tables `sch/connectivity.tsv`, `design/rules.tsv`, `sim/plots.tsv`; AUTO-CONNECTIVITY
  and AUTO-RULES join the plan when their artifact roles are declared.

Native Codex packaging is included in 0.5.0: an installable `$anvil` skill, local marketplace,
shared workflow routing, bundled tools/templates, and parity checks for both host packages.

## 0.5.0 ? 2026-09-14

- Implement the lifecycle research: all 75 checklist items, 19 early applicability checkpoints, G0?G7 plus sustaining, and a new lifecycle command. Distinguish PCB, assembly, product-build, design, production and market readiness.
- Replace score-derived release verdicts with required checks, exact requirement traces, method checks, review/NA dispositions, hashed release manifests and validated handoffs.
- Replace duplicated Bash/Node parsers with one Python standard-library seam. Fail closed on stale/invalid KiCad reports, failed or skipped simulations, missing corners, malformed numbers, mixed currencies, source drift and incorrect wiring. Correct curved outline bounds and degenerate mesh checks.
- Add firmware/build record, factory traceability/yield, full cost-model checks and templates; concurrent firmware, manufacturing, sector/market, commercial, support and retirement workflows.
- Bundle scripts, Windows doctor shim and all templates; align package versions and add executable regression/native-tool/installation checks. Remove unsupported manufacturer presets and universal engineering thresholds.
- Breaking migration: release claims require anvil-project.json, structured requirements, explicit evidence receipts and gate. Legacy score ledgers and SKIP_NGSPICE cannot authorize release; sim rows need circuit, product BOM needs pinned source joins, and ICDs need exact endpoints and qualified ratings. See README.

## 0.4.0 — 2026-08-26

Industry-process deepening — the protocols absorb the standard PCB design discipline (IPC
standards hierarchy, class election, grounding/PDN doctrine, obsolescence reality) from a
comprehensive process research pass.

- **New reference `standards.md`** — the numbers annex all protocols cite: IPC registry with
  current revisions (2221C, A-610J, 6012F, J-STD-020F…), **Class 1/2/3 gradient** (plating
  20/25 µm, barrel fill 50/75 %, annular-ring tolerance), IPC-2152 ampacity anchors (+ internal
  50–70 % derate), IPC-2221 Table 6-1 creepage/clearance anchors + >500 V formula + IEC
  60664-1/62368-1 override rule, IPC-7351 density levels, full MSL floor-life ladder,
  RoHS 3 / REACH-SVHC / UL 796 / 94V-0, and the obsolescence numbers (>50 % of EOLs ship
  with no PCN; LTB ≈ 6 months). Provenance caveat: secondary-source transcriptions — verify
  against the purchased standard for Class 3 / safety-critical.
- **IPC class is now a first-class early decision**: elected in the HRS manufacturing domain,
  fixed in the Phase 1 charter alongside requirements + stackup (the three early
  irreversibles), carried as `ipc_class` in `build-spec.yaml`, echoed on the DFM report and
  RFQs with the standard revision.
- **Schematic protocol**: sheet/naming conventions (hierarchy by function, IEEE 315/ASME
  Y14.44 refdes, scoped net labels, power ports, AGND/DGND single join drawn); IPC-7351
  Level-B footprint discipline (datasheet-verified, project-local pinned libs); quiet-
  obsolescence rules (active refresh checks, PCN/LTB = drop-everything issue, FFF alternate
  noted per keystone part); SWD/JTAG + boundary-scan row in the design review.
- **Layout protocol**: grounding doctrine section (one continuous plane, splits only with
  simulated justification, no routing over plane gaps, loop-area discipline, converter
  AGND/DGND per datasheet); stackup physics (thick 4-layer core carries no HF decoupling —
  MLCCs do; 6-layer thin PWR–GND pair; fab's real dielectrics for impedance); decoupling as
  loop inductance (≤ 2 mm, ~0.5–1 nH per via) + PDN target-Z formula; assembly-orientation +
  fiducial placement rules; thermal-via farm spec (Ø 0.2–0.33 mm @ 1.0–1.2 mm, must land on
  real copper); skew serpentines at the mismatch source; teardrops + mask-sliver rules.
- **Fab protocol**: DFM report grows IPC-class statement, reasoned surface-finish selection
  (HASL/ENIG/OSP/imm-Ag trade table, fine-pitch forces ENIG-class), symmetric-panel note,
  segmented-stencil rule for uncapped via farms, MSL ≥ 3 disclosure, declared-market
  compliance rows (RoHS/UL); IPC-2581 offered alongside RS-274X; PCN/LTB handling on the
  catalog refresh event.
- `build`: charter fixes the three early irreversibles; TEST-PLAN ordered up the DFT ladder
  (structural → boundary-scan → functional); DFM-report scope widened. `requirements`:
  class election in the manufacturing elicitation domain. Metrics: manufacturing/testability
  "owns" lines updated. `buck-3v3` exemplar spec carries `ipc_class: 2`.

End-to-end product capability — anvil builds assemblable units, not just boards. A rugged FPV
drone's frame, COTS modules, wiring, budgets, and assembly kit are now first-class, gated
deliverables (E2E capability 7/30 → 30/30 by `scripts/score-e2e-capability.sh`).

- **Five new protocol contracts** (`skills/anvil/references/`): `system-protocol.md`
  (product decomposition, ICD, system goldens, budgets), `cots-protocol.md` (pinned module
  catalog, datasheet-anchored selection), `mechanical-protocol.md` (CAD-as-code —
  build123d/CadQuery, kernel-emitted `measures.json`, process floors, rugged rules),
  `harness-protocol.md` (wire table, ampacity floor, mates), `assembly-protocol.md`
  (technician-followable steps, integration ladder, QC).
- **Seven new mechanical-truth gates** in `score-anvil.sh`, all fixture-tested
  (`tests/mech.test.sh`, `tests/system.test.sh`): `mesh` (STL watertight/manifold defect
  count), `fit` / `mass` / `mech-dfm` (kernel measures vs assertion classes; optional
  `PRUSA_SLICER` slice-clean seam), `pinout` (harness ↔ ICD + AWG ampacity), `product-bom`
  (full-unit cost+mass rollup, incomplete line = hard error), `sys-budget`
  (demand ≤ capability × derate).
- **Scoring contract**: product dims `mechanical` 0.20 · `integration` 0.15 · `system` 0.15,
  renormalized, must-pass in `verdict`; product optimization metrics `product_cost`,
  `auw_mass`, `worst_budget_margin`.
- **`build` product track**: P1 system architecture (extends P4) → P2 mechanical capture →
  P3 interconnect → P4 product roll-up + assembly package; `doctor.sh --require-product`
  (build123d/cadquery kernel tier, trimesh/prusa-slicer/openscad optional).
- **Requirements protocol**: rugged/environment domains (IP class, vibration profile,
  shock/drop) + product must-be rows + `product:` spec block.
- **Reference product spec** `evals/product/fpv-drone.spec.yaml`; project template grows the
  product tree (`system/ cots/ mech/ harness/ assembly/ product-bom.csv`).
- New harness self-gate: `scripts/score-e2e-capability.sh` (frozen scorer, 30 rows).

## 0.2.1 — 2026-08-26

Windows entry-point fix (found by the first fresh-clone user).

- **`scripts\doctor.cmd`** — from PowerShell/cmd, bare `bash` resolves to the WSL relay stub in
  System32 and dies with `execvpe(/bin/bash) failed` when no distro is installed. The shim
  locates Git for Windows' bash (ANVIL_BASH override → `where git` → standard install paths) and
  never falls back to the stub.
- `.gitattributes`: `*.cmd eol=crlf` (batch files need CRLF); README quick start + toolchain.md
  document the PowerShell path.

## 0.2.0 — 2026-08-26

Claude Code plugin packaging — installable in any repo.

- **Plugin tree** `claude-plugin/` (commands + skill + references + the three gate scripts at
  `skills/anvil/scripts/` so `${CLAUDE_PLUGIN_ROOT}` seam resolution works in installed repos)
  and marketplace manifest `.claude-plugin/marketplace.json` — install with
  `/plugin marketplace add Jss-on/anvil`, then install `anvil`.
- **Bare `/anvil` command** — classic metric loop (`Metric:`/`Verify:` with the hardware
  ratchet: ERC/DRC/sim gates hold whatever the metric rewards), build routing, setup wizard.
- **`scripts/sync-plugin.sh`** — canonical `.claude/` → `claude-plugin/` as pure byte copies with
  orphan pruning; `--check` mode is the parity gate (test 11, runs in CI). Mirrors are never
  transformed — divergence hides until an install breaks.

## 0.1.0 — 2026-08-26

Initial release: AutoForge's hardware sibling.

- **Core loop** ported to electronics design: modify → verify (ERC → derating → sim → DRC) → keep/discard, git as memory.
- **Six weighted acceptance dimensions** with a gating `electrical` dimension (ERC = 0 + connectivity golden cases + derating + power budget; any red row caps pass-rate at 0.50) — the hardware analog of AutoForge's `logic` gate.
- **Commands:** `/anvil:build` (8-phase gated pipeline, requirements → fab package), `/anvil:requirements` (HRS elicitation, every spec measurable), `/anvil:improve` (cost/area/margin optimization under a non-regression ratchet), `/anvil:evals` (trend analysis).
- **Mechanical gates:** `scripts/score-anvil.sh` (pass-rate · coverage · erc · drc · sim · bom-cost · area · verdict), `scripts/doctor.sh` (toolchain check), `scripts/validate-handoff.sh`.
- **References:** hardware-requirements, schematic, simulation, layout, fab protocols + metrics contract + toolchain guide.
- **Eval:** `evals/hardware/buck-3v3.spec.yaml` (USB-powered 5V→3.3V/1A buck, JLCPCB 2-layer).
- **Templates:** project scaffold, sim assertions example, JLCPCB 2-layer `.kicad_dru` rule deck.
- **Safety:** ordering parts / submitting fab jobs always human-gated; HV register (nets > 30 V) adds IPC-2221 creepage/clearance rows requiring human review.

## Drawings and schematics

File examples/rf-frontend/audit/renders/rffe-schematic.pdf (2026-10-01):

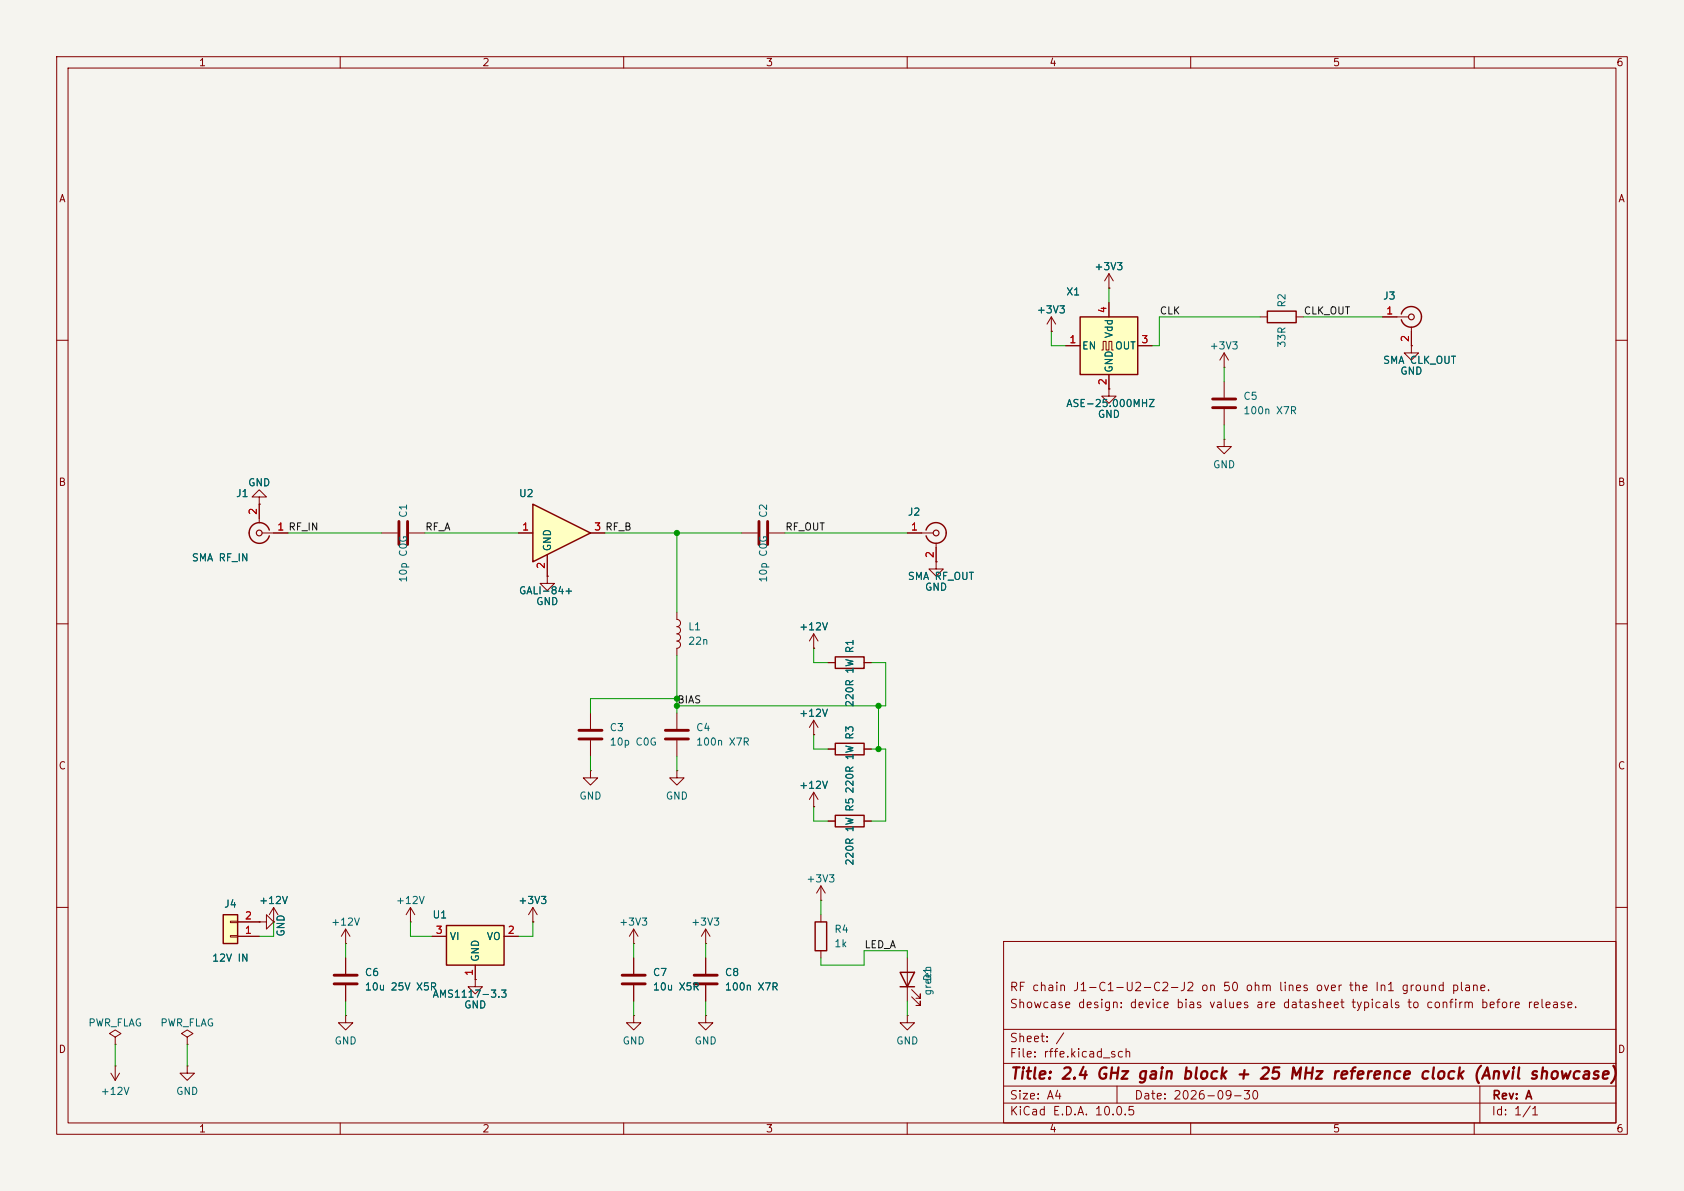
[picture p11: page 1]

RF chain J1-C1-U2-C2-J2 on 50 ohm lines over the In1 ground plane. +12V

Showcase design: device bias values are datasheet typicals to confirm before release.

Sheet: /
File: rffe.kicad_sch
Title: 2.4 GHz gain block + 25 MHz reference clock (Anvil showcase)

Size: A4 | Rev: A
KiCad E.D.A. 10.0.5 | Id: 1/1

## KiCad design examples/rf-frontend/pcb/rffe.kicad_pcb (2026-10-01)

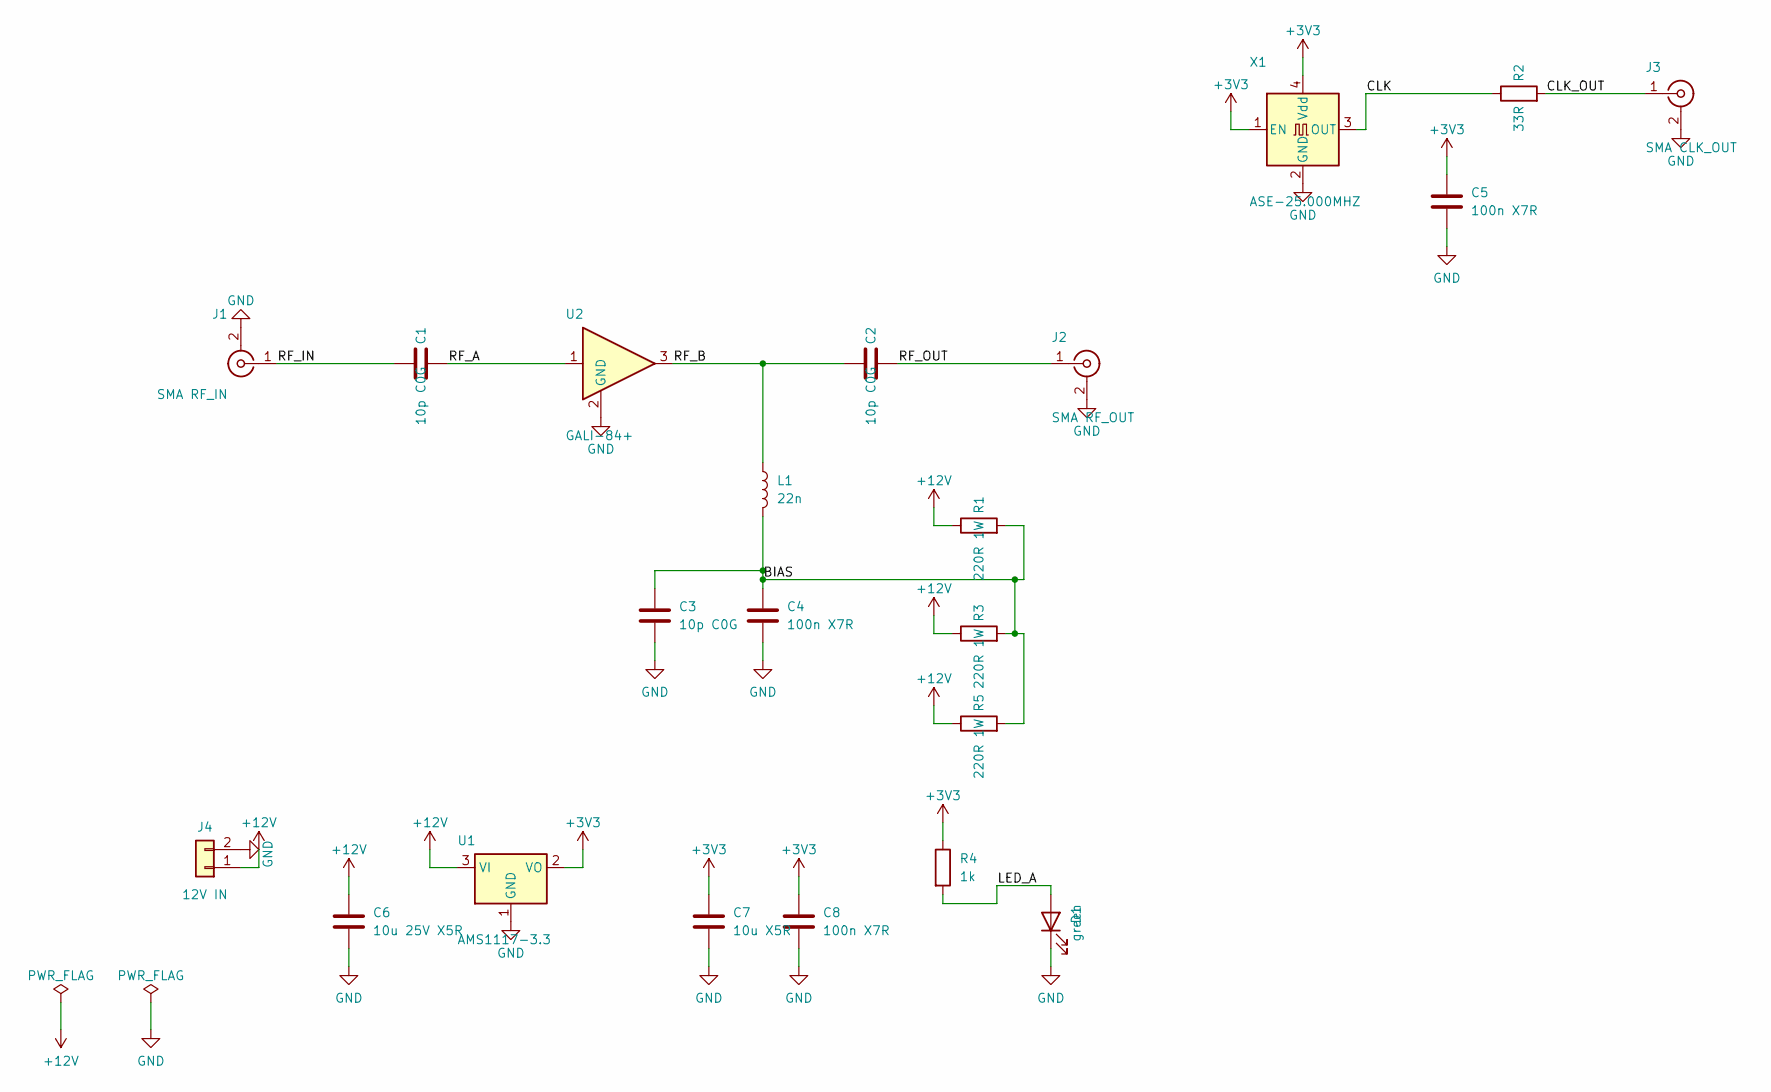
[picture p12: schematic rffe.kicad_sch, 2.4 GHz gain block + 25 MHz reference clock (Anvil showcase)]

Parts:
C1, C2, C3: 10p C0G; C_0402_1005Metric
C4, C5, C8: 100n X7R; C_0402_1005Metric
C6: 10u 25V X5R; C_0805_2012Metric
C7: 10u X5R; C_0805_2012Metric
D1: green; LED_0603_1608Metric
J1: SMA RF_IN; SMA_Amphenol_132289_EdgeMount
J2: SMA RF_OUT; SMA_Amphenol_132289_EdgeMount
J3: SMA CLK_OUT; SMA_Amphenol_132289_EdgeMount
J4: 12V IN; JST_PH_B2B-PH-K_1x02_P2.00mm_Vertical
L1: 22n; L_0603_1608Metric
R1, R3, R5: 220R 1W; R_2512_6332Metric
R2: 33R; R_0402_1005Metric
R4: 1k; R_0402_1005Metric
U1: AMS1117-3.3; SOT-223-3_TabPin2
U2: GALI-84+; SOT-89-3
X1: ASE-25.000MHZ; Oscillator_SMD_Abracon_ASE-4Pin_3.2x2.5mm

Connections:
+3V3: C5.1, C7.1, C8.1, R4.1, U1.2 (VO), X1.1 (EN), X1.4 (Vdd)
+12V: C6.1, J4.1, R1.1, R3.1, R5.1, U1.3 (VI)
/BIAS: C3.1, C4.1, L1.2, R1.2, R3.2, R5.2
/CLK: R2.1, X1.3 (OUT)
/CLK_OUT: J3.1 (In), R2.2
/LED_A: D1.2 (A), R4.2
/RF_A: C1.2, U2.1
/RF_B: C2.1, L1.1, U2.3
/RF_IN: C1.1, J1.1 (In)
/RF_OUT: C2.2, J2.1 (In)
GND: C3.2, C4.2, C5.2, C6.2, C7.2, C8.2, D1.1 (K), J1.2 (Ext), J2.2 (Ext), J3.2 (Ext), J4.2, U1.1 (GND), U2.2 (GND), X1.2 (GND)

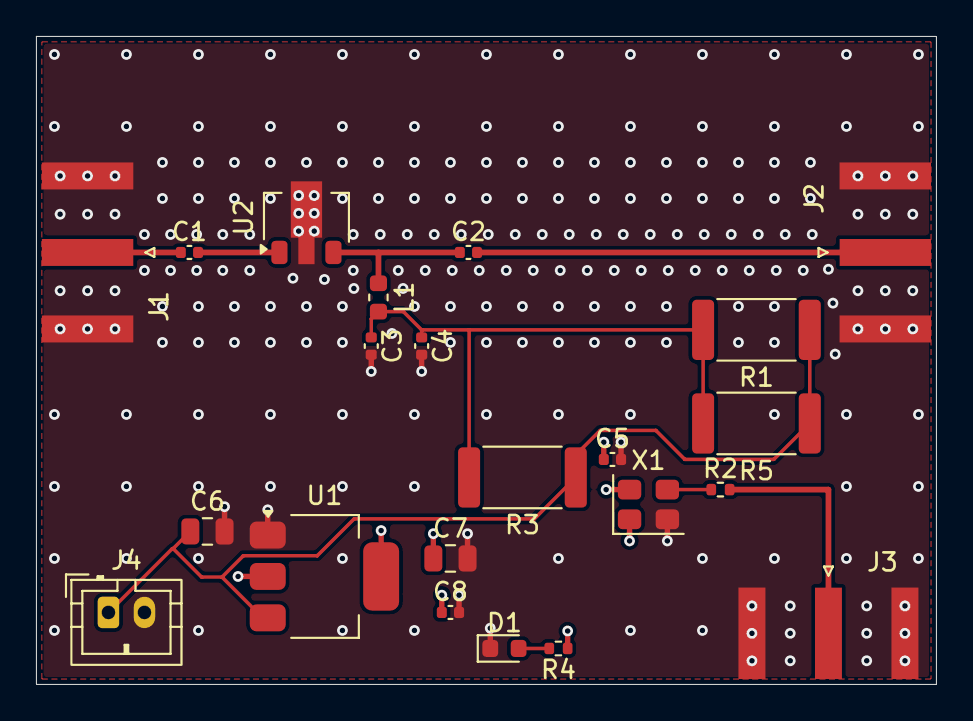
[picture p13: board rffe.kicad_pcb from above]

Board: 4 copper layers, 50.0 x 36.0 mm, 22 parts (0 on the bottom side), 11 nets.

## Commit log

2026-08-25 feat: anvil v0.1.0 — hardware forge harness, requirements to fab-ready PCB
    AutoForge's hardware sibling. Same loop discipline (modify → verify →
    keep/discard, git as memory) with electronics-correct mechanical gates:
    - Six weighted acceptance dimensions; gating electrical dimension
    (ERC=0 + connectivity goldens + derating + power budget) caps
    pass-rate at 0.50 while red — the hardware analog of forge's logic gate
    - Commands: /anvil:build (8-phase gated V-model pipeline),
    /anvil:requirements (HRS, every spec measurable), /anvil:improve
    (cost/area/margin optimization under non-regression ratchet), /anvil:evals
    - score-anvil.sh: pass-rate, coverage (RTM), erc/drc (kicad-cli JSO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
    [assertions.tsv, bom.csv, cov-results.tsv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]
2026-08-25 feat: Claude Code plugin packaging — installable via marketplace add Jss-on/anvil
    - claude-plugin/ distributable tree (commands, skill, references, gate
    scripts at skills/anvil/scripts/ for CLAUDE_PLUGIN_ROOT seam resolution)
    - .claude-plugin/marketplace.json + plugin.json manifests
    (claude plugin validate: passed)
    - bare /anvil command: classic metric loop with hardware ratchet
    (ERC/DRC/sim gates hold regardless of metric), build routing, wizard
    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
2026-08-25 fix: Windows doctor entry — scripts\doctor.cmd shim (bare bash = WSL stub trap)
    From PowerShell/cmd, `bash scripts/doctor.sh` resolves to the WSL relay
    stub in System32 and fails with 'execvpe(/bin/bash) failed' when no distro
    is installed. doctor.cmd locates Git for Windows' bash (ANVIL_BASH
    override, then via 'where git', then standard install paths) and never
    falls back to the stub. .gitattributes pins *.cmd to CRLF. v0.2.1
2026-08-26 feat: E2E product-capability scorer (frozen) — baseline 7/30
    score-e2e-capability.sh measures how much of the full-product pipeline
    (electronics + mechanical + COTS integration + wiring + product BOM +
    assembly) the harness can mechanically verify. 30 rows: CORE regression
    guards green, MECH/SYS/PROD red. Frozen: improvement loop scope excludes
    this file.
2026-08-26 experiment: mechanical protocol — CAD-as-code contract (build123d/CadQuery), measures.json, mesh/fit/mass/dfm gate semantics, process floors, rugged rules
2026-08-26 experiment: system protocol — product decomposition, ICD, system goldens, budgets, multi-board orchestration
2026-08-26 experiment: COTS protocol — pinned module catalog, datasheet-anchored selection, compatibility goldens, budget/BOM feeds
2026-08-26 experiment: harness protocol — from-to wire table, ampacity floor, mate table, loom/RF/strain rules, pinout gate semantics
2026-08-26 experiment: assembly protocol — technician-followable steps, BOM-id orphan checks, integration ladder, config artifacts, QC
2026-08-26 experiment: requirements protocol — rugged/environment domains (IP, vibration, shock/drop), product must-be rows, product: spec block
2026-08-26 experiment: mesh gate — STL watertight/manifold defect count (open, non-manifold, winding, degenerate) + fixtures + mech test harness
    [cube-good.stl, cube-open.stl]
2026-08-26 experiment: fit gate — kernel measures vs fit-class assertions (interference, clearance, boss alignment), shared mech evaluator
    [assertions.tsv]
2026-08-26 experiment: mass gate — mass-class assertions vs kernel measures (budget rows)
2026-08-26 experiment: mech-dfm gate — dfm-class assertions plus optional PRUSA_SLICER slice-clean seam
2026-08-26 experiment: pinout gate — harness/ICD consistency, ampacity floor, endpoint grammar, unrealized-interface + mate coverage checks
    [harness-bad.tsv, harness-good.tsv, icd.tsv]
2026-08-26 experiment: product-bom gate — full-unit cost+mass rollup across pcb/cots/mech/fastener/wire, incomplete lines are hard errors
    [product-bom-bad.csv, product-bom-good.csv]
2026-08-26 experiment: sys-budget gate — demand ≤ capability × derate per budget row (mass/power/endurance/cost), margins logged
    [budgets.tsv]
2026-08-26 experiment: doctor — PRODUCT tier (build123d/cadquery kernel, trimesh, prusa-slicer seam, openscad), --require-product flag
2026-08-26 experiment: scoring contract — product dims mechanical/integration/system (weights, renormalization, must-pass verdict), SKILL + metrics updated
    [product-results.tsv]
2026-08-26 experiment: build product track — P1 system architecture, P2 mechanical capture, P3 interconnect, P4 rollup + assembly package, product-mode dispatch + doctor tier
2026-08-26 experiment: fpv-drone product exemplar spec — carrier PCB + COTS propulsion/video, mech furniture assertions, budgets, environment block
2026-08-26 experiment: project template — product tree (system/cots/mech/harness/assembly, product-bom) + product gate crib
2026-08-26 experiment: README — end-to-end product scope (enclosure/COTS/harness/assembly gates, product mode, drone exemplar)
2026-08-26 feat: end-to-end product capability — v0.3.0
    Anvil now builds assemblable products, not just boards: system decomposition
    + ICD, COTS module selection, mechanical CAD-as-code track (mesh/fit/mass/
    mech-dfm gates), wiring harness (pinout gate), product BOM rollup, closing
    system budgets, and a technician-followable assembly package — all
    fixture-tested and must-pass in the weighted acceptance.
    E2E capability 7/30 -> 30/30 (scripts/score-e2e-capability.sh, frozen).
2026-08-26 feat: industry-process deepening — standards annex + class election + grounding-PDN doctrine — v0.4.0
    Absorb the standard PCB design process (IPC hierarchy, Class 1-2-3, grounding
    consensus, obsolescence reality) into the protocol contracts:
    - New standards.md reference: IPC registry w/ revisions, class gradient
    (plating, fill, annular), IPC-2152 ampacity anchors, IPC-2221 Table 6-1
    creepage-clearance anchors + over-500V formula + IEC 60664-1 and 62368-1
    override, IPC-7351 density levels, MSL ladder, RoHS3, REACH, UL, PCN-LTB
    - IPC class = first-class early decision: HRS domain 8, charter three
    irreversibles (requirements, class, stackup), build-spec ipc_class field,
    DFM repor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
2026-09-13 feat: add evidence-backed hardware lifecycle and native Codex plugin
    Release Anvil 0.5.0 with G0-G7 workflows, revision-bound verification, firmware and manufacturing checks, and the supporting research report.
    Package shared workflows for Claude Code and Codex, document installation, and validate isolated payloads with regression and parity checks.
    [assertions.tsv, budgets.tsv, change-register.csv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]
2026-10-01 feat: board-truth analyses, cited rulebook and rf-frontend showcase (v0.7.0)
    0.6.0
    - Cited rulebook: 11,951 rules from the reference library (41 files) plus
    bibliography.json; anvil_rules cited calculations and the rules gate check.
    - Wired KiCad schematics from sch/circuit.json, netlist/connectivity checks,
    corner plots, renders, fabpack, audit report and IEEE paper skeleton.
    0.7.0
    - Board analyses on the real KiCad board through KiCad's Python: layout
    (IPC-2152/2221, field-solved Z0, return path, RF fence/stitching), SI
    (ngspice), PDN, thermal, EMC estimate, openEMS EM and VNA s-params. Released
    intent tables make each check mandatory (G3, s-params G4).
    - 2-D finite-volume field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
    [anvil-results.tsv, assertions.tsv, budgets.tsv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]
2026-10-01 fix: store the rf-frontend example byte-exact so its hashed evidence verifies on any clone
    Receipts and the release manifest bind exact file bytes; LF normalisation of the CRLF files Anvil wrote on Windows would make a fresh checkout fail its own gate.
    [rffe-B_Cu.gbr, rffe-B_Mask.gbr, rffe-B_Paste.gbr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]
